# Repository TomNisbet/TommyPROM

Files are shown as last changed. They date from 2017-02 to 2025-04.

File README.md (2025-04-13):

# TommyPROM - An Arduino-based EEPROM programmer

This is a simple EEPROM programmer and reader that can be assembled using an Arduino and a
few additional parts.  The original code was specific to the 28C256 32Kx8 EEPROM, but it
has been extended to also support SST39SF040 Flash, many other EEPROMs and flash, and even
Intel 8755A EPROMS.

See the [documentation pages](https://tomnisbet.github.io/TommyPROM/) for the full
documentation with software, schematics, and troubleshooting tips.

Features include:
* Simple hardware design that can be assembled on a breadboard.
* ROM images transfers using XMODEM - no special host client needed.
* Support for fast block EEPROM writes - a 32K EEPROM will program in just a few seconds.
* Optimized code that supports the timing requirements needed to unlock the 28C series
[Software Protection Algorithm](https://tomnisbet.github.io/TommyPROM/docs/28C256-notes).
* Modular software design to easily support other EEPROM and EPROM families.

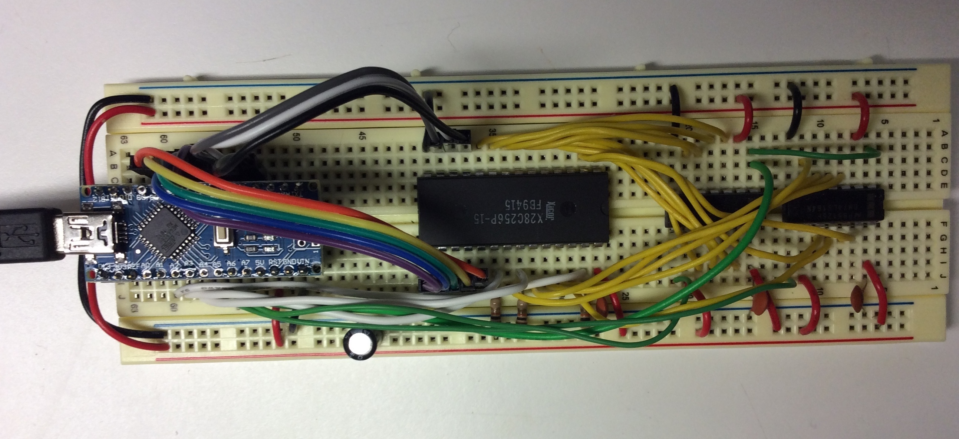
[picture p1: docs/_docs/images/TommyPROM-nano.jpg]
TommyPROM Nano Hardware


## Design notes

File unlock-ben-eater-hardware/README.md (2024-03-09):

# Unlock Ben Eater Hardware

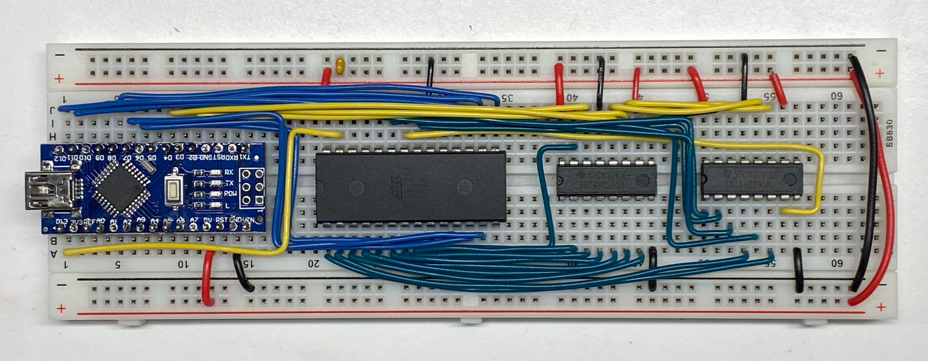
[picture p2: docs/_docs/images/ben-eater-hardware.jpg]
Ben Eater EEPROM Programmer


Utility to unlock 28C256 Software Data Protection (SDP) for the
[Ben Eater EEPROM](https://github.com/beneater/eeprom-programmer)
programmer design.  This hardware is similar to the TommyPROM hardware, but it uses
different shift register chips and different pin assignments.

To meet the 
[timing requirements of the SDP unlock](https://tomnisbet.github.io/TommyPROM/docs/28C256-notes), 
this code uses direct port writes
to set and read values on the data bus.  It will work with Arduino Uno and Nano hardware,
but would require changes for other platforms.

**NOTE** that this sketch **will not** work on TommyPROM hardware.  It is included here
to help people with locked chips who are using the Ben Eater design.

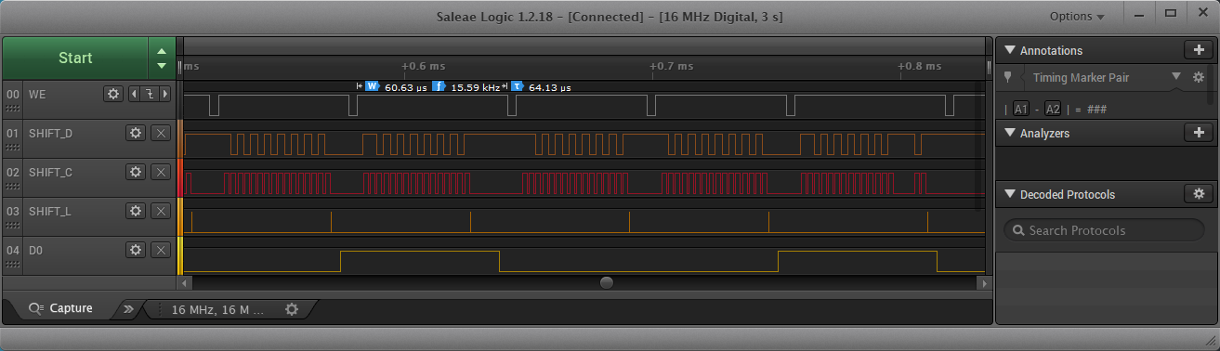
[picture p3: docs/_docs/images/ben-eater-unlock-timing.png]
Unlock timing with Ben Eater Hardware


The timing trace shows the tBLC for the bytes of the unlock sequence within 65us, well
within the required 150us in the datasheet.

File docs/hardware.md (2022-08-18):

---
title: Hardware Design
description: "TommyPROM Arduino 28C256 programmer hardware design"
has_children: false
nav_order: 20
---

# Hardware Design

## Basic Hardware Version

The hardware uses an Arduino to write data and to toggle control lines with the
appropriate timing to access the PROM.  A pair of 74LS164 serial to parallel shift
registers latch the address lines.  Use of the shift registers allows the Arduino to
control up to 16 address lines using only 3 output ports. This design will read and
program the 28C series chips and can read most other parallel ROM chip families.

The basic circuit is as follows:
* Pins D2..D9 are wired to the data lines on the target PROM.
* Pins A0..A2 are wired to the WE, CE, and OE control lines on the target PROM.
* Pins A3..A5 control shift registers to produce the address lines.
* Pins D10..D12 control A<sub>16</sub>..A<sub>18</sub> for chips larger than 64K bytes.

Note that the existing design uses 74LS164 shift registers, but another 8-bit parallel out
shift register, like the 74LS595, can be used instead with some pin changes.  See the
[74LS595 Shift Registers](#74ls595-shift-registers) section below for details.

The two shift registers can produce a sixteen bit address, although the 28C256 only needs
15 addresses. Chips larger than 64K are supported by using the shift registers for
A<sub>0</sub>..A<sub>15</sub> and connecting Arduino pins D10..D12 to the chip's
A<sub>16</sub>..A<sub>18</sub>

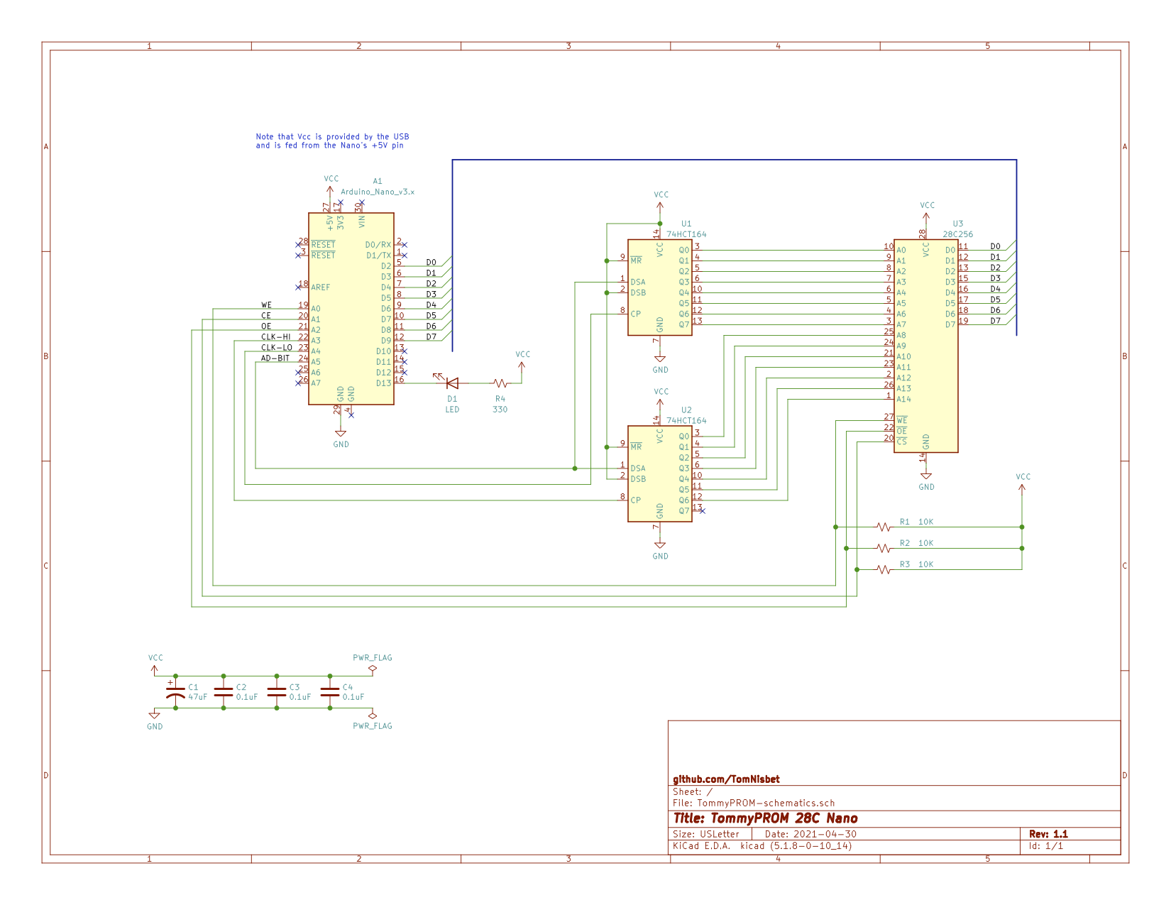
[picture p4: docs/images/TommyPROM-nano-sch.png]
TommyPROM Nano Schematic


## 74LS595 Shift Registers

When using the [74LS595](images/TommyPROM-595.jpg) instead of the 74LS164, there is
an additional output latch that is pulsed to put the contents of the shift register on the
output lines.  The code supports the 164s or the 595s by default.  No code changes are
needed to use either version of the shift register hardware.

The table below shows the connections when using either the 74LS164 or the 74LS595 for the
address shift registers.  USR refers to the Upper Shift Register
(A<sub>8</sub>..A<sub>15</sub>) and LSR refers to the Lower Shift Register
(A<sub>0</sub>..A<sub>7</sub>).

|Arduino |74LS164 |74LS595|
|:---: |:---: |:---: |
|A0 |ROM WE |ROM WE|
|A1 |ROM CE |ROM CE|
|A2 |ROM OE |ROM OE|
|A3 |USR CLK |USR SRCLK|
|A4 |LSR CLK |LSR SRCLK|
|A5<sup>1</sup> |LSR+USR A |LSR+USR SER|
|D2..D9 |ROM D<sub>0</sub>..D<sub>7</sub>  |ROM D<sub>0</sub>..D<sub>7</sub>  |
|D10..D12<sup>2</sup>|ROM A<sub>16</sub>..A<sub>18</sub>|ROM A<sub>16</sub>..A<sub>18</sub>|
|D13<sup>3</sup> |-- |LSR+USR RCLK|

Notes:
1. The data pin on A5 is connected to both the Upper Shift Register (USR) and the Lower
Shift Register (LSR).
2. The upper address lines are not needed for 28C64 and 28C256 chips, but are used for
larger chips like the 27C040.
3. The D13 pin controls the output register on the '595 shift registers.  This pin is not
connected when using the 74LS164.

Note that the 74LS595s have two additional pins that need to be connected.  
* An output enable pin, labeled as either G or OE in the datasheet,  must be tied LOW for
both chips or else they will not produce any signal on their output lines.
* A reset pin, labeled as RESET or SRCLR, must be tied HIGH for both chips or else the
shift registers will be held in a reset state.

## Ben Eater EEPROM Programmer

If you are here because you built the [Ben Eater EEPROM
Programmer](https://github.com/beneater/eeprom-programmer), note that the designs are
similar, but the TommyPROM code will not run on that hardware without some significant
changes.  If you just need to unlock the Software Data Protection (SDP) on a chip, then
see the
[unlock-ben-eater-hardware sketch](https://github.com/TomNisbet/TommyPROM/tree/master/unlock-ben-eater-hardware)
for a solution.  That sketch is purpose-built to run on the Ben Eater hardware directly
and it **will not work** with the TommyPROM hardware.

If you want the functionality of the TommyPROM software on the Ben Eater hardware, the
easiest path is probably to modify the hardware to match the TommyPROM software rather
than trying to change the pin assignments in software.  There are a few reasons for this:

* The Ben Eater hardware uses D13 to control the ROM's Write Enable pin and it ties the
Chip Enable pin to always be active.  The D13 pin is connected to the Arduino's built-in
LED, which blinks at boot.  This means that the chip is likely writing some random data at
boot time.  This isn't a problem for the Ben Eater sketches, because they always write
their own data to the chip anyway.  One use of TommyPROM is to just read data from a chip,
so a random write on boot would be bad.
* The OE pin is controlled by the Address shift registers.  This doesn't work well with
the modular architecture of TommyPROM and it definitely would not work with 74LS164s
because it would toggle the OE pin as new addresses are shifted in.
* The direct port write software is a bit complicated and is more difficult to modify than
just renaming a few pin #defines.  This was done for performance reasons, particularly
for the SDP timing, but it means that the code is not easy to change.

Changing the hardware is fairly straightforward.  The data lines move 3 pins from D5..D12
down to D2..D9.  Most of the ROM and shift register control lines move over to the A0..A5
pins.  The upper shift register is controlled directly from the Arduino instead of being
connected to the overflow of the lower shift register.  All of the connections are in the
chart in the section above.

## Intel 8755A Hardware Version

The Intel 8755A uses a multiplexed data and address bus, plus 3 additional address lines.
Most Arduino hardware has enough pins to support this directly, so no additional hardware
is needed for addressing. An Arduino pin is also used to drive the ALE latch pin.

The 8755A requires the Vdd pin to be be switched between 5V and 25V during the programming
of each byte. A simple transistor circuit is used for this. No voltage regulator circuit
is present here for the programming voltage. Because this is designed as a quickly
assembled hardware design, a triple output bench supply was used to provide the 25.5V,
5.5V and 5V outputs.

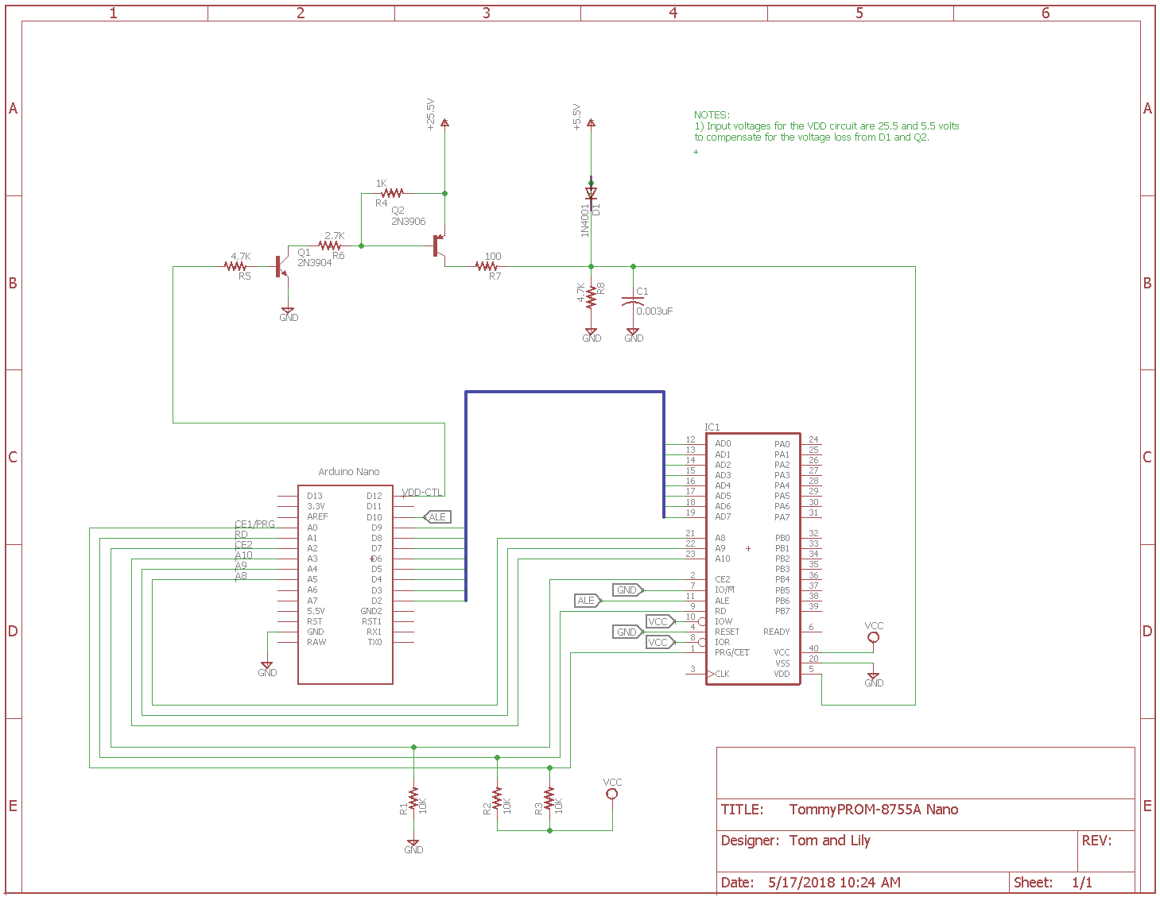
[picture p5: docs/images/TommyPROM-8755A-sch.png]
TommyPROM Nano Schematic


Eagle-format schematics can be downloaded from the
[hardware project page](https://github.com/TomNisbet/TommyPROM/tree/master/hardware).

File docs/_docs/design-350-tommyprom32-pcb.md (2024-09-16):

---
title: TommyPROM32 PCB
permalink: /docs/tommyprom32-pcb
exerpt: "TommyPROM32 Printed Circuit Board"
---

## TommyPROM32

The TommyPROM32 PCB supports 32-pin and smaller EEPROM and Flash chips. The board can be easily configured for many 32, 28, or 24 pin chips or used in its default setup for SST39SF devices.  The board has a set of headers that allow any of the signals to the target chip to be re-routed.

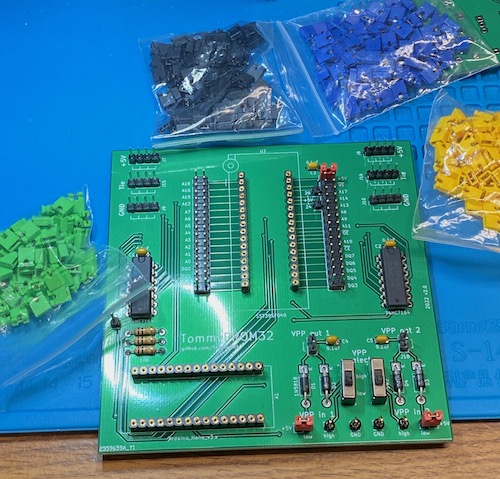
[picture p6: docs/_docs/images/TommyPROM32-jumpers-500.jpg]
TommyPROM32 PCB


The default configuration and labels, with just jumper shunts (jumper caps) installed, is wired for the SST39SF0x0 chips.

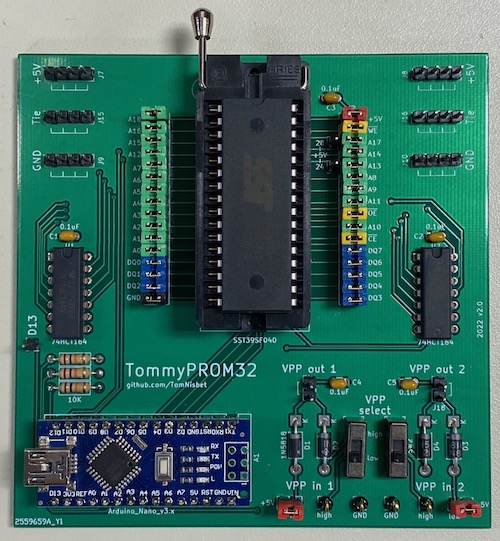
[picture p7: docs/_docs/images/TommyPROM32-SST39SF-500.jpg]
TommyPROM32 with SST39SF010


Many other chips, particularly if they follow JEDEC standards, can be supported by removing shunts and adding just a few jumper wires.

If the board is only being used with 5V chips or used to read (but not program) other chips, then the Vpp switches, diodes, and other components on the lower right side of the board do not need to be installed.

There are power pins in place to support 28-pin and 24-pin chips with a shunt to the correct _VCC_ pin.  The photo below shows the 28C256 with a power jumper on pin 28, the _WE_ signal moved down to pin 27, and the _A14_ signal moved from pin 27 to pin 1.

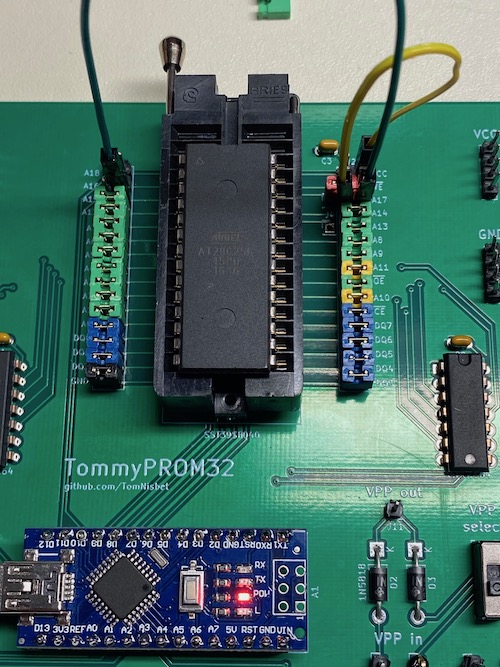
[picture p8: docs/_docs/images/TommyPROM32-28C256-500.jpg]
TommyPROM32 with 28-pin 28C256


## Vpp Power Selection Examples

Two power inputs and switches are provided to support older flash and EEPROM chips that need higher programming voltages.  Many of these chips just need a higher voltage, like 12V, applied to the VPP pin continuously during the programing and verification cycle.  In normal operation, the 5V _VCC_ signal is applied to the _VPP_ pin.  The board has VPP inputs for two voltages.  Applying 12V to _VPP In High_ and 5V to _VPP In Low_ lets the VPP output be switched between these two voltages using a manual slide switch for programming.

Note that some of the photos below show the initial version of the TommyPROM32 board that only contained a single switchable voltage.  The version 2.0 boards added a second switchable Vpp voltage section with multiple _VPP Output_ pins.  The _5V_ and _Vpp in low_ pins are now adjacent so that a wire is not needed for the common case where Vpp low is set to 5V.  There are also some general-purpose 5v, GND, and interconnect pins.

### W27C257 

The photo below shows the W27C257 set up for programming.  The _VPP in Low_ signal is connected to _VCC_ and the _VPP in High_ signal is using 12V from an external power supply. The _VPP Out_ signal is connected to the chip's VPP on pin 1.  The chip is in programming mode when the slide switch is set to the _High_ position and is in read mode when in the _Low_ position.

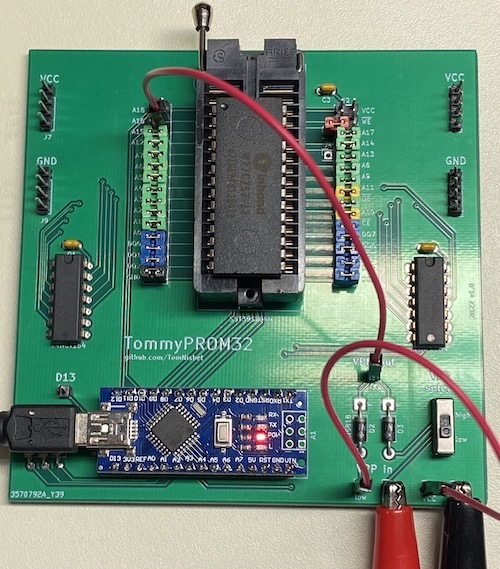
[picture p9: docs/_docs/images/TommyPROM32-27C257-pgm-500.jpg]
TommyPROM32 W27C257 programming


To erase the W27C257 chip, the external power supply is providing 14V and the _VPP Out_ is connected to the chip's _VPP_ and _A9_ pins.  

Note the the top picture showed the version 1.0 board and a jumper wire was needed to connect +5V to the _Vpp in low_ pin.  The newer board, shown below, has a jumper cap to make this connection, so no additional wire is needed.

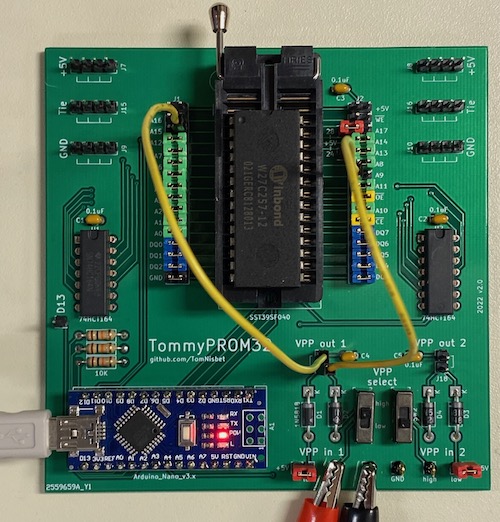
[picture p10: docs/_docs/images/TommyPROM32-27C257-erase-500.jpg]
TommyPROM32 W27C257 erase


### M27C256

The M27C256 chip needs two voltages for programming.  The external power supply is providing 12.75V to _VPP Out 1_ for the the chip's _Vpp_ pin.  The power supply is also providing 6.25V to _VPP Out 2_ for the chips _Vcc_ pin.  Note the the chip's _Vcc_ is no longer connected to the system +5V.  The two _VPP Select_ switches should be in the _low_ position for normal read operation and in the _high_ position for programming.

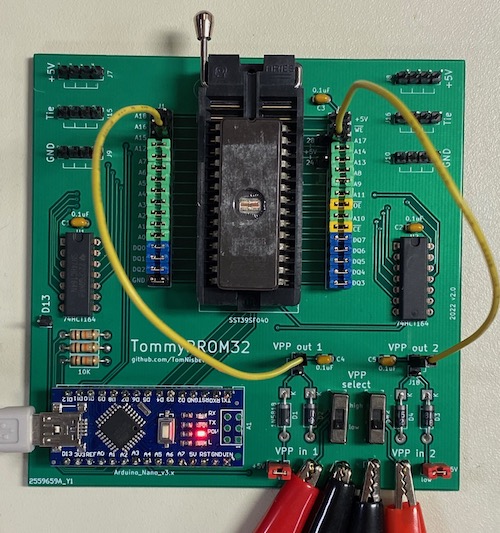
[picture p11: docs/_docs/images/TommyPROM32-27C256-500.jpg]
TommyPROM32 M27C256 programming


## High Voltage Pulses

For chips that require a high voltage _Vpp_ pulse during programming, some external switching circuitry will be needed to allow the Arduino to control the VPP voltage.  There is a header connected to the unused _D13_ pin that can support this.  See the [Intel 8755 version of the hardware](hardware/#intel-8755a-hardware-version) for an example of voltage switching by TommyPROM.

## Schematics and Gerbers

The [TomyPROM32 KiCad design files](https://github.com/TomNisbet/TommyPROM/tree/master/schematics)
are in the project repo.

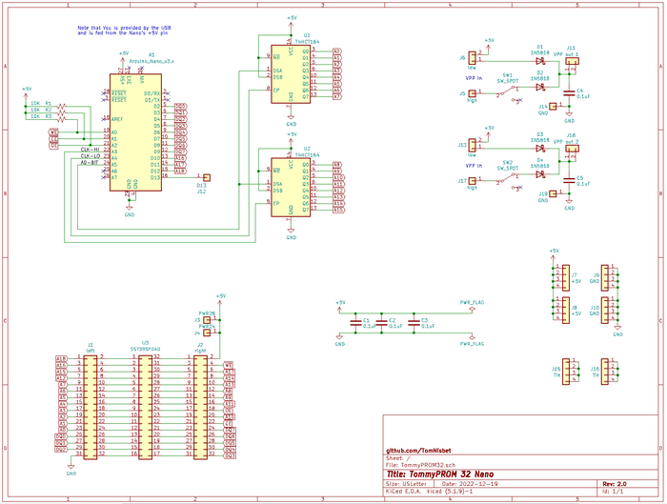
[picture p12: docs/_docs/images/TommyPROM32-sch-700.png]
TommyPROM32 schematic


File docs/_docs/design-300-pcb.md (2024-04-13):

---
title: Printed Circuit Boards
permalink: /docs/pcb
exerpt: "Printed Circuit Boards"
---

Although TommyPROM was originally designed as a one-off programmer to be used on a breadboard, there are now some PCB versions.  The original TommyPROM PCB for 28C256 chips is described here, and the [TommyPROM32 PCB](tommyprom32-pcb), for handling a variety of chips, has its own page.

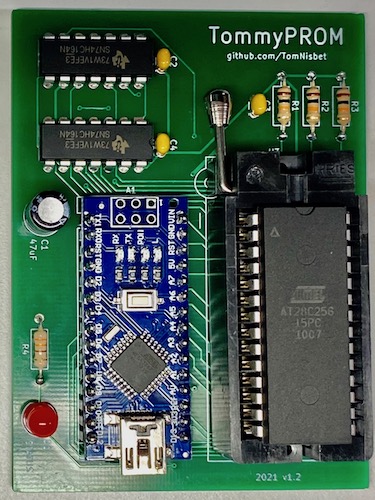
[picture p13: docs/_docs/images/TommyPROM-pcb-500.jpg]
TommyPROM PCB
TommyPROM PCB

## 28C256 PCB

A PCB version for the 28C256 and 28C64 chips was built to support a SAP-1 TTL breadboard
computer.  This project required a lot of burns for its  microcode and the PCB version
with the ZIF socket was much quicker than prying the chips out of a breadboard without
disturbing any of the wires.

The [KiCad design files](https://github.com/TomNisbet/TommyPROM/tree/master/schematics)
are in the project repo.

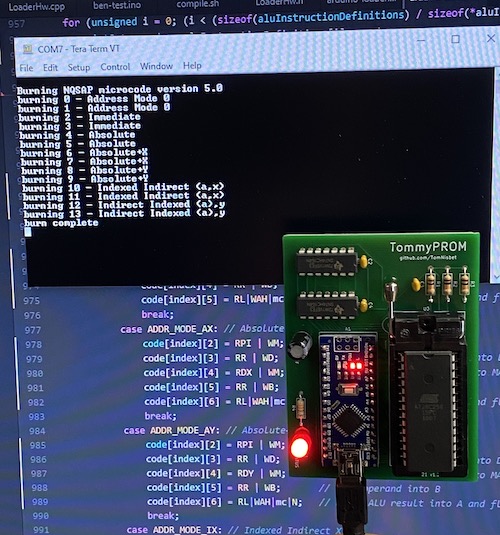
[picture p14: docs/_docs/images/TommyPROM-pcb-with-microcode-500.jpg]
TommyPROM PCB


TommyPROM schematic

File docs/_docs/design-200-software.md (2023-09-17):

---
title: "Software Design"
permalink: /docs/software
exerpt: "TommyPROM Arduino EEPROM programmer software design"
---

The software is designed around several major blocks and classes.  The code has been
broken out into individual files to make it easy to extend the hardware support to
additional EPROM and EEPROM families. See the
[Adding Chip Families](extending) page for details on suggested hardware and software
changes needed.

## CommandStatus class

The CommandStatus class stores the execution status of the previous command.  It allows
the status to be saved (and recalled using the / command) instead of just printing the
status at the completion of the command.  This was important for debugging XMODEM
problems, because the error messages would get eaten as part of the transfer.  The class
has utility beyond XMODEM because it includes formatting that relieves each command from
having to build parameterized error messages with multiple print calls.

## Xmodem class

The Xmodem class implements the communications protocols needed to do XMODEM or XMODEM-CRC
transmit and receive.  It calls directly into the PROM read and write code, so the
complete files are never stored during the transfer.

## CLI code and command implementation

This code parses input commands and parameters and executes the commands.

A compile-time switch in Configure.h enables additional debug commands that are not needed
in normal operation, but are very useful to verify proper operation of the hardware.

## PromDevice class

The PromDevice class and its subclasses encapsulate all of the communication between the
Arduino and the target PROM device.

To meet the timing requirements for block writes and 28C chip unlocking, the PromDevice
class accesses the shift registers and data bus using direct port writes instead of 8
individual pin accesses.  This greatly increases performance, but it makes the code
dependent on the particular flavor of Arduino being used.  The code supports the Uno,
Nano, and Boarduino versions of Arduino hardware or any other variant that uses that same
mapping of ATMega ports to I/O pins.  To support a different Arduino board, either change
the pins used to match the mapping in the software, or change the hardware-specific code
in PromDevice.cpp and PromAddressDriver.cpp.

The PromDevice class contains common code used by all devices, including the block write
code that will break a large write request into a set of properly-aligned smaller blocks
for devices that support block writing, or a sequence of individual byte writes for
devices that do not.

Subclasses of the PromDevice class provide the device-specific code. To accommodate the
limited memory footprint of the Arduino, only a single subclass will be compiled into the
final code. This is controlled via switches in the Configure.h file.

The device-specific subclasses are described below.  Each class provides pin definitions,
byte read, byte burn, and optional block burn code that is specific to the timing of the
chip. They also supply a SetAddress method that either calls the built-in code for the
shift register hardware or provides device-specific address code.

### PromDevice28C class

Although the existing code is specific to the 28C256, the constructor has parameters that
easily support other chips.  The current design has been used to read other chips,
including 2764 and 29c040 EPROMs.

The 28C code supports fast block writes, allowing a 32K byte chip to be programmed in just
a few seconds.

### PromDevice8755A class

The PromDevice8755A class provides the byte read and byte write code, as well as
SetAddress code that accommodates the ALE used on this chip.  The byte write code controls
the Vdd switching hardware that toggles the Vdd pin between the normal 5V value and the
25V programming pulse.

### PromAddressDriver class

Although not actually a subclass of PromDevice, this contains the code to drive the shift
registers that provide the address lines. If this hardware is used, the PromDeviceXX class
can call this code to implement the SetAddress methods.

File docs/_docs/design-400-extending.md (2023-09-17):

---
title: "Adding New Chip Families"
permalink: /docs/extending
exerpt: "Extending TommyPROM to support new EEPROM, EPROM, and Flash chip families"
---

## Hardware

There are currently two hardware flavors - one for 28C series EEPROMs and one specifically
for the Intel 8255A UV EPROM. There is also a work-in-progress version for 27C series
chips.

The 8755A chip uses a multiplexed set of address and data lines that are directly driven
by the Arduino. Most other chips will not use this addressing method. The 8755A design
also includes a circuit to switch the programming voltage under software control.  This
may be useful for other chips that use non-5V programming voltages, although many of these
chips, like the 27 series EPROMS, have a programming voltage that remains on for the
entire write and verify cycle. It may be easier to simply switch the programming voltage
manually for these chips.

The basic hardware design, used for the 28C EEPROMs, is much more adaptable to additional
chip families. This design uses two shift registers to create 16 dedicated address lines
from only 3 Arduino pins. This design, plus manual switching of the program voltage, would
be very adaptable to EPROMs like the 2716, 2764, 27040, and 272001. The hardware has
already been used with these chips for read-only operations.

The current design can directly address chips as large as 512K bytes, like the 29C040. Use
the shift registers for A<sub>0</sub>..A<sub>15</sub> and wire Arduino pins D10..D12 to
A<sub>16</sub>..A<sub>18</sub> on the target chip.

# Software

The software design is modular, allowing easy extension for chips with different
programming algorithms.  A new class can be added for each new chip family. This class
will include code for byte reads, byte writes, and optional block writes if the chip
supports it.  All of the chip-specific code will be in this single class.

The basic steps to support a new chip are as follows:
* Create or copy an existing PromDeviceXX class to create a new .cpp and .h file for the
chip-specific code.
* Define the pin assignments and implement the chip-specific setAddress, readByte, and
burnByte code in the new files. The setAddress code can call the PromAddressDriver code if
the shift register address hardware is used.
* If supported, also add chip-specific burnBlock code.
* Be sure that the new files have unique #if defined code that matches the class name.
* Edit Configure.h to add the conditional code includes the new PromDevice subclass.
* Edit TommyPROM.ino to add the conditional code that declares the new device.

Note that after files are added or renamed in the TommyPROM directory, the project needs
to be reopened in Arduino IDE to get the changes.

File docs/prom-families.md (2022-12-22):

---
title: PROM Types
description: "PROM types supported by TommyPROM - EPROM, EEPROM, Flash"
has_children: false
nav_order: 40
---

TommyPROM can be used to read and write several different types of PROM chips.  Due to
differences in the technologies of these chips, some features of TommyPROM may work
differently or may not be applicable at all.  The standard code can read most types of
PROM, even if there is no specific software support for them.

# PROM Types

## EPROM - Erasable Programmable Read-only Memory

EPROMs can be written once, but must then be erased by exposing them to UV light for
several minutes.  They are usually easily read by TommyPROM, but there is limited
support for programming.

## EEPROM - Electrically Erasable Programmable Read-only Memory

EEPROMs are the easiest PROMs to use.  Modern EEPROMs usually can be erased and reprogrammed
electrically at the individual byte level.  This makes them appear similar to a slower
static RAM.  All of the interactive features of TommyPROM work well with EEPROMs.  Due
to their complexity, EEPROMs typically come in smaller sizes than other technologies.
The largest EEPROM in the 28C family is 32K bytes.  Some older EEPROMs cannot be reprogrammed at the individual byte level and are instead bulk erased before a new write
operation.  Programming and erasing for these chips usually requires voltages higher than 5V.

## Flash ROM

Flash is similar to EEPROM, in that it can be electrically erased and reprogrammed. Unlike
EEPROMs, Flash cannot erase single bytes individually.  Instead, the chip is arranged into
memory blocks called sectors.  The programmer can erase individual sectors or, sometimes,
the entire chip.  Some chip families require an explicit erase command and others initiate
an erase at the start of a programming operation.

Most of the features of TommyPROM are supported for Flash, but some operations that would
do multiple writes to the same sector work differently.

## OTP ROM - One-time Programmable ROM

One-time Programmable (OTP) ROM is written once, either at the factory or in the field.
These chips cannot be erased and re-written, but they can be read by TommyPROM.  Interesting
trivia - some of the field-programmable OTPs are just EPROMs packaged without the erase
window.

# Supported Chip Families

## 28C EEPROM

The 28C series EEPROMs, specifically the 28C256, are the original chips that TommyPROM
supported.  As a result, these have the best support, with all of the interactive features
of the command line.  In addition the basic read and write operations, there are also
commands to enable and disable the [Software Data protection (SDP)](../28C256-notes)
features of 28C chips.  There is also support for the fast block write mode of these
chips, allowing a 32KB chip to be programmed in just a few seconds.

## 27C EPROM

The 27C EPROMs use a variety of programming algorithms.  Code exists for some of these,
but very few of the chips have been tested.

Most, if not all, 27C series chips are not 5V only and require a higher voltage to program
them.  Some need the voltage constantly applied while programming and others use high
voltage pulses for each byte.  For constant voltage chips, it is probably easiest to just
add an external power supply and manually assert the voltage before starting a write.  For
those with switched voltages, some elements of the 8755 hardware may be leveraged to build
a version of the programer that supports these chips.

## Atmel SST39FS Flash

TommyPROM has a driver for Atmel SST39FS NOR flash chips.  This driver replaces the 28C
driver at compile time.  See configure.h to enable a different driver.

The SST39FS chips use fixed 4KB sectors that must be manually erased before a new program
operation, but the code manages this transparently.  Whenever a write is started to a new
segment, the driver first initiates an erase of that sector. A second write to the same
sector will not cause an erase, so it is possible to write to a segment multiple times
with no additional steps as long as the writes are to different parts of the sector.  For
example, 256 bytes could be written to the start of a sector from one file and then 512
bytes could be written to the end of the sector from another file.

Writing data that spans multiple sectors also works with no additional steps.  When
a sector boundary is crossed, the new sector is erased and set as the current sector.

The SST39FS driver supports a manual erase from the command line using the E command.
This is only needed if data will be rewritten to the same location after a previous write
to that sector.

There is also a driver for the SST28SF0x0 SuperFlash chips.  These are an earlier version
of the 39SF chips, using 256-byte sectors.  The 28SF and 39SF chips are pin compatible,
but use different command sets for programming and erasing.  For read-only applications,
they should be identical, although the 28SF are slower.

All programming and erase operations for both the 39SF and 28SF chips require only a
single 5V power supply.

## Misc Flash

#### 29C Series

The 29C series flash chips are similar to the 28C EEPROMs, except they must erase an
entire sector before programming new data.  The start of a block write operation causes
the target sector to be erased before the block is written.  If the entire sector is not
written in one operation, there is no way to write additional data to the sector because
a new block write will erase the sector again.

The write algorithm for the 29C chips is similar to 28C, so it is possible to use that
code to write these chips as well with some restrictions.  All 29C010 and 29C020 chips
that have been encountered use a sector size of either 64 bytes or 128 bytes.  A single
XModem packet holds 128 bytes of data, so these chips will program without issue.

The 28C040 chips from some manufacturers use a 256 byte sector.  This will not currently
work with TommyPROM, because each of the 128 byte XModem packets received will do its own
block write.  The first write will erase 256 bytes and then write data into the first half
of the sector.  The second write will then erase the data just written and then write 128
bytes into the second half of the sector.  To fix this, the code would need to be modified
to keep 256 bytes of data from two packets before initiating a block write.

#### 28F Series

The 28F series flash do not have sectors. The entire chip must be erased before writing
new data.  Data is written a byte at a time using a command register to control the
programming.  **These chips require a 12V programming voltage that must be present during
the programming or erase operations**.  TommyPROM does not currently support 28F chips,
but it would not be difficult to write a driver.  The default 28C driver will read 28F
chips.

#### 29F Series

The 29F series flash have sectors that must be explicitly erased before writing new
data.  Data is written a byte at a time using a command register to control the
programming.  TommyPROM does not currently support 29F chips, but it would not be
difficult to write a driver.  The default 28C driver will read 29F chips.

## Intel 8755/8355 EPROM

TommyPROM has a driver for Intel 8755 EPROMs.  This driver replaces the 28C driver at
compile time.  See configure.h to enable a different driver.  This driver will also read
Intel 8355 OTP EPROMs.  Also note that the TommyPROM hardware for the 8755 is drastically
different from the other versions.

The Intel 8755 is a peripheral chip designed for 8085 systems.  It is a 40 pin device that
contains a 2KB EPROM plus two general-purpose I/O ports.  The 8355 is a one-time
programmable version of the 8755.  The 8755 requires a 25V programming pulse for each byte
to be written.  

A new hardware build was created to support the 8755 chips.  Because the 8755 has a multiplexed data and address bus, the usual shift registers are not used for addressing.
The chip only needs 8 connects that are shared for address and data, plus three dedicated
address lines.  The Arduino has enough pins to drive all of these directly, without the
need for shift registers to create address lines.

The 8755 build of TommyPROM also has a circuit to control the 25V programming pulses.

# Verified Chips

|Model |Manufacturer |Type |Module |Notes|
|:--- |:--- |:--- |:--- |:--- |
|AT28C256  |Atmel, others|EEPROM |28C |Fully supported|
|SST39SF040|Microchip |Flash  |SST39SF|All SST39SF0x0 supported|
|SST28SF040|SST |Flash  |SST39SF|All SST28SF0x0 supported|
|SST27SF020|SST |Flash  |27 |12V continuous for pgm/erase|
|W27C257 |Winbond |EEPROM |27 |Continual 12V or 14V for program/erase|
|AT29C010  |Atmel |Flash  |28C |Only with 128 byte or less sector size|
|8755A |Intel |EPROM  |8755A  |Requires 25V pulses to program|

#### 28C256

Tested with chips from several manufacturers including Atmel AT28C256, Xicor X28C256, and
CSI CAT28C256.  Also works with the smaller 28C64 and 28C16 chips, although some
parameters may need to be adjusted. Some smaller chips do not support SDP, so the _Lock_
and _Unlock_ commands have no effect. Check the datasheet to see if block writes are
supported.  Some 28C16s use a 16 byte block instead of the 64 bytes used on the 28C256.
It is always safe to just set the block size parameter to zero when declaring the chip to
disable block writes altogether.

The 28C chips do not need to be explicitly erased.  Each memory cell is automatically
erased during a write operation, so they are more similar to a slow RAM than to other
PROMs.

#### SST39SF040

The SST39SF driver supports all chips in this family, so the 040, 020, and 010 chips can
be all be used with no code change.  These chips use sectors that must be erased before
writing new data.  The code keeps track of the current sector and will automatically do
an erase operation whenever a write starts to a new sector.  The _Erase_ command is
supported, but is not needed unless overwriting new data to a single sector.

#### SST28SF040

This is an earlier version of the SST39SF series chips.  They are pin compatible with the
39SF series, but use a different command set for programming.  Unlike the 39SF, these
flash chips support software data protection.  The _Lock_ and _Unlock_ commands can be
used to enable and disable SDP from the command line.

#### SST27SF020

The Silicon Storage SST27SF0x0 are programmed similarly to the 27C257 in that a constant
voltage is applied for program and erase operations.  Unlike the 27C257, these have a
dedicated WE pin that controls programming and erasing.  Another difference is that they
do not have a verify operation to read back the programmed data.

These Flash chips have a _VPP_ pin that needs a constant 12V during programming. Unlike
the newer 28C EEPROMs, these chips do not automatically erase before writing to a
location. Instead, the entire chip is erased by applying 12V to _VPP_ and _A9_ and then
pulsing _WE_.

#### W27C257 and W27C512

The Winbond W27C257 and W27E257 appear to be identical 32Kx8 EEPROMs.  The 27C version
has been tested.  The Winbond W27C512 is a 64Kx8 EEPROM with no dedicated _VPP_ pin.

The 257 EEPROMs have a _VPP_ pin that needs a constant 12V during programming. Unlike the
newer 28C EEPROMs, these chips do not automatically erase before writing to a location.
Instead, the entire chip is erased by applying 14V to _VPP_ and _A9_ and then pulsing
_CE_.

Unlike the 257 chips, the W27C512 does not have a dedicated pin for the programming
voltage and instead uses the OE pin to place the chip in programming mode.  The verify
operation requires that the OE pin be switched to _LOW_ and there is no hardware support
for this, so the current code supports the 512 chip by doing a single write cycle with no
verify.

Because the chips use a constant high voltage for programming instead of a pulse, an
external power supply and two diodes can be used to supply either 5V or 12V to the
pins for programming and erasing.

Note that the W27x257 chip are almost a drop-in replacement for the 28C256.  The _WE_,
_VPP_, and _A14_ pins are the only differences.  For reading, the _VPP_ pin should be
connected to 5V.

#### 29C010

The 29C0x0 chips are 5V sectored flash chips.  They automatically erase a sector at the
start of a new write, so they can be used with the default 28C code.

Note that some versions of the 29C040 use a 256 byte sector size.  This will not work
with the TommyPROM code because the XModem transfer buffer is only 128 bytes.  Code
changes would be needed to buffer up two packets of data into a single write operation
for chips with the 256 byte buffer.

# Chips to be Tested

|Model |Manufacturer |Type |Module |Notes|
|:--- |:--- |:--- |:--- |:--- |
|M27C4001  |ST Micro |EEPROM | |VCC=6.5V, VPP=12.75V to pgm|
|W27C512 |Winbond |EEPROM |27 |Continual 12V or 14V for program/erase,VPP on OE|

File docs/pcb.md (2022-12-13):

---
title: Printed Circuit Board
description: "TommyPROM Arduino 28C256 programmer PCB"
has_children: false
nav_order: 35
---

# Printed Circuit Board

Although it was originally designed as a one-off programmer to be used on a breadboard,
there are now some PCB versions.

## 28C256 PCB

A PCB version for the 28C256 and 28C64 chips was built to support a SAP-1 TTL breadboard
computer.  This project required a lot of burns for its  microcode and the PCB version
with the ZIF socket was much quicker than prying the chips out of a breadboard without
disturbing any of the wires.

The [KiCad design files](https://github.com/TomNisbet/TommyPROM/tree/master/schematics)
are in the project repo.

TommyPROM PCB

## TommyPROM32

TommyPROM32 was built to support SST39SF0x0 and other 32-pin EEPROM and Flash chips. While
providing a stable platform for the SST39SF chips, the board can serve as a test bed for
other chips as well.  It uses a set of headers that allow any of the signals to the target
chip to be re-routed.  The default configuration, with just jumper shunts installed, is
wired for the SST39SF0x0 chips.

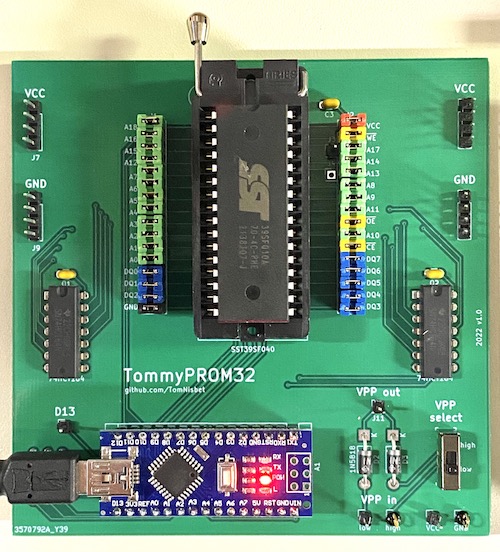
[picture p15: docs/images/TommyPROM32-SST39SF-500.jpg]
TommyPROM PCB


Many other chips, particularly if they follow JEDEC standards, can be supported by
removing shunts and adding just a few jumper wires.

Chips with fewer pins can also be supported.  There are power pins in place to support
28-pin and 24-pin chips with a shunt to the correct VCC pin.  The photo below shows the
28C256 with a power jumper on pin 28, the _WE_ signal moved down to pin 27, and the _A14_
signal moved from ping 27 to pin 1.

TommyPROM PCB

Power inputs and a switch are provided to support older flash and EEPROM chips that need
higher programming voltages.  Many of these chips just need a higher voltage, like 12V,
applied to the VPP pin continuously during the programing and verification cycle.  In
normal operation, the 5V VCC signal is applied to the VPP pin.  The board has VPP inputs
for two voltages.  Applying 12V to _VPP In High_ and 5V to _VPP In Low_ lets the VPP
output be switched between these two voltages using a manual slide switch for programming.

The photo below shows the WE27C257 set up for programming.  The _VPP in Low_ signal is
connected to _VCC_ and the _VPP in High_ signal is using 12V from an external power
supply. The _VPP Out_ signal is connected to the chip's VPP on pin 1.  The chip is in
programming mode when the slide switch is set to the _High_ position and is in read mode
when in the _Low_ position.

TommyPROM PCB

To erase the WE27C257 chip, the external power supply is providing 14V and the _VPP Out_
is connected to the chip's _VPP_ and _A9_ pins.  An external breadboard was needed to
allow the _VPP Out_ signal to be connected to multiple pins.  A new spin of the board is
planned with multiple _VPP Output_ pins and some general-purpose interconnect pins.

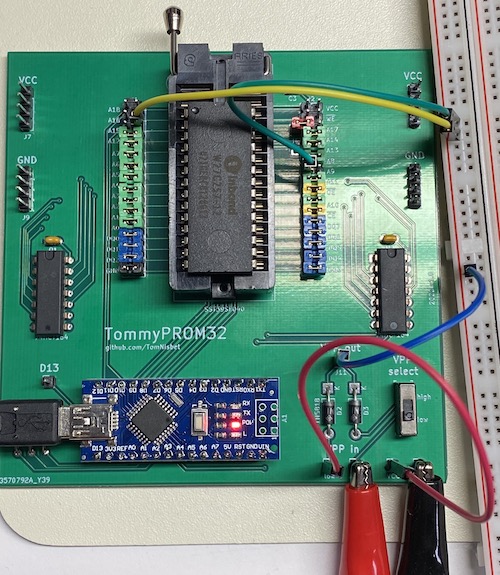
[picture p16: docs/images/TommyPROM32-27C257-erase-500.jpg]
TommyPROM PCB


For chips that require a high voltage VPP pulse during programming, some external
switching circuitry will be needed to allow the Arduino to control the VPP voltage.  There
is a header connected to the unused D13 pin that can support this.  See the
[Intel 8755 version of the hardware](../hardware/#intel-8755a-hardware-version) for an
example of voltage switching by TommyPROM.

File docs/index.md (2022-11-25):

---
title: Overview
description: "TommyPROM Arduino based programmer for 28C256 EEPROMs"
has_children: false
nav_order: 10
---

# TommyPROM - An Arduino-based EEPROM programmer

This is a simple EEPROM programmer and reader that can be assembled using an Arduino and a
few additional parts.  It has been successfully built using the Arduino UNO, Nano and
Boarduino models.

The original code was specific to the 28C256 32Kx8 EEPROM, but it has been extended to
also support SST39SF flash, 27C EPROMs, 29C flash and the Intel 8755A EPROMS.

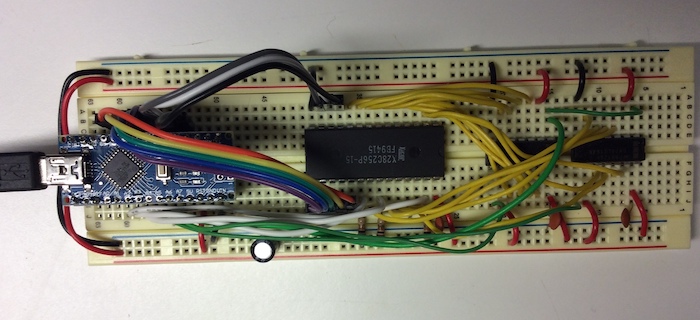
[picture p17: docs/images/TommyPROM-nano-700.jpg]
TommyPROM Nano Hardware


Features include:
* Simple hardware design that can be assembled on a breadboard.
* ROM images transfers using XMODEM - no special host client needed.
* Support for fast block EEPROM writes - a 32K EEPROM will program in just a few seconds.
* Optimized code that supports the timing requirements needed to unlock the 28C series [Software Data Protection](28C256-notes) Algorithm.
* Modular software design to easily support other EEPROM, flash, and EPROM families.
* Hardware support for 19 address lines, allowing the use of chips as large as 512KB, like the SST39SF040 and 29C040.

## Design

The 28C hardware and software design can be used with other 5V PROMS as well.  Many 5V
chips, including UV EPROMs such as the 2716, 2764, 27C2001 and 27C040, can be read, but
not written, with the basic hardware. Some pin changes may be needed to get the signals to
the correct pins on the device.  See the [Extending the design](extending) page for
details on suggested hardware and software changes needed to support new
[EPROM, flash,and EEPROM families](prom-families).

The PROM-specific code is modular and can be easily adapted to support additional devices.
There are currently drivers for 28C series EEPROMS, SST39SF flash, 27C EPROMs and the
Intel 8755A EPROM.

Some 29C series chips, like the 29C010 can be written with the 28C hardware and driver.
The 29C series only differs from the 28C in that the 29C chips erase and write an entire
sector at a time.  The 29C010 and some 29C020 chips use a 128 byte sector, which matches
the XModem buffer in the current code.  Other 29C020s and all 29C040s use a 256 byte
sector and cannot be written without code changes to buffer up an entire 256 byte block of
data before writing.

The [hardware](hardware) page has descriptions of the hardware designs and links to
schematics.  The [software](software) page has class definitions and more information on
the software design.

The project was inspired by the
[MEEPROMMER programmer](https://github.com/mkeller0815/MEEPROMMER).

## PCB Version

Although it was originally designed as a one-off programmer to be used on a breadboard,
there are now some PCB versions as well.  The [PCB](pcb) page has descriptions with links
to the KiCad schematics and Gerber files.

TommyPROM PCB

## Compiling

Open the TommyPROM.ino file in the Arduino IDE. It should automatically open the cpp and h
files as well. The default code programs 28C series chips using Arduino Nano hardware.  To
use this version, just compile and upload it to the Arduino.

**Note well** that this code has been optimized for the Aduino UNO and Nano hardware so
*that it can run quickly enough to meet 28C series chip timing requirements for SDP
*unlocking.  To use different Arduino hardware, like the Micro, the board-specific code in
*PromDevice.cpp and PromAddressDriver.cpp must be changed to match the port mappings
*between the ATmega chip and the Arduino I/O pins.

Because the Arduino has limited code and RAM space available, only one PROM driver is
compiled in at a time.  To change drivers, uncomment the desired PROM_IS_xx line in
Configure.h and  comment out the other choices.  The code to instantiate the driver is
near the top in TommyPROM.ino.  The change to Configure.h will automatically cause a
driver to be installed, but it may be necessary to modify the parameters for a specific
chip type.

## Operation

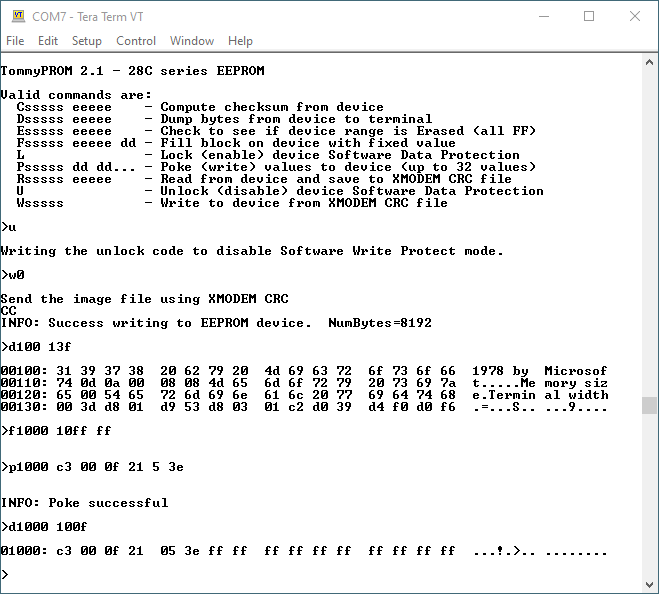
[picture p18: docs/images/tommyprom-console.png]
TommyPROM console screenshot


To use the programmer, connect the Arduino USB to the host computer and run a terminal
program, such as TeraTerm (Windows) or Minicom (Linux).  The Arduino development Serial
Monitor can also be used as a terminal initially, but it does not support XMODEM
transfers, so the READ and WRITE commands can't be used.

Disable both hardware and software flow control in the minicom settings for best results.

Set the terminal's serial parameters to 115200 baud, 8 bits, no parity, 1 stop bit to
match the Arduino.  Press the Enter key.  If the connection is successful, TommyPROM will
display a menu of options.

Most of the commands take a start address parameter, always entered as 1 to 5 hex
characters.  Leading zeros are not required. If needed, the end address parameter is also
in hex.  Parameters are separated by a space. For example, either of the commands:

    d0000 01ff
    d0 1ff

will dump memory from 0000H to 01ffH.  Note that commands and parameters can be entered in
uppercase or lowercase.

The R command is used to read from a PROM and save a binary image on the host.  The W
command receives a file from the host and writes (burns) it into the device.  The R
command needs a start and end address.  The W command determines the end address from the
received file size.

Once the READ or WRITE command is issued to the programmer, the transfer must
be started on the host program.

Note that previous versions of TommyPROM used the XMODEM-CRC protocol to complete the file
transfers for the READ and WRITE commands.  This did not work well with minicom and other
Linux programs that rely on the sz/rz commands.  Versions 2.5 and later of TommyPROM now
use basic XModem with the 8-bit checksum.  The XModem-CRC support is still available as a
compile-time option.  See [issue #19](https://github.com/TomNisbet/TommyPROM/issues/19)
for details.

The files used for READ and WRITE are simple binary images. This can be created directly
by [asm85](http://github.com/TomNisbet/asm85) or can be converted from S-record or Intel
HEX using an external utility.

## Troubleshooting

* Verify that the Arduino type you are using is a supported board or that its I/O port definitions match one of the supported boards.  Some other Arduino boards, like the
Duemilanove, appear to be compatible but have not been tested. Others, like the Micro,
have different port mappings and definitely will not work without software changes.
* If the code doesn't appear to be working, concentrate on the read operations first to
verify that the data and address paths are good.
* 28C series EEPROMS, like the X28C256, sometimes ship from the factory with Data
Protection enabled.  Use the UNLOCK command to disable this. See the
[28C256 Notes](28C256-notes) for more information.
* Re-check all hardware connections and verify the the control pins are going to the
Arduino pins that match the definitions in the code.
* This repo contains a standalone program called HardwareVerify that allows low-level
access to the address, data, and control lines through a menu-driven interface.  See the [troubleshooting](troubleshooting) section for more tips.

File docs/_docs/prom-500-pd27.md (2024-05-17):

---
title: PromDevice27
permalink: /docs/prom-device-27
exerpt: "TommyPROM support for 27 series EPROM - 2716, 2732, 2764, 27C128, etc"
---

The PromDevice27 driver supports Flash, EEPROM, and EPROM chips that use a variety of programming algorithms.  

Most, if not all, 27C series chips are not 5V-only and require a higher voltage to program or erase. This driver supports chips that need the voltage constantly applied while programming or erasing.  The programming voltages are provided by an external power supply and manually switched before starting a write or erase operation.  See the [TommyPROM32 hardware](tommyprom32-pcb) for a diode circuit that allows the programming voltage to be switched between Vcc and a higher voltage.  

Check the chip details below for the high voltage connections for a particular chip or consult your data sheet. Also note the warning in that section about issuing other commands while the programming voltage is asserted.

Chips that use high voltage pulses for each byte are not supported.  For those chips, some elements of the [8755A hardware](prom-device-8755) may be leveraged to build a version of the programmer that is able to provide high voltage pulses.

## Verified Chips

|Model |Manufacturer |Type |Module |Notes|
|:--- |:--- |:--- |:--- |:--- |
|[M27256](#m27256) |ST Micro |EPROM  |27 |VCC=6V, VPP=12.5V to pgm|
|[M27C256](#m27c256) |ST Micro |EPROM  |27 |VCC=6.5V, VPP=12.75V to pgm|
|[W27C257](#w27c257-w27e257-w27c512) |Winbond |EEPROM |27 |Continuous 12V or 14V for program/erase|
|[SST27SF020](#sst27sf020)|SST |Flash  |27 |12V continuous for pgm/erase|

## 27C and 27E Series EPROMs and Flash

*WARNING*: Some chips in this series use the _CE_ and _OE_ pins in non-standard ways when the high voltage is asserted on _VPP_.  Because the programming voltage is switched manually, care needs to be taken when using chips that pulse the _CE_ pin for programming. The programming code itself knows how to manage this, but other commands, like the DUMP command, will also toggle _CE_.  If the programming voltage is asserted, these other commands can inadvertently cause a write operation.  Be sure to assert the programming voltage, issue the needed write commands, and then remove the high voltage before issuing any additional commands that may corrupt the data.

### M27C256

The M27C256 is a 32Kx8 byte UV-erasable EPROM.  It needs two special voltages for programming.  _VPP_ must be raised to 12.75V and _VCC_ must be raised to 6.25V.  Be sure to isolate the chip's _VCC_ pin from other Vcc connections so that the 6.25V is not fedback into the  Adbuino or into the shift registers.

This chip does not have a dedicated _PGM_ or _WE_ pin, so programming and verify are controlled by the _E_ (Chip Enable) and _G_ (Output Enable) pins.  The _CE_ pin is pulsed to program bytes into a location.  To verify, the _OE_ pin is asserted, but the _CE_ pin is not.

Note the warning in the section above about data corruption from issuing other commands while the programming voltages are present.

This chip can only be erased with UV light, so the erase command is not supported.

### M27256

This is an older version of the M27C256.  Pin connections are the same, but for programming Vcc=6V and Vpp=12.5V.  The programming pulse width is 1ms instead of 100us, and the programming algorithm uses an overwrite pulse equal to 3ms * the number of program pulses written.

### W27C257, W27E257, W27C512

The Winbond W27C257 and W27E257 appear to be identical 32Kx8 EEPROMs.  The 27C version has been tested.  The Winbond W27C512 is a 64Kx8 EEPROM with no dedicated _VPP_ pin.

The 257 EEPROMs have a _VPP_ pin that needs a constant 12V during programming. Unlike the newer 28C EEPROMs, these chips do not automatically erase before writing to a location. Instead, the entire chip is erased by applying 14V to _VPP_ and _A9_ and then pulsing _CE_.  To erase the chip, assert the voltages on _VPP_ and _A9_ and then issue the _Erase_ command from the terminal.

Unlike the 257 chips, the W27C512 does not have a dedicated pin for the programming voltage and instead uses 12V on the _OE_ pin to place the chip in programming mode.  The verify operation requires that the _OE_ pin be switched to _LOW_ and there is no hardware support for this, so the current code supports the 512 chip by doing a single write cycle with no verify.

Because the chips use a constant high voltage for programming instead of a pulse, an external power supply and two diodes can be used to supply either 5V or 12V to the pins for programming and erasing.

Note that the W27x257 chip are almost a drop-in replacement for the 28C256.  The _WE_, _VPP_, and _A14_ pins are the only differences.  For reading, the _VPP_ pin should be connected to 5V.

## SST27SF020

The Silicon Storage SST27SF0x0 are programmed similarly to the 27C257 in that a constant voltage is applied for program and erase operations.  Unlike the 27C257, these have a dedicated WE pin that controls programming and erasing.  Another difference is that they do not have a verify operation to read back the programmed data.

These Flash chips have a _VPP_ pin that needs a constant 12V during programming. Unlike the newer 28C EEPROMs, these chips do not automatically erase before writing to a location. Instead, the entire chip is erased by applying 12V to _VPP_ and _A9_ and then pulsing _WE_.

## Chips to be Tested

|Model |Manufacturer |Type |Module |Notes|
|:--- |:--- |:--- |:--- |:--- |
|TMS2564 |TI |EPROM  | |VPP=25V, 50ms low pulse on PGM|
|AM2716 |AMD |EPROM  | ||
|B2732 |Intel |EPROM  | |VPP/OE=25V, 50ms low pulse CE|
|MBM2732A  |Fujitsu |EPROM  | ||
|2764 |SEEQ |EPROM  | |VPP/OE=21V, 50ms low pulse CE|
|AM2764-2  |AMD |EPROM  | |VPP=21V, 50ms low pulse PGM|
|M5L2764K  |Mitsubishi |EPROM  | |VCC=6V, VPP=21V, 1ms low pulse PGM 4x overwrite|
|D2764 |Intel |EPROM  | |VCC=6V, VPP=12.5V, 1ms low pulse PGM 3x overwrite|
|D27128 |Intel |EPROM  | |VCC=6V, VPP=12.5V, 1ms low pulse PGM 3x overwrite|
|W27C512 |Winbond |EEPROM |27 |Continual 12V or 14V for program/erase,VPP on OE|
|M27C2001  |ST Micro |EPROM  | |VCC=6.5V, VPP=12.75V to pgm|
|M27C4001  |ST Micro |EPROM  | |VCC=6.5V, VPP=12.75V to pgm|
|MCM68766  |Motorola |EPROM  | |PGM pulse is 25V|

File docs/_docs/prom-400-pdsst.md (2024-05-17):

---
title: PromDeviceSST
permalink: /docs/prom-device-sst
exerpt: "TommyPROM support for SST39SF010, SST39SF020, and SST39040 Flash"
---

## PromDeviceSST39SF

SST39SF0x0 NOR Flash chips are 5V-only chips that use a command register for program and erase operations.  They use fixed 4K-byte sectors that must be manually erased before a new program operation, but the code manages this transparently.  Whenever a write is started to a new segment, the driver first initiates an erase of that sector. A second write to the same sector will not cause an erase, so it is possible to write to a segment multiple times with no additional steps as long as the writes are to different parts of the sector.  For example, 256 bytes could be written to the start of a sector from one file and then 512 bytes could be written to the end of the sector from another file.

Writing data that spans multiple sectors also works with no additional steps.  When a sector boundary is crossed, the new sector is erased and set as the current sector.

The SST39SF driver supports a manual erase from the command line using the E command. This is only needed if data will be rewritten to the same location after a previous write to that sector.

All programming and erase operations for the 39SF chips require only a single 5V power supply.

## PromDeviceSST28SF

The SST28SF0x0 SuperFlash chips are an earlier version of the 39SF chips, using 256-byte sectors.  The 28SF and 39SF chips are pin compatible, but use different command sets for programming and erasing.  For read-only applications, they should be identical, although the 28SF are slower.

All programming and erase operations for the 28SF chips require only a single 5V power supply.

### SST39SF040

The SST39SF driver supports all chips in this family, so the 040, 020, and 010 chips can be all be used with no code change.  These chips use sectors that must be erased before writing new data.  The code keeps track of the current sector and will automatically do an erase operation whenever a write starts to a new sector.  The _Erase_ command is supported, but is not needed unless overwriting new data to a single sector.

### SST28SF040

This is an earlier version of the SST39SF series chips.  They are pin compatible with the 39SF series, but use a different command set for programming.  Unlike the 39SF, these flash chips support software data protection.  The _Lock_ and _Unlock_ commands can be used to enable and disable SDP from the command line.

## Verified Chips

|Model |Manufacturer |Type |Module |Notes|
|:--- |:--- |:--- |:--- |:--- |
|SST39SF040|Microchip |Flash  |SST39SF|All SST39SF0x0 supported|
|SST28SF040|SST |Flash  |SST28SF|All SST28SF0x0 supported|

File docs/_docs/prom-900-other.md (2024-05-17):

---
title: Other Device Types
permalink: /docs/other-devices
exerpt: "Other PROM device types"
---

Several other chip families have been identified and aquired, but are not yet supported.

## 28F Series

The 28F series flash do not have sectors. The entire chip must be erased before writing new data.  All location must be manually written to logic zero before the erase operation in initiated.  Data is written a byte at a time using a command register to control the programming.  **These chips require a 12V programming voltage that must be present during the programming or erase operations**.  

TommyPROM does not currently support 28F chips, but it would not be difficult to write a driver.  The default 28C driver will read 28F chips.

## 29F Series

The 29F series flash have sectors that must be explicitly erased before writing new data.  Data is written a byte at a time using a command register to control the programming.  

TommyPROM does not currently support 29F chips, but it would not be difficult to write a driver.  The default 28C driver will read 29F chips.

## Chips to be Tested

|Model |Manufacturer |Type |Module |Notes|
|:--- |:--- |:--- |:--- |:--- |
|AM28F512  |AMD |EEPROM | ||
|AM29F040  |AMD |EEPROM | ||
|M29F040 |ST Micro | | ||
|AMS29AF010|AMS | | ||

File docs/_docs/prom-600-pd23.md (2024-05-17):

---
title: 2316, 2332, and 2364 ROMs
permalink: /docs/prom-device-23
exerpt: "2316, 2332, and 2364 Read Only Memory"
---

## 2316, 2332, and 2364 Mask-Programmable Read-only Memory

The 2316 is a 2Kx8 mask-programmable ROM made by Commodore.  Intel made a version called the 2316E.  There were also 4K and 8K versions produced as the 2332 and 2364.  These chips were used by a wide variety of computers in the late 1970s and early 1980s, including products from Commodore, Atari, Ohio Scientific, Radio Shack, and others.

## Compatibility with UV EPROMs

The 2316, 2332 and 2364 ROMs are somewhat unique because they have Chip Select signals that are configured when the data is mask-programmed.  Manufacturers could order a 2316 configured with any of its three Chip Select signals as either active-high or active-low.

This causes a bit of confusion, because the datasheets state that the chips are compatible with standard EPROMs, but they should really state that the chips __can be__ compatible, depending on the configuration selected.  For example, a 2316 is only compatible with a 2716 EPROM if the 2316 was manufactured with *CS1* and *CS2* configured active-low and *CS3* configured active-high.  Otherwise, some signals will need to be inverted to swap out a 23 series chip with a more standard EPROM.

Some systems contain multiple 23xx chips with the Chip Selects configured the same and others will configure each chip differently.  For example, the OSI SuperBoard contains five 2316s and they are all configured with the CS1, CS2, and CS3 lines active-high.  On the other hand, some 8K Atari cartridges use two 2332 chips and will invert one of the Chip Selects so that either chip can be selected with a single address line to differentiate them.  If the chips are removed from the cartridge, they would need different Chip Select values to read their data.

## Reading 23xx chips with TommyPROM

A TommyPROM programmer can be built with an Arduino to read 2316 ROM chips.  This can be constructed on a breadboard for quick use. The [TommyPROM32 printed circuit board](tommyprom32-pcb) version can also be used for a more permanent solution.

The TommyPROM code will scan the ROM to determine the correct Chip Select settings, so no wiring changes or inverters are needed when switching chips of the same type.

To use TommyPROM with 2316 chips, perform the following steps:

* Connect the Arduino data bus lines (D2..D9) to the ROM data lines.
* Connect the shift register address lines to the ROM address lines.
* Connect Arduino A2 (WE) to the ROM's CS3 on pin 21.
* Connect Arduino A1 (CE) to the ROM's CS2 on pin 18.
* Connect Arduino A0 (OE) to the ROM's CS1 on pin 20.
* Compile the TommyPROM code with PROM_IS_23 enabled

When running the TommyPROM software, first use the Unlock command to scan the chip.  This should detect the correct configuration of the chip select lines.
After the scan us complete, the Dump or Read command can be used to read the data.

The 2332 only has two chip selects, so pin 21 should instead be connected to the shift registers A11 and the Arduino Pin A2 left unconncted.  For the 2364, pin 21 connects to A12 and pin 18 connects to A11.

## 23xx Chips and Configurations

|Model |Type |CS3  |CS2  |CS1  |Tested|Notes|
|:--- |:--- |:---:|:---:|:---:|:---:|:--- |
|**Ohio Scientific SuperBoard**|||
|Monitor |2316 | x | H | H | Y |
|BASIC1 |2316 | x | H | H | Y |
|BASIC2 |2316 | x | H | H | Y |
|BASIC3 |2316 | x | H | H | Y |
|BASIC4 |2316 | x | H | H | Y |
|**Compukit UK101**|||
|MONUK02 |2316 | x | H | H | Y |
|BASUK01 |2316 | x | H | H | Y |
|BASUK02 |2316 | x | H | H | Y |
|BASUK03 |2316 | x | H | H | Y |
|BASUK04 |2316 | x | H | H | Y |
|**Commodore 64**|||
|901225-01 |2332 | - | | | N | Character ROM
|901226-01 |2364 | - | - | | N | Basic
|901227-03 |2364 | - | - | | N | Kernal
|**Commodore VIC 20**|||
|901460-03 |2332 | - | L | L | N | Character ROM
|901486-01 |2364 | - | - | | N | Basic
|901486-06 |2364 | - | - | | N | Kernal
|**Commodore 1451**|||
|325302-01 |2364 | - | - | | N | DOS
|901229-05 |2364 | - | - | | N | Kernal
|**TRS-80 Model 1**|||
|ROM A |2364 | - | - | | N|
|ROM B |2332 | - | | | N|
|**Apple II**|||
|**Atari 400 and 800**|||
|**Atari 2600 Cartridge**|||
|ROM A |2332 | - | | | N|
|ROM B |2332 | - | | | N|

## References

[Commodore 64](https://ist.uwaterloo.ca/~schepers/roms.html)

[VIC 20 Character ROM](https://forum.vcfed.org/index.php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)

[2532 vs 2732](https://pinside.com/pinball/forum/topic/are-2532-and-2732-eproms-interchangeable)

[2332 vs 2532](https://wereallgeeks.wordpress.com/2023/04/18/2532_2732_progadapter/)

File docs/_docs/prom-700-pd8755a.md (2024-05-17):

---
title: "8755A Hardware Design"
permalink: /docs/prom-device-8755
exerpt: "TommyPROM Arduino programmer for the Intel 8755A"
---

A special version of the TommyPROM hardware was developed to support the Intel 8755A EPROM with IO chip.  This is a 2Kx8 UV EPROM with additional I/O ports.  

The Intel 8355 is a mask programmable version of the 8755A.  This design can be used to read the 8355.

The Intel 8755A uses a multiplexed data and address bus, plus 3 additional address lines. Most Arduino hardware has enough pins to support this directly, so no shift register hardware is needed for addressing. An Arduino pin is also used to drive the ALE latch pin.

The 8755A requires the Vdd pin to be be switched between 5V and 25V during the programming of each byte. A simple transistor circuit is used for this. No voltage regulator circuit is present here for the programming voltage. Because this is designed as a quickly assembled hardware design, a triple output bench supply was used to provide the 25.5V, 5.5V and 5V outputs.

TommyPROM Nano Schematic

Eagle-format schematics can be downloaded from the [hardware project page](https://github.com/TomNisbet/TommyPROM/tree/master/hardware).

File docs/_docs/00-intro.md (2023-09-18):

---
title: "TommyPROM - An Arduino-based EEPROM programmer"
permalink: /
excerpt: "TommyPROM Arduino based programmer for 28C256 EEPROMs"
---

TommyPROM is a simple EEPROM programmer and reader that can be assembled using an Arduino and a
few additional parts.  It has been successfully built using the Arduino UNO, Nano and
Boarduino models.

The original code was specific to the 28C256 32Kx8 EEPROM, but it has been extended to
also support SST39SF flash, 27C EPROMs, 29C flash and the Intel 8755A EPROMS.

TommyPROM Nano Hardware

Features include:
* Simple hardware design that can be assembled on a breadboard.
* ROM images transfers using XMODEM - no special host client needed.
* Support for fast block EEPROM writes - a 32K EEPROM will program in just a few seconds.
* Optimized code that supports the timing requirements needed to unlock the 28C series [Software Data Protection](docs/28C256-notes) Algorithm.
* Modular software design to easily support other EEPROM, flash, and EPROM families.
* Hardware support for 19 address lines, allowing the use of chips as large as 512KB, like the SST39SF040 and 29C040.

## Design

The 28C hardware and software design can be used with other 5V PROMS as well.  Many 5V
chips, including UV EPROMs such as the 2716, 2764, 27C2001 and 27C040, can be read, but
not written, with the basic hardware. Some pin changes may be needed to get the signals to
the correct pins on the device.  See the [Extending the design](docs/extending) page for
details on suggested hardware and software changes needed to support new
[EPROM, flash,and EEPROM families](docs/prom-families).

The PROM-specific code is modular and can be easily adapted to support additional devices.
There are currently drivers for 28C series EEPROMS, SST39SF flash, 27C EPROMs and the
Intel 8755A EPROM.

Some 29C series chips, like the 29C010 can be written with the 28C hardware and driver.
The 29C series only differs from the 28C in that the 29C chips erase and write an entire
sector at a time.  The 29C010 and some 29C020 chips use a 128 byte sector, which matches
the XModem buffer in the current code.  Other 29C020s and all 29C040s use a 256 byte
sector and cannot be written without code changes to buffer up an entire 256 byte block of
data before writing.

The [hardware](docs/hardware) page has descriptions of the hardware designs and links to
schematics.  The [software](docs/software) page has class definitions and more information on
the software design.

The project was inspired by the
[MEEPROMMER programmer](https://github.com/mkeller0815/MEEPROMMER).

## PCB Version

Although it was originally designed as a one-off programmer to be used on a breadboard,
there are now some PCB versions as well.  The [PCB](docs/pcb) page has descriptions with links
to the KiCad schematics and Gerber files.

TommyPROM PCB

## Compiling

Open the TommyPROM.ino file in the Arduino IDE. It should automatically open the cpp and h
files as well. The default code programs 28C series chips using Arduino Nano hardware.  To
use this version, just compile and upload it to the Arduino.

**Note well** that this code has been optimized for the Aduino UNO and Nano hardware so
that it can run quickly enough to meet 28C series chip timing requirements for SDP
unlocking.  To use different Arduino hardware, like the Micro, the board-specific code in
PromDevice.cpp and PromAddressDriver.cpp must be changed to match the port mappings
between the ATmega chip and the Arduino I/O pins.

Because the Arduino has limited code and RAM space available, only one PROM driver is
compiled in at a time.  To change drivers, uncomment the desired PROM_IS_xx line in
Configure.h and  comment out the other choices.  The code to instantiate the driver is
near the top in TommyPROM.ino.  The change to Configure.h will automatically cause a
driver to be installed, but it may be necessary to modify the parameters for a specific
chip type.

## Troubleshooting

* Verify that the Arduino type you are using is a supported board or that its I/O port definitions match one of the supported boards.  Some other Arduino boards, like the
Duemilanove, appear to be compatible but have not been tested. Others, like the Micro,
have different port mappings and definitely will not work without software changes.
* If the code doesn't appear to be working, concentrate on the read operations first to
verify that the data and address paths are good.
* 28C series EEPROMS, like the X28C256, sometimes ship from the factory with Data
Protection enabled.  Use the UNLOCK command to disable this. See the
[28C256 Notes](docs/28C256-notes) for more information.
* Re-check all hardware connections and verify the the control pins are going to the
Arduino pins that match the definitions in the code.
* This repo contains a standalone program called HardwareVerify that allows low-level
access to the address, data, and control lines through a menu-driven interface.  See the [troubleshooting](docs/troubleshooting) section for more tips.

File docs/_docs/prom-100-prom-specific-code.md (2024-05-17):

---
title: Chips Supported
permalink: /docs/prom-specific-code
exerpt: "PROM types supported by TommyPROM - EPROM, EEPROM, Flash"
---

TommyPROM can be used to read and write many different types of EEPROM, Flash, and EPROM
chips.  Due to differences in the technologies of these chips, some features of TommyPROM
may work differently or may not be applicable at all.  The standard code can read most
types of PROM, even if there is no specific software support for them.

Broadly speaking, there are two different ways to write to chips.  The first method is
similar to a static RAM - the WE signal is asserted and data is written to a location
using the data and address lines.  This is the case for the 28C64. Some of these chips,
like the 27C257, need a programming voltage to be present on the Vpp or PGM pin.  There
are usually timing requirements for the program pulse and there may be repeated write
cycles needed with a verification cycle to complete the write.

The second method is the use of a program command register.  Bytes are written to a single
location by sending a command string, which is a series of chip writes.  These chips
usually have additional commands to erase sectors or to lock and unlock the chip.  The
SST39SF010 is an example of a chip that uses a command register.  

Some chips use a combination of both methods.  The 28C256 uses a command register to
enable and disable Software Data Protection, but uses a direct write for programming.

TommyPROM has a variety of PromDevice Modules that can be compiled in to support these
different chip technologies.  Only one PromDevice module can be compiled into a build.

## Suported Chips

|Module  |Manufacturer |Type |Notes|
|:--- |:--- |:--- |:--- |
|28C |Atmel, others|EEPROM |28C256, 28C64, 28C16, 29C040 (Flash)|
|SST |Microchip |Flash  |SST39SF040 (all SST39SF0x0), SST28SF040|
|27 |many |EPROM  |variety of 27xx and 27Cxx EPROM, Flash, and EEPROMs|
|2316 |many |ROM |read-only 2316, 2332, 2364, 23128, 23256|
|8755A |Intel |EPROM  |8755A EPROM and read-only 8355|

## PromDevice Modules

This PromDevice28C module is enabled by default to program 28C256 EEPROMS. To use a
different module, make the following edits:

* In configure.h, comment out the #define PROM_IS_28C line
* Uncomment one of the other PROM_IS_ lines to compile a different module
* In TommyPROM.ino, uncomment or add a new PromDevice declaration for the specific chip

## Chip Manufacturers

|Name |Code |Notes|
|:--- |:---|:---|
|AMS - Advanced Memory Systems|AMS |Merged with Intersil|
|AMD - Advanced Micro Devices |AM  ||
|Atmel |AT  |Aquired by Microchip|
|CSI - Catalyst Semiconductor |CAT |Aquired by ON Semiconductor|
|Fujitsu |MBM ||
|Intel |i ||
|Mitsubishi |M5L ||
|Motorola |MCM ||
|Seeq Technology | |Aquired by LSI Logic|
|SST - Silicon Storage Tech |ST  |Aquired by Microchip|
|ST Microelectronics |M ||
|Texas Instruments |TMS ||
|Winbond |W ||
|Xicor |X ||

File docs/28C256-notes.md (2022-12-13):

---
title: 28C256 and SDP
description: "Troubleshooting and Programming 28C256 EEPROMs with Software Data Protection (SDP)"
has_children: false
nav_order: 60
---

# 28C EEPROMs and Software Data Protection (SDP)

The 28C series parallel EEPROMS, like the 28C256, support fast block writes and algorithms
to implement Software Data Protection (SDP).  The SDP feature seems to be a leading cause
of problems for people trying to program these chips with Arduino or other homebrew
hardware.  

The first problem many people encounter is that new chips are often locked, even though
the datasheet states that they should ship unlocked.  It isn't clear if the manufacturing
practices have changed or if this might be due to used or counterfeit chips.  In any case,
the chips may need to be unlocked before they can be programmed for the first time.

The unlock is accomplished by sending a sequence of bytes to specific addresses.  Many
people have reported problems with this step when using DIY programmers. Some programmers
may not be writing the SDP sequences quickly enough to successfully unlock the chips and
yet others will report that the same hardware works correctly.  This may be due to
variances in the behavior of chips from different manufacturers.

When writing SDP lock/unlock sequences, the datasheets note that the timing between bytes
must follow the same restrictions as page writes.  In particular, the bytes must be
written within the tBLC (Byte Load Cycle time).  On Atmel parts, this is specified as
150us max, so each write pulse must occur within 150us of the previous write.  The tBLC
value is even shorter on the Xicor and ON Semi datasheets, stating that the writes must
occur within 100us of each other.

In practice, the Xicor chips seem very forgiving of the timing, doing successful SDP and
page write operations even when the tBLC is close to 200us.  Atmel chips, on the other
hand, will refuse to unlock when the timing is outside the acceptable maximum.

# Solution

**Note:** if you are using the Ben Eater EEPROM programmer, see the [unlock-ben-eater-hardware sketch](https://github.com/TomNisbet/TommyPROM/tree/master/unlock-ben-eater-hardware)
for a solution to disable SDP on locked chips.

The TommyProm programmer uses direct port access on the Arduino to control the data bus
and addressing shift register.  This is much faster than doing individual DigitalWrite
calls and allows the unlock and page write code to run comfortably within the tBLC
constraints.  It has been successfully tested with the following 28C256 chips:

* Atmel AT28C256-15PU
* Catalyst/ON Semi CSI CAT28C256P-12
* Xicor X28C256P-15
* Xicor X28C256P-25

The Atmel chips tested included a batch from eBay that may not have been genuine, but they
were unlocked and burned successfully with the TommyProm code.

The capture below shows an unlock command sequence where the tBLC is within 80us for each
byte.

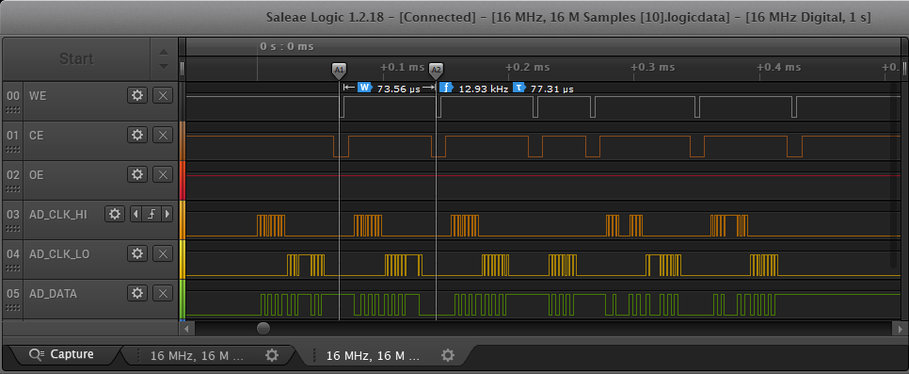
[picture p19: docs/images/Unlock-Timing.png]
Unlock Timing


# References

1. [Atmel AT28C256 Data Sheet, 0006M–PEEPR–12/09](http://ww1.microchip.com/downloads/en/DeviceDoc/doc0006.pdf)
1. [Xicor, Intersil, Renesas X28C256 Data Sheet, 3855-1.9 8/1/97 T1/C0/D8 EW](https://www.renesas.com/us/en/www/doc/datasheet/x28hc256.pdf)
1. [ON Semiconductor CAT28C256 Data Sheet, CAT28C256/D, December, 2009 − Rev. 6](https://www.onsemi.com/pub/Collateral/CAT28C256-D.PDF)
1. [Parallel EEPROM Data Protection Application Note, Atmel, Rev. 0543C–10/98](http://ww1.microchip.com/downloads/en/AppNotes/DOC0543.PDF)

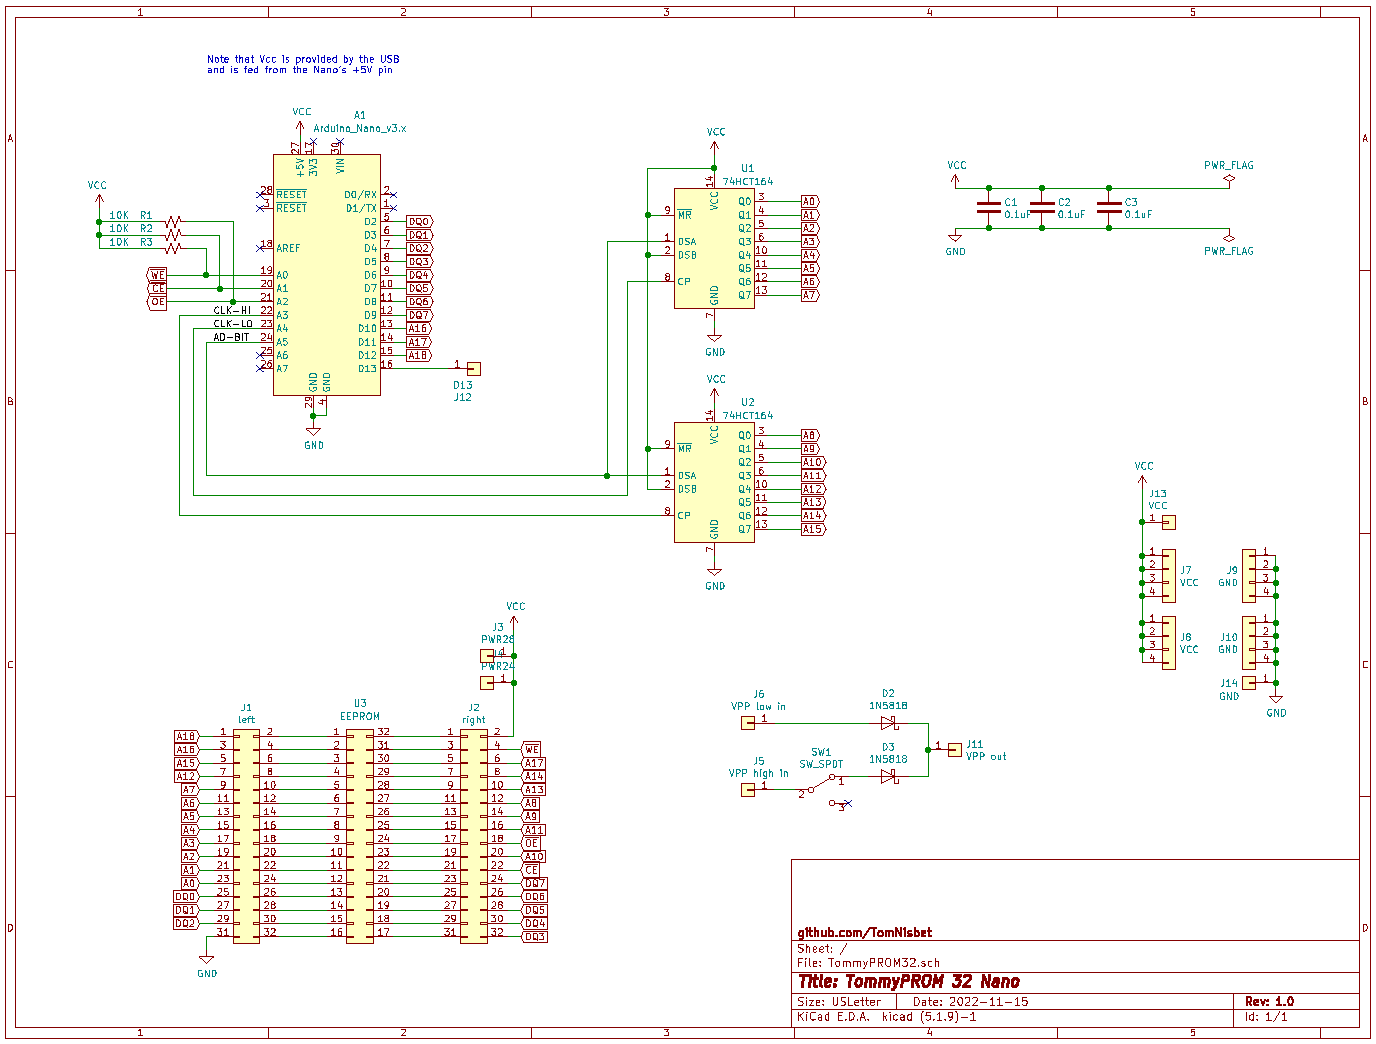
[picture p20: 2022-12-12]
docs/_docs/images/TommyPROM32-schematic.png

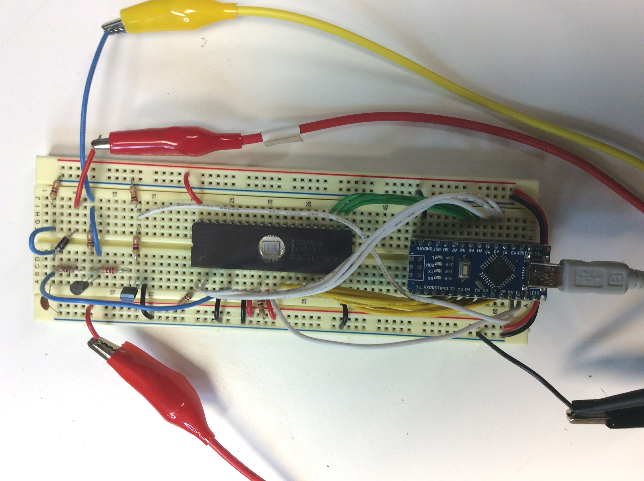
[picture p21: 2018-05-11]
docs/_docs/images/TommyPROM-8755A.jpg

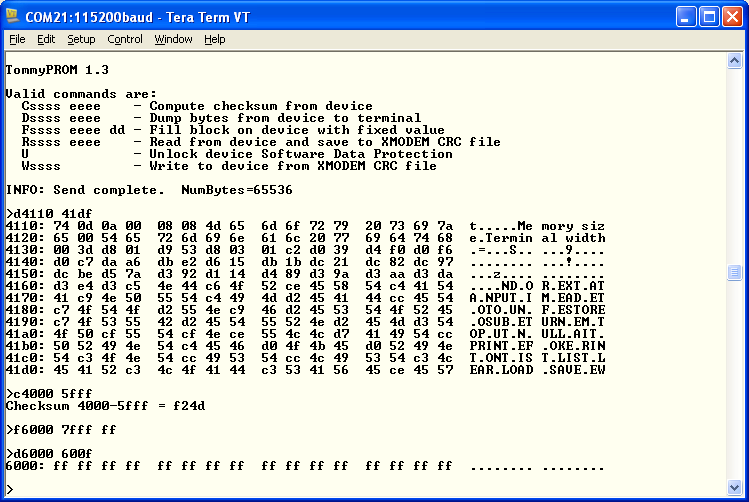
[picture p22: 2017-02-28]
docs/_docs/images/tp05.png

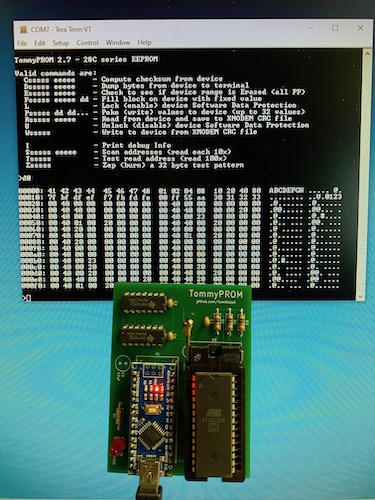
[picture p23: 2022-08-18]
docs/_docs/images/TommyPROM-pcb-with-ui-500.jpg

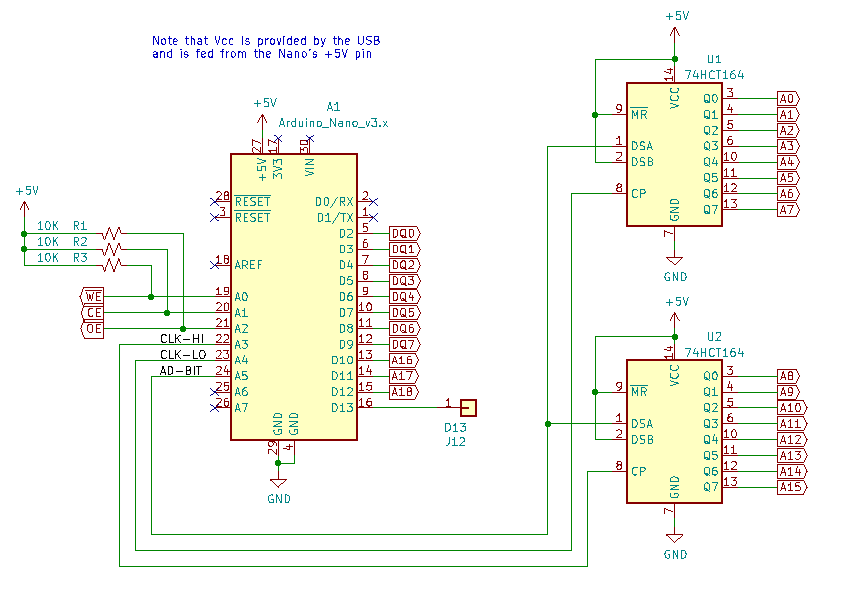
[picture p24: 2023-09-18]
docs/_docs/images/TommyPROM-connections-sch.png

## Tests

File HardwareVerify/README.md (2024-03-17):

# Hardware Verify Script

This is a sketch for low-level debugging of the TommyPROM hardware.  It allows the EEPROM data, address,
and control pins to be individually set so that they can be probed to catch wiring errors.  The usage is
described in the [Troubleshooting documentation page](https://tomnisbet.github.io/TommyPROM/docs/troubleshooting).

This sketch should only be used for debugging if the main TommyPROM sketch does not seem to be working.  To 
get started with a new TommyPROM build, load the TommyPROM sketch into the hardware and try the Unlock, 
Display and Zap commands to test reading and writing.  For example:

```
u
d0 ff
z0
d0 ff
```

The above commands will Unlock the Software Data Protection, Display the first 256 bytes, burn a
sequence of test data into the first 32 bytes, and then Display the first 256 bytes again.

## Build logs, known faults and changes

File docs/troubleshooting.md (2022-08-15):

---
title: Troubleshooting
description: "Troubleshooting TommyPROM hardware"
has_children: false
nav_order: 50
---

## Hardware Verifier Tool
A [Hardware verification Arduino sketch](https://github.com/TomNisbet/TommyPROM/tree/master/HardwareVerify)
is provided to assist with troubleshooting.  Loading this sketch onto the TommyPROM
hardware allows access to individual control lines from the Arduino to verify that the
hardware was assembled correctly.

The verifier sketch can be used without a chip installed to scope out address and data
lines.  It also offers low-level control when the chip is installed.  

THIS TOOL USES DIRECT PORT ACCESS ON THE ARDUINO.  CHECK TO MAKE SURE IT IS COMPATIBLE
WITH YOUR BOARD BEFORE USING.  It will work correctly on the Uno, Nano, and Boarduino.  It
WILL NOT WORK on the Micro.

Note that the commands write to the individual 28C control lines with some exceptions to
protect the chip and the host Arduino:

* When the O command is used to enable chip output, the Arduino data bus is set to INPUT
* When the D command is used to write data from the Arduino, the chip output is disabled
* The R command sets the output enable (OE) on the chip, but not the chip enable (CE)
* The L and U commands reset CE, OE, and WE back to disabled on completion and change the
data and address

The session below shows how a write fails to a locked chip and then succeeds once the chip
is unlocked.

```
Hardware Verifier - 28C series EEPROM

Valid commands are:
  Axxxx         - Set Address bus to xxxx
  Dxx           - Set Data bus to xx
  Cs            - Set Chip enable to state (e=enable, d=disable)
  Os            - Set Output enable to state (e=enable, d=disable)
  Ws            - Set Write enable to state (e=enable, d=disable)
  R             - Read and print the value on the data bus
  L             - Send Lock sequence to enable device Software Data Protection
  U             - Send Unlock sequence to disable device Software Data Protection

#l
Writing the lock code to enable Software Write Protect mode.

#a0000

#ce

#r
22

#d55

#we

#wd

#r
22

#u
Writing the unlock code to disable Software Write Protect mode.

#d33

#we

#wd

#r
33

#cd

```

## Troubleshooting

If the programmer seems to be working, but 28C256 EEPROMs cannot be written, the problem
may simply be a locked chip.  Some chips have been received with the Software Data
Protection (SDP) enabled, even though the data sheet states that it should be disabled
from the factory.  If the chip does not write (try the Zap command in the TommyPROM code),
then try an Unlock command and then retry the write.

If the programmer is not working, the most common problem is a simple wiring error.  The
hardware verify sketch can help to find missing or crossed connections.

The hardware has three sections: an 8-bit read-write data bus connected to the target
PROM's data line, a set of write-only address lines generated by shift registers and
connected to the target PROM's address lines, and a set of write-only control lines from
the Arduino that toggle the PROM's output enable and write lines.

The first step in general testing it to remove the target chip and then toggle single
lines from the Arduino.  The result should be measured at the target PROM footprint, not
at the Arduino.  To fully test, use a multimeter to verify that the lines that should be
active are active and that any other lines are not.

Note that the Dx and Ax commands can be a bit confusing.  The command _D5_ means "set the value 05 HEX on the eight data lines".  It does not specifically refer to the D<sub>5</sub> data pin on the ROM or the D5 pin on the Arduino.  In the example above, 05 HEX is the same as 00000101 BINARY.  This would set the ROM D<sub>0</sub> and D<sub>2</sub> pins HIGH and the other six pins would be LOW.

### Testing the data bus

Issue a set of Data commands from the Hardware Verify sketch and measure EACH data line at
the PROM footprint.  **If the expected result is "D<sub>0</sub> HIGH", verify not only
that D<sub>0</sub> reads HIGH, but that all of the other lines read LOW.**

Data test commands

|Command|Result|
|:--- |:---  |
|D0 |All data lines LOW|
|D1 |D<sub>0</sub> HIGH|
|D2 |D<sub>1</sub> HIGH|
|D4 |D<sub>2</sub> HIGH|
|D8 |D<sub>3</sub> HIGH|
|D10 |D<sub>4</sub> HIGH|
|D20 |D<sub>5</sub> HIGH|
|D40 |D<sub>6</sub> HIGH|
|D80 |D<sub>7</sub> HIGH|
|Dff |all data lines HIGH|

### Testing the address lines

As with the data tests above, verify not only the line with the expected result, but all
other address lines as well.

|Command|Result|
|:--- |:---  |
|A0 |All address lines LOW|
|A1 |A<sub>0</sub> HIGH|
|A2 |A<sub>1</sub> HIGH|
|A4 |A<sub>2</sub> HIGH|
|A8 |A<sub>3</sub> HIGH|
|A10 |A<sub>4</sub> HIGH|
|A20 |A<sub>5</sub> HIGH|
|A40 |A<sub>6</sub> HIGH|
|A80 |A<sub>7</sub> HIGH|
|A100 |A<sub>8</sub> HIGH|
|A200 |A<sub>9</sub> HIGH|
|A400 |A<sub>10</sub> HIGH|
|A800 |A<sub>11</sub> HIGH|
|A1000  |A<sub>12</sub> HIGH|
|A2000  |A<sub>13</sub> HIGH|
|A4000  |A<sub>14</sub> HIGH|
|A7fff  |all address lines HIGH|

### Testing the control lines

The PROM control lines are active LOW, so an enable command will set the corresponding
control line LOW and a disable will set it HIGH.  Try the commands in the following table.
Note that they should be done in the order listed, because a test command on one control
line will not change the state of any of the other lines.

To begin, issue the following commands: D0, A0, Cd, Od, Wd.  Note that the Od command is
the letter 'O', not the number zero.  All three control lines should read HIGH after these
commands are complete.

|Command|Result|
|:--- |:---  |
|Ce | Chip Enable (CE) LOW, others HIGH|
|Cd | CE, OE, WE all HIGH|
|Oe | Output Enable (OE) LOW, others HIGH|
|Od | CE, OE, WE all HIGH|
|We | Write Enable (WE) LOW, others HIGH|
|Wd | CE, OE, WE all HIGH|

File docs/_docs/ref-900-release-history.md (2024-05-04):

---
title: TommyPROM Release History
permalink: /docs/release-history
exerpt: "What's New in TommyPROM"
---

## TommyPROM Release History

|Revision |Date_added |Notes|
|:---: |:---: |:--- |
|1.0 |2017-02-27 |Initial version to support 28C256 EEPROMs|
|1.5 |2018-05-10 |Split into modular PromDevice drivers to support 8655A|
|1.6 |2018-12-22 |Early suport for 27C devices |
|1.7 |2019-06-08 |Add Lock command for 28C256 |
|1.8 |2019-06-09 |Optimize address register code to meet unlock timing requirements and create HardwareVerify sketch|
|2.0 |2019-07-19 |Extend addressing to 19 bits to read larger chips, like the 29C040|
| |2020-08-08 |Add dedicated sketch to unlock 28C256 chips using Ben Eater hardware design|
|2.1 |2020-08-15 |Add Poke command|
|2.2 |2020-08-24 |Add support for 74LS595 shift registers for addressing and fix XModem ACK issue|
|2.3 |2020-08-26 |Fix addressing bug|
|2.4 |2020-10-10 |Add XModem debugging information and fix #17 for AT28C256 write failures|
|2.5 |2020-10-14 |Change XModem default to 8-bit checksum instead of CRC16|
|2.6 |2020-11-11 |Change XModem default back to CRC16|
|2.7 |2020-11-14 |Additional XModem protocol error handling|
|3.0 |2021-08-12 |Support for SST39SF0x0 flash devices|
|3.1 |2022-12-10 |Support for 27C257/27E257 EEPROM|
|3.2 |2022-12-13 |Support for SST28SF flash|
|3.3 |2022-12-14 |Support 29C0x0 flash|
| |2022-12-23 |Documentation for TommyPROM32 PCB|
|3.4 |2024-04-09 |Support 2316,2332, and 2364 mask-programmed ROMs|
|3.5 |2024-04-12 |jcranes's updates to CLI for better parameter defaults and additional error checking|
|3.6 |2024-04-23 |Remove debug commands by default - can be enabled in Configure.h|
|3.7 |2024-05-03 |Change overwrite algorithm for 27 series to match SEEQ and M27256 datasheets|

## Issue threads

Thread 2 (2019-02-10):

Shift registers

coolname1, 2019-02-10:
Hi there,

Not an issue as such... Can this project use the 74HC595 shift registers as an alternative shift register? I have about 20 of those, but no 74LS164. Thanks :)

TomNisbet, 2019-05-16:
Sorry for the late reply.  Any serial-in parallel-out shift registers should work, although there would be a few pin changes.  For example, the 72HC595 has a OE that would just be tied to ground to have it always enabled.

OmaiGrundles, 2020-03-15:
I would like to mention that to get the 74HC595 to work, I had to add code to PromAddressDriver.cpp: defining an unused pin(10), and toggling it high then low at the end of PromAddressDriver::setAddress. Then attaching pin 10 from the arduino to the RCLK pin of each shift register.

I am a complete newbie when it comes to this kind of stuff so there probably is a better way though.

I would also like to thank @TomNisbet for doing all this. You saved the project I was working on, I had no other way of getting the darn write protection off of my AT28c256's! People like you are amazing! :)

TomNisbet, 2020-03-17:
I just looked at the data sheet and saw the two stage design for that chip.  Your addition to clock the data from the shift register to the storage register makes perfect sense.  Glad it is working for you.

ABelliqueux, 2024-05-29:
@OmaiGrundles : Could you share your modified code here ? I plan to use 74HC595s too...

ABelliqueux, 2024-05-29:
Oh I didn't realize these instructions applied to 74HC too. Thanks for the clarification !

ABelliqueux, 2024-05-31:
Last question : Is the TommyPROM32 PCB compatible with 74HC595 too ? I suspect it needs modification to connect the RCLK pins ?

ABelliqueux, 2024-06-01:
Just checked the PCB quickly and noticed the tommyprom32 is designed around two 74HCT164s that don't have pinouts similar to 74LS/74HC :
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
hence the notes [here](https://tomnisbet.github.io/TommyPROM/docs/hardware#74ls595-shift-registers) wont apply.

Would adapting the TommyProm32 PCB to 74HC/LS require a lot of modifications to the PCB ?

ABelliqueux, 2024-06-02:
Hi, I think I'll give it a try if it's not too difficult. I'll check the datasheets for these components and hopefully I'll be able to figure out how to alter the layout. I'll keep you updated here if you don't mind the thread hijacking too much :sweat_smile:

TomNisbet, 2024-06-02:
Looking at your schematic above, the good news is that the schematic symbol pins for the outputs of the 595 are in the same place as the 164.  You should be able to delete the control wires near the chip on the left side and then slide the 595 into place with QA connected to A0 and QH connected to A7.  Then you just need to connect the appropriate control signals on the left.

After you delete the 164s, number the two 595s as U1 and U2.  You will also need to assign the DIP-16 footprints to the 595s in the schematic editor.  You can then go the the PCB layout and use the Update From Schematic button to replace the 164s with the 595s.  I deleted the wire segments closest to the chip to have some space to work.  It looks like the layout may be easier if you rotate the chips so that pin 1 is at the bottom.

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

ABelliqueux, 2024-06-03:
Thanks for your pointers !
Here is what I've come up with so far :

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

according to :

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
55/44bfa90c-456e-4fe3-82db-d7296dde34c9)

I also removed J12 and connected D13 to LSR+USR RCLK directly as per [the doc](https://tomnisbet.github.io/TommyPROM/docs/hardware#74ls595-shift-registers).

I'm not sure about pins 10 and 13 as their name differ between the datasheet and kicad's libary ( MR/OE for the 164 vs SRCLR/OE for the 595 ).

TomNisbet, 2024-06-04:
Yes. SRCLR is high and OE is low.

ABelliqueux, 2024-06-05:
Here goes ... I hope I didn't make mistakes, the DRC tests pass fine but for one warning about the "+5V" marking overlapping something :

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

A vector version is available here for higher resolution :

[TommyPROM32-brd.pdf](https://github.com/user-attachments/files/15592335/TommyPROM32-brd.pdf)

And the pro file is here :

[TommyPROM32-2024-06-05_163940.zip](https://github.com/user-attachments/files/15592380/TommyPROM32-2024-06-05_163940.zip)

ABelliqueux, 2024-06-14:
Just a heads up to say that the breadboard version of the schematics for the TP32-595 version is working as intended. I think I'll order some pcbs soon and confirm all is well here.

ABelliqueux, 2024-07-29:
Well, here it is, working all right AFAICT (did several reads/dumps checking checksum), the 595 version :)

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

Closed 2019-05-16.

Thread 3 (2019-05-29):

Trying to get TommyPROM working?

JohnDavidGay, 2019-05-29:
I've breadboarded TommyPROM, but I am having issues getting it working and don't understand enough to find the fault myself.
I've downloaded the firmware to my Boarduino, and I can read the contents of EEPROM's but attempts to write fail.
Is there a way I can contact someone to help me?

Cheers,

     John Gay

TomNisbet, 2019-06-03:
I haven't built this with a boarduino, but it should work as long as you connect the same pins and get the right board defined in configure.h.  In that file, be sure to comment out all of the #define ARDUINO_IS_ lines so that the code uses the generic data bus code instead of the faster board-specific code.

Which chip are you trying to program?  The datasheet says that 28C256 chips are shipped with write protect disabled, but I got a batch of them that were write protected.  The Unlock command should fix this.

If you can explain the failure you are seeing I should be able to walk you through it.  Also, there is a define for ENABLE_DEBUG_COMMANDS in configure.h that can be used to add some additional command line tools that may help.  The ZAP command will program a small pattern into the chip and then read it back.  This is a nice way to verify write functionality without having to transfer files.

Tom

JohnDavidGay, 2019-06-03:
Thanks for the reply.
I don't remember what ARDUINO_IS_ line I left in the last time, but I did try each one because I wan't sure what the Boarduino should be.
I'll try commenting all all of them and see how that works.
I'll also enable the ENABLE_DEBUG_COMMANDS so I get more details.
I've got 28C256's and 28C64's I also have some UVEPROMs that I've been able to read data from, but since they are from a 68,000 board, the data is split between to two chips. I was just checking to be sure I could read actual data.
I've been trying to use the fill command to write the data and it just errors out.
The set-up is my home Laptop and I can try after work or during the weekend. I'll let you know what I get. Is there a more direct way to chat? I didn't want to open an issue on your Github.

Cheers,

     John Gay

TomNisbet, 2019-06-03:
John,

It sounds like you are on the right track. If you are reading known good data from a chip and not just random bytes, then you’ve already verified almost all of the hardware. This is exactly how I checked out the initial design with some old EPROMS.

Verify that the connection to the WR pin of the rom is going to the pin on the arduino that is defined in the software. Also verify the both the read and write pins are high when you aren’t doing any operation. If you have a logic analyzer or storage scope, you can also verify that the WR pin is pulsing low during a write operation.

Another check is to see if you are making any change to the chip at all when you try to write. In other words, try a fill command to write 00 or FF to the first byte if the rom and then do a read to see if it’s value changed at all.

I think the default code uses a block write algorithm and this can be changed to do a simpler write-then-read instead, but I don’t have the code in front of me now to look.

Finally, don’t forget the Unlock command. My first batch of 28c256s were write protected and I spent a long time debugging that.

Let me know how it goes. I’m sure we’ll be able to get you up and running.

Tom
Sent from my iPhone

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

JohnDavidGay, 2019-06-04:
I rushed home last night excited to try this out when I realised I had re-installed my Laptop recently and didn't have the Arduino IDE or your code on it. PLUS, I recently changed Internet providers and am currently un-connected at home until Friday.
So I've snuck my Laptop to work to "borrow" bandwidth to get the code and IDE over my lunch break.
What I don't have are any tools other than a multi-meter, so checking Voltage levels is possible, but not pulses.
I'm not certain the data from the UVEPROM is valid, but it doesn't seem completely random. What I have are two 8-bit EPROM's that were used as upper and lower bytes for a 16-bit board.
I've tried the UNLOCK command a few times and it completes without complaint.
I've tried using the fill command to write aa to the first 8 bytes, but the command errors out and when I dump the data it's still all ff's.
I am currently using cutecom on Linux to talk to the TommyPROM. I just lack the programming skills to try poking the EEPROM directly with the Arduino to see if I can at least change the memory.
Thanks for all your help. I've got a Z-80 Single board computer I'm looking to play with, as soon as I can get an EEPROM programmed. I also have a MC68000 I want to poke at as well. Just reliving the days when I wished I had the money to play with those processors the first time around.

Cheers,

     John Gay

JohnDavidGay, 2019-06-04:
I've commented out all 3 ARDUINO_IS lines and ENABLE_DEBUG_COMMANDS is not commented out.
f0000 000f aa gives:
ERROR: Write failed
And f0000 00ff shows all 16 bytes are ff.
I was able to install the arduino app and your code to my laptop. The next step is to carefully verify every wire is correct. Especially the write enable line.
Thanks again for all your help. I'm sure the problem is all my doing.

JohnDavidGay, 2019-06-08:
I've checked the wiring and everything looks good.
WE == A0 ==  Pin27
CE == A1 == Pin 20
OE == A2 == Pin 22
I've checked that all 3 are high and they are pulled up with resistors.
But I've only got a Fluke 77 Multimeter for checking.

When I run d0000 00ff Both CE and OE seem to drop their voltage momentarily.
But when I run f0000 000f aa WE does not seem to change. CE and OE both seem to drop, but WE stays a solid voltage.
I have checked at both the EEPROM pin and on A0 on my Boarduino.
Using Cutecom on my Linux Laptop, I have upped the Char Delay setting to 200ms to see if that makes a difference.
So I'm not sure, but it doesn't look like WE is being pulled down during the fill command?
Or maybe A0 isn't working on my Boarduino?

TomNisbet, 2019-06-08:
The WE line is going to pulse quickly, so you are unlikely to see any change on your meter. You could try moving it to a different pin to see if that has any effect.  Just change the definition in PromDevice28C.cpp to match the new pin.

I'm starting to suspect that the problem is still with device locking if you are not seeing any change to the chip after a write operation.  The Unlock command sends a sequence of bytes to the chip, so if there is a problem with the data or addressing then it won't successfully unlock.  Are you confident that the D command is reading accurate data when you test with other chips? My original build used long jumper wires for the data lines and may have had problems with crosstalk.

Also, I just looked at the schematic for a boarduino and it looks like D2..D9 are mapped to the same ports as the UNO, so you should be able to uncomment ARDUINO_IS_UNO in Configure.h.

TomNisbet, 2019-06-08:
Now that you have enabled DEBUG, try the Scan command to verify reading the chip.  It won't be interesting on an erased chip, but one of your other ROMs can give you more confidence that the reads are working.  Note that this will only verify read consistency.  It wouldn't verify that you has two data wire swapped and were reading the wrong value out every time.

JohnDavidGay, 2019-06-08:
I have no way of knowing what was on the PROMs I have. I just know that they were on a 68000 board and were set-up as odd and even bytes.
I checked the Boarduino schematics, and there are only A0-A5 available, and they are all used.
the Scan command passes with the UV EEPROM, but of course that doesn't prove the data or addresses are correct.
But even if I have the data or address lines swapped, I would expect that it should still write data. It would just put it in the wrong address or possibly shuffle the bits if the data lines are crossed.
Maybe if I had a simple sketch that only tried to write data I could troubleshoot my problem and then get back to loading TommyPROM later.
I'm really interested in spinning a TommyPROM board as a soldering exercise for my local makerspace.

TomNisbet, 2019-06-08:
Can you send me a message to tommyprom@mailinator.com so I can get your email address?  It might be easier to correspond directly so we can send attachments,

I think the problem is that the chip is write protected.  If the data and address lines have a problem then the unlock command isn't going to work.  That's why I'm interested in verifying the read commands.

If you want to force some lines to the chip, it might be easier to just modify this code than to build a new standalone module.  For example, you could add code to toggle the write and enable bits at the end of PromDevice28C::begin().  Or you could even wire up a 28C without the arduino.  Tie the address lines to Vcc or ground to get a pattern you like, tie OE high, CE low, and then pulse WE with a button or jumper.  The datasheet doesn't show a max pulse width for WE, so it shouldn't hurt anything.

As I said before though, I'm guessing the problem is the write protection, so the above tests aren't going to produce anything.

JohnDavidGay, 2019-06-09:
I've buzzed out all the lines again, making sure that I've got the right '164 connected to the right 8 bits of the address bus.
I changed the WE to LOW and that worked, so I know it's not that.
If the chip is write-locked, that can only be fixed programmatically which means getting this going.
The only point not entirely clear in your schematics that I had to guess is D2 goes to D0 on the chip and D9 goes to D7. The way you drew the bus is ambiguous.

TomNisbet, 2019-06-09:
John - Please send an email to tommyprom@nisbethome.com and we'll get this sorted out.  I did some tests yesterday and re-read the datasheets on the 28C.

JohnDavidGay, 2019-06-18:
After some direct contact and troubleshooting, Tom fixed this issue and updated this project.
Great support!

TomNisbet, 2019-06-24:
Issue was related to the timing of the Unlock command for the Software Data Protection(SDP). Xicor parts that I used were much more forgiving than the Atmel parts John used.  Optimized the code so that the Unlock and page writes are now well within the timing specifications on the datasheet.  Also added a 28C readme with more information.  Created a new, standalone hardware debug utility that should help with troubleshooting in the future.

JohnDavidGay, 2019-06-27:
Since I was scared of KiCAD, I've installed Fritzing instead. In the plus
side, it's designed for building Arduino shields.
So hopefully maybe I can get a TommyPROM shield going.

Cheers,

     John Gay

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

Closed 2019-06-18.

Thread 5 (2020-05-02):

TommyProm writing same data to all addresses on Zap test

8BitMark, 2020-05-02:
I've been using 74HC595s using wiring based on Ben Eater's EEPROM breadboard project and the fork of your project from leomil72.  When I run the Zap test I get the following error

ERROR: Verify failed  addr=0x0  read=0x33  expected=0x41

It looks like very address is getting set to 0x33 (the last value in the test data)

Any suggestions as to where to look to figure out what I've messed up?  Thanks

MarkC0x, 2020-05-16:
Hi @8BitMark Did you figure this out by any chance? I am also using two 74HC595’s

I think I am in the same situation as you.  In my case the Zap test fails to verify but if I repeatedly run D0000 to dump out the first 255 bytes it will eventually show the correct data. It’s very strange but I figure it must be something like a timing issue on the read side.  Does your data eventually read correct after retries?

8BitMark, 2020-05-16:
I added some delays to the write code and it's been working for me fine
since.  I also had some incorrect wiring so that plus the delays fixed it.
I'm not near my computer at the moment but will share details later.

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

TomNisbet, 2020-05-17:
I've never tried using 595's.  I had 74LS164s in my parts bin, so that's what's in the design.  A lot of people are using the 595 because of Ben Eater's design, so I'll pick up a few next time I order chips and will give them a shot.

With that said, there's no reason it shouldn't work with them, When you say that the D0000 command eventually works, what is the output on the runs where it doesn't work?

MarkC0x, 2020-05-18:
Hi @TomNisbet, thanks for the reply.  The data on the `D0000` command in the intermittent outputs (before the correct output) seems somewhat random to me, although a lot of` 0x1a` appear.  Here is a sample run output (with timestamps on the Arduino serial monitor):

```
19:21:33.978 -> >d0000 007f
19:21:35.191 -> 0000: ff ff ff ff  ff ff ff ff  ff ff ff ff  ff ff ff ff  ........ ........
19:21:35.191 -> 0010: ff ff ff ff  ff ff ff ff  ff ff ff ff  ff ff ff ff  ........ ........
19:21:35.224 -> 0020: ff ff ff ff  ff ff ff ff  ff ff ff ff  ff ff ff ff  ........ ........
19:21:35.224 -> 0030: ff ff ff ff  ff ff ff ff  ff ff ff ff  ff ff ff ff  ........ ........
19:21:35.224 -> 0040: ff ff ff ff  ff ff ff ff  ff ff ff ff  ff ff ff ff  ........ ........
19:21:35.224 -> 0050: ff ff ff ff  ff ff ff ff  ff ff ff ff  ff ff ff ff  ........ ........
19:21:35.224 -> 0060: ff ff ff ff  ff ff ff ff  ff ff ff ff  ff ff ff ff  ........ ........
19:21:35.258 -> 0070: ff ff ff ff  ff ff ff ff  ff ff ff ff  ff ff ff ff  ........ ........
19:21:35.258 ->
19:21:35.258 -> >z0000
19:21:39.927 ->
19:21:39.927 -> ERROR: Verify failed  addr=0x0  read=0x1A  expected=0x41
19:21:39.962 ->
19:21:39.962 -> >d0000 007f
19:21:43.668 -> 0000: 1a 1a 1a 1a  5a a2 1a 1a  1a 1a fb 5d  1a 1a 08 f0  ....Z... ...]....
19:21:43.668 -> 0010: 1a 1a 1a 1a  1a 1a 1a 1a  2f 1e c1 1e  1a 1a 1a 1a  ........ /.......
19:21:43.668 -> 0020: 1a 1a 1a 1a  1a 1a 1a 1a  1a 1a 1a 1a  1a 1a 1a 1a  ........ ........
19:21:43.668 -> 0030: dc 25 12 da  1a 1a 1a 1a  1a 1a 1a 1a  1a 1a 1a 1a  .%...... ........
19:21:43.705 -> 0040: 1a 1a 1a 1a  1a 1a 1a 1a  1a 1a 1a 1a  1a 1a 1a 1a  ........ ........
19:21:43.705 -> 0050: 1a 1a 1a 1a  1a 1a 1a 1a  1a 1a 1a 1a  1a 1a 1a 1a  ........ ........
19:21:43.705 -> 0060: 1a 1a 1a 1a  1a 1a 1a 1a  1a 1a 1a 1a  1a 1a 1a 1a  ........ ........
19:21:43.705 -> 0070: 1a 1a 1a 1a  1a 1a 1a 1a  1a 1a 1a 1a  1a 1a 1a 1a  ........ ........
19:21:43.741 ->
19:21:43.741 -> >d0000 007f
19:21:46.803 -> 0000: 1a 1a 1a 1a  5a a2 1a 1a  1a 1a fb 5d  1a 1a 08 f0  ....Z... ...]....
19:21:46.803 -> 0010: 1a 1a 1a 1a  1a 1a 1a 1a  2f 1e c1 1e  1a 1a 1a 1a  ........ /.......
19:21:46.836 -> 0020: 1a 1a 1a 1a  1a 1a 1a 1a  1a 1a 1a 1a  1a 1a 1a 1a  ........ ........
19:21:46.836 -> 0030: dc 25 12 da  1a 1a 1a 1a  1a 1a 1a 1a  1a 1a 1a 1a  .%...... ........
19:21:46.836 -> 0040: 1a 1a 1a 1a  1a 1a 1a 1a  1a 1a 1a 1a  1a 1a 1a 1a  ........ ........
19:21:46.836 -> 0050: 1a 1a 1a 1a  1a 1a 1a 1a  1a 1a 1a 1a  1a 1a 1a 1a  ........ ........
19:21:46.836 -> 0060: 1a 1a 1a 1a  1a 1a 1a 1a  1a 1a 1a 1a  1a 1a 1a 1a  ........ ........
19:21:46.871 -> 0070: 1a 1a 1a 1a  1a 1a 1a 1a  1a 1a 1a 1a  1a 1a 1a 1a  ........ ........
19:21:46.871 ->
19:21:46.871 -> >d0000 007f
19:21:53.355 -> 0000: 12 0a 0a 0a  5a a2 1a 1a  1a 1a 3b 5d  1a 1a 08 f0  ....Z... ..;]....
19:21:53.393 -> 0010: 1a 1a 1a 1a  1a 1a 1a 1a  2f 1e c1 1e  1a 1a 1a 1a  ........ /.......
19:21:53.393 -> 0020: 1a 1a 1a 1a  1a 1a ff ff  1f ff ff ff  ff fa ff ff  ........ ........
19:21:53.393 -> 0030: dc 2f 12 da  1a ff 1f ff  1a ff 1a ff  1a ff ff ff  ./...... ........
19:21:53.393 -> 0040: 9a da da ff  ff ff ff ff  ff ff ff ff  ff ff ff ff  ........ ........
19:21:53.393 -> 0050: ff ff ff ff  ff ff ff ff  ff ff ff ff  ff ff ff ff  ........ ........
19:21:53.393 -> 0060: ff ff ff bf  ff ff ff fa  fa ff ff ff  ff ff ff ff  ........ ........
19:21:53.424 -> 0070: ff ff ff ff  ff ff ff ff  ff ff ff ff  ff ff ff ff  ........ ........
19:21:53.458 ->
19:21:53.458 -> >d0000 007f
19:22:02.620 -> 0000: 41 42 43 44  45 46 47 48  01 02 04 08  10 20 40 80  ABCDEFGH ..... @.
19:22:02.620 -> 0010: 7f bf df ef  f7 fb fd fe  00 ff 55 aa  30 31 32 33  ........ ..U.0123
19:22:02.620 -> 0020: ff ff ff ff  ff ff ff ff  ff ff ff ff  ff ff ff ff  ........ ........
19:22:02.620 -> 0030: ff ff ff ff  ff ff ff ff  ff ff ff ff  ff ff ff ff  ........ ........
19:22:02.658 -> 0040: ff ff ff ff  ff ff ff ff  ff ff ff ff  ff ff ff ff  ........ ........
19:22:02.658 -> 0050: ff ff ff ff  ff ff ff ff  ff ff ff ff  ff ff ff ff  ........ ........
19:22:02.658 -> 0060: ff ff ff ff  ff ff ff ff  ff ff ff ff  ff ff ff ff  ........ ........
19:22:02.658 -> 0070: ff ff ff ff  ff ff ff ff  ff ff ff ff  ff ff ff ff  ........ ........
19:22:02.692 ->
```

MarkC0x, 2020-05-19:
I just wanted to circle back on this, and let folks know that I solved my issue.

As it turns out - and probably unsurprisingly - it was human error on my part.  I am using the AT28C256 EEPROM, and I neglected to properly connect the additional (unused) address lines to ground (hence leaving them floating).  That explains the strange reads which would eventually become correct.

Feeling somewhat embarrassed, so I'll leave by the side entrance now :-)

TomNisbet, 2020-05-19:
I was just about to reply that the write was clearly working because it eventually returned the correct data on the read.  Would have suggested a short delay in PromDevice28C before the readData to let everything settle.  But your explanation makes a lot more sense!

Glad you got it working.  Why do you have unused address lines?  My design connects all 15 to the shift registers.  Are you just doing a single shift register to do 256 bytes of EEPROM space?

MarkC0x, 2020-05-20:
I wish I could say it were that simple, but I have two shift registers and it was just laziness on my part.  I was in a mental rush to show something working, so didn't connect all the EEPROM pins yet.  Then when things weren't working I went straight to code (and timing) debugging. TIL

TomNisbet, 2020-05-22:
@MarkC0x - Is everything working now?  I'll close the issue if so.
The mailman just brought me some 595s, so I'll build a version with those so I can debug everyone using the Ben Eater design,

Speaking of which, I'm building a breadboard computer right now and am dusting off this EEPROM project to do the microcode.  Expect to see a new project soon for that.

MarkC0x, 2020-05-22:
Hey @TomNisbet, yeah all is good now, so this issue can be closed (and apologies for hijacking the original issue from @8BitMark).  The 74HC595s work great as an alternative shift register.

Totally looking forward to your new computer project --that's next on my to-do list, so it would be awesome to follow along with your progress!

Closed 2020-05-26.

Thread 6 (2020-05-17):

Can't unlock AT28C256

Lx32, 2020-05-17:
I can't unlock my AT28C256 with TommyPROM. I'm using two arduino one, one for the real code and one emulating the two shift register, but thare aren't any problem in reading the eeprom. If I use the unlock command and after the zap command it prompt me a writing error.

TomNisbet, 2020-05-17:
I've never tried anything like that.  The unlock code can be very picky about the timing and some manufacturers chips are more sensitive to this than others.  Make sure that your two arduino solution is still writing the bytes within the specified time windows.  Th README-28C file has more details.

Also, be sure to double check your bus wiring to make sure you don't have any pins swapped or shorted so that you are certain that the correct unlock sequence is being written.  Maybe verify this be removing the 28c256 and adding delays to observe the write sequence with LEDs.  Or, if you have any existing ROM chips laying around, you can read them to see if the data looks reasonable.

Lx32, 2020-05-17:
I tried using the hardware HardwareVerify and there is something odd in addressing (the second arduino), so I think that will be better if I wait the shift register. Thanks so much for the help.

Lx32, 2020-05-26:
Today are arrived the shift register, but I've the same problem. I've already checked twice the connection and rodone the entire schema but the unlock dowsn't work

TomNisbet, 2020-05-26:
@Lx32  - If you send more information I may be able to help you track it down.

- Which shift register chips are you using?  My schematic uses 74LS164, but others have also successfully used 74LS595 with some modifications.

- Which EEPROM are you using - part number and manufacturer.

- What is the output of a "D0 F" command after a Zap command?
A copy of a session with the following commands would help:
D0 F
U
Z
D0 F

Also, make sure you have compiled the code for the correct chip family in configure.h.  It will print as part if the menu header, like "TommyPROM 2.0 - 28C series EEPROM".

You may also want to try the hardwareverify sketch without an EEPROM installed to check the data and address lines with a multimeter or scope or even an LED or two.  Make sure that the address and data lines are in the correct order and that there aren't any shorted together.  If there is a problem with the address or data then the unlock sequence won't be correct.

Also, watch your wiring lengths.  My first build used a ribbon cable for the data bus and it was very flakey.  I changed it to use the shorter wiring in the photos and it worked better.  This was still during development, so it may be unrelated, but better safe than sorry.

A few people have been using this design and we've always managed to get it working.  I'm sure we'll figure yours out too.

Tom

Lx32, 2020-05-27:
- The shift register are SN74LS764N

- The EEPROM is a Atmel AT28C256-15PI, but i bought from a chinese store on Ebay so I don't know if is genuine

- D0 f -> ff ff ff ff  ff ff ff ff  ff ff ff ff  ff ff ff ff
  U -> Writing the unlock code to disable Software Write Protect mode
  Z ->ERROR: Write failed
  D0 f -> ff ff ff ff  ff ff ff ff  ff ff ff ff  ff ff ff ff

The header is RommyPROM 2.0 - 28C series EEPROM so it's the right version I think

Thank you for the support
-Luca

TomNisbet, 2020-05-31:
@Lx32  - Atmel chips should definitely work, I use those all the time with no problems.  I suspect that your chip is locked and that the unlock code isn't getting through correctly.  Otherwise I'd expect to see that the zap command would change something, even if there were some address or data lines switched around.

This makes me suspect either a wiring or timing error.  If you have added any additional delays that are not in my code then take them back out.  The unlock command can be very sensitive to timing.

If you are running the stock code, then the timing shouldn't be an issue.

Use the Hardware Verify sketch to scope out the connections.  Without the chip installed, use the A command with a meter, scope, or even some LEDs to verify that each bit in the address can be set and that no other bits are set at the same time.
 Measure at the EEPROM location, not at the arduino.

So do:
A0 - [no bits set]
A1 - [A0 bit set, no others set]
A2 - [A1 bit set, no others]
A4 - [A2 bit set, not others]
A8 - [A3 bit set, no others]
A10 - [A4 only]
A20 - [A5 only]
A40 - [A6 only]
A80 - [A7 only]
A100 - [A8 only]
and so on up to A4000 to verify the A15 bit.

Then do the same with the D0,D1,..D80 commands to verify the D0 to D7 pins at the EEPROM.

Finally, use the W, O, and C commands to verify the Write, Output, and Chip enable signals.

Put some 0.1 or 0.01uF caps on the power rail near the chips.  I didn't draw it in the schematic, but you can see them in the picture.

If the individual connections are good, the sketch has been tested by many people, so it should be able to work.  Bad wiring or a cheap breadboard with flakey connections may be a culprit, but that's not something I can debug from here.

I'm assuming that you are running the same 74LS164 that I am using, not a 74LS764,

If you post pictures of your build somewhere and post the link here, I'm happy to take a look to see if anything looks odd.

Good luck!
Tom

Lx32, 2020-06-02:
I don't know why but if I use an A command, like A0, it will pul up all the A line. Same with D

Lx32, 2020-06-13:
I've just redone the test, putting any A command will pull up all the address line

TomNisbet, 2020-06-14:
First off, someone just pointed out to me the schematic on github doesn't show the power and ground connections on the shift registers.  Have you got +5 connected to pin 14 and GND to 7?  That would definitely cause problems if it were missing.

Otherwise:
The A command is clocking bits into the shift register from the arduino.  If you see nothing but HIGH on all of the shift register outputs then that suggests that either the clock or the data pins aren't connected correctly.  Check that pin 1 of both shift registers is connected to A5 on the arduino and that pin 8 of one shift register is connected to A3 and pin 8 of the other to A4.  For your debugging, concentrate on the chip that is connected to A4 because it is the lower bits of the address and those will change with every A command.

You could add an LEDs and resistors to the A4 and A5 lines to see the pulses if you slow down the clocking to the shift registers.  Change the code at the bottom of PromAddressDriver.cpp from this:
```
        // Toggle the clock high then low
        PORTC |= mask;
        delayMicroseconds(3);
        PORTC &= ~mask;
        addr <<= 1;
````
to something with a longer delay, like this:
```
        // Toggle the clock high then low
        PORTC |= mask;
        delay(100);
        PORTC &= ~mask;
        delay(100);
        addr <<= 1;
````
Other than that, the offer still stands to look at your wiring.  Post a few pictures somewhere and put the link here so I can see them.

Good luck!

Lx32, 2020-06-16:
Here are the photo of my wiring
https://ibb.co/SXZkNW2
https://ibb.co/KNFJLPM
https://ibb.co/kQ9659Y
https://ibb.co/FDpTj5H
https://ibb.co/nD0fhnk

I've rechecked all the wiring but i didn't see any changes.
Thanks for your time.

Lx32, 2020-07-01:
Any news?

aemiller51, 2020-07-16:
Hi Lx32
I can see that you are using the following colour coding
Yellow - chip control (A2,A3, a4)
green/brown - address lines
blue/purple  - data lines
red  - +5v
black - Gnd

it's pretty hard to check things out as they are covering the breadboard.  Any chance you can tidy them up a bit and post another pic?

TomNisbet, 2020-07-17:
I added a new section to the troubleshooting document that gives a detailed list of commands and expected results.  This will help if you have a missing or crossed line or two lines shorted together.  Try the steps here and see if you get the expected results:
https://tomnisbet.github.io/TommyPROM/troubleshooting/

The steps are broken into sections: data, address, and control, so that should help isolate the problem.

I looked at your wiring to check some basics, like power and ground connections to the shift registers.  Beyond that, it is difficult to trace and specific connections.

If the troubleshooting steps above all check out, then there may be a noise problem that would only be fixed by cleaning up the wiring.  Run all of the troubleshooting steps and we'll go from there.

@aemiller51 - thanks for your help!

Lx32, 2020-07-17:
I tried the command, also connecting some led directly to the arduino. But if I une D0 the data led went all up. I don't know why... If can help I use a Genuino Uno, the european version of the split.

@aemiller51 yes, the color code is right, unfortunately this is the only bb that I have

TomNisbet, 2020-08-24:
@Lx32 - I just checked in a fix for some command parsing problems in the HardwareVerify tool that may have been causing problems for your debugging.  It's never good when the debug tools have bugs!  The problem and solution are described in Issue #13.

Closed 2020-09-27.

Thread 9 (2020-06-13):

Schematic error

squelch41, 2020-06-13:
Thank you so much for designing this and putting it on GitHub - just built one to program a 28C512 to update a 486 motherboard bios.

There is a minor error in the schematic diagrams - the logic shifters dont have their ground and vccs connected - for me at least, not connecting these resulted in no read/writes.

Thanks again!

TomNisbet, 2020-06-13:
Hmmm, the templates I used for the shift registers don't even show the power connections.  I think that's pretty common for simple chips like NAND gates and the like.  They are probably automatically connected if the schematic is used to produce a board layout.

I'll take a look to see if that can be added to the schematic, or at least will add a note to the text about it.

Can you tell me which manufacturer name is on your chip?  There is some variation in the 28C chips by different manufacturers and it is good to know if someone has had success with a chip I haven't tried.

Glad it worked for you!

squelch41, 2020-06-14:
It was a X28C512D-15 made by XICOR
32pin DIP package

Was also able to read an old, presumably 27C512 amibios 1994 EPROM in a 28pin package (no markings on the chip itself - maybe under the label but dont want to remove)

Wired up pin 13 of the second shift register to the A15 pin

Then depending on which chip I was using, moved the VCC and connected the WE pin for the 28C chip (didnt bother for the 27C for obvious reasons!)

Closed 2020-06-25.

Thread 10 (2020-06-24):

Errors with AT28C256

squelch41, 2020-06-24:
Hi,
I'm having problems with reliability writing to an atmel AT28C256 eeprom

About 5% of the time I can write, 95% of the time, it will fail at various points, usually below 50% but not at a consistent packet number.

Reading is fine and writing to the a xicom 28c512 is fine (i've moved the address lines to the right point for the 256).

I notice in your pcitures of your board you have some capacitors - are these to improve reliability? If so, which pins are they on?

Thanks

TomNisbet, 2020-06-24:
My current board with an Arduino Nano has .1uF capacitors from the Vcc lines of each of the chips to ground for noise reduction.  There is also a 47uF capacitor across the power and ground bus near the 5V line from the Arduino. Keep the leads as short as possible for all of the capacitors.  I'm more of a software guy than hardware, so these were just stolen from other designs rather than carefully calculated values.

I'm using my board with Atmel 28C256 eeproms right now for a Ben Eater breadboard computer and it has been very reliable.  Try to keep the wires short - my original build used pre-made jumpers and was not very reliable.

You can also try writing in byte mode instead of block mode.  It will be a lot slower, but might give different results you are just trying to get a chip burned to get on with your project.  Change the line near the top of TommyProm.ino from

```PromDevice28C  prom(32 * 1024L, 64, 10, true);```

to

```PromDevice28C  prom(32 * 1024L, 0, 10, true);```

I'll get the capacitors added to the schematic the next time I'm in there.

I hope this helps!

Tom

squelch41, 2020-06-24:
Thanks - think my problem is probably long wires and the xicom chip was just a bit more forgiving!

squelch41, 2020-07-28:
Just got a xicor X28C256P-25 - writing seems to be much more reliable that the AT28C256 - guess the xicor chips are more forgiving.

Just thought I'd post in case future people have problems!

Closed 2020-08-19.

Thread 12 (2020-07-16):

Suggested enhancement

aemiller51, 2020-07-16:
Thanks for the EEPROM programmer design and code Tom. After a couple of hours debugging my vero board implementation it seems to be working quite nicely.

Sometimes I only need to write a few bytes to an EEPROM, usually to fix a bug in a subroutine, so I wrote a new command POKE, PSSSS BB BB BB.. up to BLOCK_SIZE bytes.  I mostly copied  existing code from the fillBlock Command but I am struggling with how to test for the end of the command line.  Using  **_while ((*byteString != 0) && (byteCtr < 32))_** cuts off the last argument.

I increased the size of the CLI command line buffer to accomodate this (132 characters) and added a switch to the CLI processing routine.

void pokeBytes(char *& byteString)
{
 uint32_t val;
 uint32_t start;
 int byteCtr;

 enum { BLOCK_SIZE = 32 };
 byte data[BLOCK_SIZE];

 //first value returned is the starting address
 start =  getHex32(byteString, 0);

 val = getHex32(byteString, 0);
 byteCtr = 0;

 while ((*byteString != 0) && (byteCtr < BLOCK_SIZE))
 {
  data[byteCtr++] = val;
  val =  getHex32(byteString, 0);
 }

 if (!prom.writeData(data, byteCtr, start))
 {
  cmdStatus.error("Write failed");
  return;
 }

 delay(100);
 for (int ix = 0; ix < byteCtr ; ix++)
 {
  byte val = prom.readData(start + ix);
  if (val != data[ix])
  {
   cmdStatus.error("Verify failed");
   cmdStatus.setValueHex(0, "addr", start + ix);
   cmdStatus.setValueHex(1, "read", val);
   cmdStatus.setValueHex(2, "expected", data[ix]);
   return;
  }
 }
 cmdStatus.info("Poke successful");
}

F 000 050 FF

>D 00 050

00000: ff ff ff ff  ff ff ff ff  ff ff ff ff  ff ff ff ff  ........ ........
00010: ff ff ff ff  ff ff ff ff  ff ff ff ff  ff ff ff ff  ........ ........
00020: ff ff ff ff  ff ff ff ff  ff ff ff ff  ff ff ff ff  ........ ........
00030: ff ff ff ff  ff ff ff ff  ff ff ff ff  ff ff ff ff  ........ ........
00040: ff ff ff ff  ff ff ff ff  ff ff ff ff  ff ff ff ff  ........ ........
00050: ff                                                  .

>P0000 01 4f 12 06 4c 24 20 0f 00 0c 08 60 72 42 30 38

POKEing bytes into memory

INFO: Poke successful

>D 000 050

00000: 01 4f 12 06  4c 24 20 0f  00 0c 08 60  72 42 30 ff  .O..L$ . ...`rB0.
00010: ff ff ff ff  ff ff ff ff  ff ff ff ff  ff ff ff ff  ........ ........
00020: ff ff ff ff  ff ff ff ff  ff ff ff ff  ff ff ff ff  ........ ........
00030: ff ff ff ff  ff ff ff ff  ff ff ff ff  ff ff ff ff  ........ ........
00040: ff ff ff ff  ff ff ff ff  ff ff ff ff  ff ff ff ff  ........ ........
00050: ff

TomNisbet, 2020-07-17:
@aemiller51 - very good!  I'm trying to get another project (breadboard computer) posted right now, but I'll revisit this when that is wrapped up - probably next week.

For that project, I developed an eXamine command that allowed interactive listing and modification of single addresses.  The interface is like the old 8-bit ROM monitors.  You enter an address and are prompted with the current value at the address.  If you type 2 hex characters, they are stored and it moves to the next address.  A return just skips to the next address, and any other character ends the command.  It looks like this:

**X0000**
0000 FF: **01**
0001 FF: **4f**
0002 FF: **<CR>**
0003 FF: **06**
0004 FF: **.**

The result would be that the bytes at 0000, 0001, and 0003 are modified.

The downside to this is that it doesn't work well with the Arduino Serial Monitor window because that requires a <CR> before any characters are sent to the target.  On the other hand, it is really convenient when used with a real terminal.  I like your command because it can be used in any terminal environment.

Maybe I'll port them both in and we can take a look.

Thanks for the addition.

TomNisbet, 2020-08-15:
I put this on the back-burner and forgot all about it.  Checking in a change today that implements the Poke command.  Utilized the default value option of getHex32 to fix the problem of the last argument being dropped.  Thanks to @aemiller51 for a very useful enhancement to the code!

Closed 2020-08-15.

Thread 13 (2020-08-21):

HardwareVerify - Minor documentation changes required to clarify use

NigelTwo, 2020-08-21:
The background to this is that I have built the TommyPROM hardware using 74HC595 shift registers. So with both hardware and software changes a bit of testing is needed! As a result I have discovered that the Troubleshooting documentation is misleading:
1. Testing the address lines - the table shows the commands A0, A1 etc to setup the address latches. But the correct commands are A000, A0001 etc. So all four hex digits are required as the program menu shows. See below for some examples of this.
2. Data test commands - look like they have the same problem. Always use 2 hex digits.
3. Testing the control lines - the 4th line in the table has a typo?  "Cd" should read "Od".

To illustrate the address line testing commands I added a print statement to the 'a' command processing code viz
`case 'a':

        if (hexDigit(line[1]) <= 15)
        {
            w = hexWord(line + 1);
            printWord( w );
            Serial.println();
            Serial.println( w, BIN );
            prom.setAddress(w);
        }
        else
            cmdError = true;
        break;`
Now the difference between A0 and A000, and A400 and A0400 can be seen.
`#a0
ffff
1111111111111111

#a0000
0000
0

#a400
40ff
100000011111111

#a0400
0400
10000000000

#`

IMHO the software bug (buffer over-read) doesn't need to be fixed. It is hardware testing code after all. Just adjust the documentation. It will have the side effect of reducing the confusion between A0 the command and A0 the 0th address line, and D0 the command and D0 the 0th data line.

Thanks for taking the time to design and document this project. It's encouraging to see proof that it will work in the end ;-)

NigelTwo, 2020-08-24:
@TomNisbet - I'll leave you to choose whether to port the changes into the Hardware Tool UI. The A0/D0 confusion is actually a triple context problem that does take a while to get one's head around:
1. the UI commands;
2. the (E)EPROM address lines;
3. the Arduino IDE pin defines (bless them, they meant well).

I am thinking that a new issue might be best for a discussion around the alternative shift register circuits.

Thanks for your offer of help, but I am pretty certain my variant of the circuit is working now. It is slower, and you have stressed the importance of speed wrt the EEPROM unlocking operations. What a surprise to find timestamps already in the code just about where I was to add them!

TomNisbet, 2020-08-24:
I checked in a fix so that the CLI parser matches what I thought it was already doing.  The documentation has been updated to clarify the distinction between the D5 command, the D5 data pin on the ROM, and the D5 output on the Arduino.

@NigelTwo - I also added code and documentation to support a 74LS595 variant of the hardware.  The RCLK pins on the shift registers are controlled by the D13 output on the Arduino.  The support needs to be enabled with an edit to the Configure.h file.  Details are in the Hardware page of the documentation.

NigelTwo, 2020-08-28:
@TomNisbet - I have run up the latest version of HardwareVerify. The A and D commands work correctly. Good.

Also, I see the documentation has been updated. The sub-scripting helps clarify the meanings. Another "tick" from me.

Closed 2020-08-28.

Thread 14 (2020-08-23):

Read and Xmodem-CRC save command failing with minicom (and suggested fix)

NigelTwo, 2020-08-23:
I built the TommyPROM project with the intention of archiving a pile of ~35+ year old EPROMs. I assumed that the Xmodem transfer works with some terminal program, probably on a Windows or Mac Operating System. But the transfer always failed on Ubuntu Linux using minicom (which invokes a unix program named rx to receive the file). Here is an explanation of the fault and a simple fix.

An Xmodem protocol explanation can be found by searching for e.g. "MIT XModem protocol with CRC". It is a character based protocol easily as old as my EPROMs!

The TommyPROM Xmodem.cpp source file has a function called SendFile() that controls the transfer. After the last packet is sent, it sends an EOT character and terminates with success, not waiting for the final ACK from the receiver. Two things now happen:
1. Control returns to the main loop() which finds there is a command status message to send. It immediately sends it (INFO: blah) to the Xmodem receiver, which looks like further packet characters to "rx". "rx" then chokes and starts to NAK and CANcel. Bad.
2. The positive ACK character is received by the main command loop and this causes the next user command in TommyPROM to fail (because the ACK character is in the command buffer) Worse, the ACK it has been echoed back to the Xmodem receiver. Phew!

A suggested fix is simple. Consume and process the character returned from the EOT packet in the SendFile() function before returning viz
`
    Serial.write(XMDM_EOT);

//  Consume the expected ACK response
    rxChar = GetChar(5000);
    if (rxChar != XMDM_ACK)
    {
        cmdStatus.error("Expected XModem ACK to EOT, but received:");
        cmdStatus.setValueDec(0, "char", rxChar);
        return false;
    }
    return true;
}
`
The command status message (INFO: blah) is still lost unless the terminal program is very quick to revert. But it is displayed on the next menu refresh.

Thanks again Tom for putting this all together. I sense success is close for me.

NigelTwo, 2020-08-24:
@TomNisbet - Just as well to verify the operation on TeraTerm (Windows only I see).

ATMega328 might only be a microcontroller, but it is astonishingly fast at producing serial data. By the time those "post EOT" characters have been buffered by the serial-to-USB chip, then the OS hardware driver, and finally delivered into the OS it will look like a data packet headed with EOT. Xmodem was originally a half-duplex protocol, so there must have been an inter-packet silence that we now have to reproduce. I am guessing that a "false EOT detector" is triggered in this situation.

FWIW I have found that minicom has to be configured with no hardware and software flow control. Also the Xmodem helper program, "rx", is not part of minicom (it is part of the lrzsz package) and needs the -c option (configured in minicom) in order to receive CRC16.

Yes, I have 2716 EPROMs queued up to be read. They will need Vcc wired to pin26/A13 for a starter. I intend reporting back about this later.

NigelTwo, 2020-08-26:
I verified the Xmodem transfer now works with minicom on TommyPROM V2.2 and v2.3.
I programmed a 32KB image to an AT28C256 with a modified version of TommyPROM V2.0. The modifications were to support '595 shift registers. I read this EEPROM back (>R0 7FFF) to my host system using the later versions of TommyPROM with the new support for the '595 shift registers. The binary file compares exactly with the original image file.
N.B. The support for the '595 shift registers is still being "ironed out", see #15. So some minor changes were required to the code. But these don't interact with the Xmodem save functionality.

Closed 2020-08-26.

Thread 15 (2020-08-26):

TommyPROM v2.2 '595 Shift Register code has introduced a bug

NigelTwo, 2020-08-26:
I downloaded the V2.2 code to verify the Xmodem fix.
Some new code has been added to support '595 shift registers. I enabled the define, and verified that my hardware was setup as per the revised documentation. Yes I had used D13 as the RCLK pin too. So no wiring changes were needed.
Eeek, it didn't work.

I think the problem is this define in PromAddressDriver.cpp that is used in setAddressRegister():
`// Define masks for the address clk and data lines on PC3..PC5 for direct port control.

#define ADDR_CLK_HI_MASK    0x80`

This was 0x08 in V2.0 of the code, where no define was used. Or am I going mad?

TomNisbet, 2020-08-26:
Good catch.  Of course my quick test worked because I just zapped a pattern in that didn't cross a 256 byte boundary!

NigelTwo, 2020-08-26:
@TomNisbet This is a good enhancement, so I am pleased to have helped.

NigelTwo, 2020-08-26:
@TomNisbet - The conditional code for the '595 shift registers is not being included in PromAddressDriver.cpp in my environment. Have to include the Configure.h???

Closed 2020-08-26.

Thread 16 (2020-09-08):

(Minor) - Confirmation that device successfully passed the multi-pass check.

NonDualChris, 2020-09-08:
It would be nice to have an on-screen confirmation to say that is has run a successful multi-pass check and that it is OK.
(Currently, it just drops the cursor on to a new line).

Thank you so much for the project - I've successfully built the device and it works . . . ish.
Stuggling to read 27128 chips . . . bizarre problem for another time . . .

NigelTwo, 2020-09-16:
@NonDualChris, This is in response to your "Struggling to read 27128 chips" comment.
Can you describe what you have built, and what you have tried that is successful. I have built this circuit (wire-wrapped) with the intention of archiving some 2716/32/64 EPROMs. I am waiting on a "softly softly, go gently" ZIF socket as my EPROMs are physically delicate. In the meantime I think I have programmed an AT28C256 EEPROM and read it back correctly.

The TommyPROM schematic shows the 28 pin programming socket wired for a 28C256 device. But there are some pinout conflicts when 27xx(x) devices are used. To be fair, Tom has warned that the 27' device support is "Rev 0".

For the 27128 device, it looks like there might be a problem with pin1 viz.
```
     27128 28C256               28C256 27128
pin1=Vpp   A14            pin28=Vcc    Vcc
pin2=A12   A12            pin27=/WE    /P
...                       ...
```
So maybe the 27128 device will only produce data when pin1 is high. The datasheets indicate that current is drawn from this pin during a read operation.

You could experiment by either:
1. hard wiring pin1 to Vcc (easily done if you breadboarded the circuit), or
2. reading an address range that has A14 high. So instead of reading 16KB as 0000-3FFF, read 4000-7FFF. I cannot see any restrictions in the code that prevent this alternate address range.

TomNisbet, 2020-09-19:
I'm not sure what the original issue is here.  Are you referring the the Test command?

As far as 27xx devices go, you should be able to read them just fine.  The "Rev 0" support refers to some limited success I've had with writing them.

Yes, you definitely need to check the data sheets to swap around a few pins, usually the high order addresses.  The code will support address lines A0..A15 using the shift registers, plus A16..A18 wired directly to Arduino pins.  This lets you read chips as large as 512K bytes in a single operation.

You'll need to connect your Vpp pins to something.  If I remember correctly, most chips want it at Vcc in read mode, but check the data sheets.  I've used this to dump a bunch of old chips I had, including 27C040, 29C010, 29C040, 27C001, and 2764.

Closed 2020-11-27.

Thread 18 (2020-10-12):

74LS595 variant not working

TomNisbet, 2020-10-12:
The address shift registers are not working when using 74LS595 hardware.  See this thread: https://www.reddit.com/r/beneater/comments/j83zu1/using_tommyprom_28c256/

TomNisbet, 2020-10-12:
The PromAddressDriver file was not including configure.h, so it never saw the conditional include for IS_595.  Removed the conditional code so that the default build works for either 164 or 595 hardware.  This pin that is used by the 595's isn't connected to anything on the 164 hardware and the additional software only adds milliseconds to a 32K burn, so there is no point in not just including the code by default.

Closed 2020-10-12.

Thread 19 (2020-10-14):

Change XModem to use checksum instead of CRC16

TomNisbet, 2020-10-14:
The original TommyPROM code used the XModem-CRC variant of the protocol that calculates a 16-bit CRC instead of the default 8-bit checksum.  While this does perform a more thorough error-check, it is not really necessary when doing communication over a 3-foot USB cable.  While the CRC version of XModem is well-supported in TeraTerm for PCs, it is problematic with minicom and other Linux software that relies on the sz/rz package.

The default code will now use basic XModem instead of XModem-CRC for file transfers.  For compatibility, the XModem-CRC code is still available as a compile-time option.

See this thread for the journey: https://www.reddit.com/r/beneater/comments/j83zu1/using_tommyprom_28c256/

Closed 2020-10-14.

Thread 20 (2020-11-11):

XModem checksum failing with TeraTerm

TomNisbet, 2020-11-11:
The fix for #19 has broken TeraTerm support.  It seems that TeraTerm does not like to send files when TommyPROM asks for checksum mode instead of CRC mode.  The TeraTerm dialog shows that it is using checksum mode, but the checksum calculation on TommyPROM fails.  Will need more investigation to determine the failure point.

In the meantime, the default file transfer prototol is now back to XModem-CRC for TeraTerm compatibility.  Linux users will need to comment out the CRC #define at the top of XModem.cpp to use checksum mode instead.

Discussion here:
https://www.reddit.com/r/beneater/comments/jsf1hk/tommyprom_xmodem_sendwrite_problem/

NigelTwo, 2020-11-14:
@TomNisbet. Is it possible that the reason XMODEM/CRC is supported in TeraTerm, is that it was used by Cisco routers as the "bare metal" recovery method. I personally have never encountered the protocol anywhere else since the dawn of the 21st century.
I was reading through "XMODEM/YMODEM PROTOCOL REFERENCE, A compendium of documents describing the                           XMODEM and YMODEM File Transfer Protocols. Chuck Forsberg 10/14/88"  (that's 1988). It seems that the XMODEM protocol quickly became fractured as everyone tried to fix the problems in the original. I think Chuck wanted to move onto a newer protocol quickly. So XMODEM/CRC was probably as "good as it got" for a half duplex data transfer protocol that worked over acoustically coupled 300bps modems.

TomNisbet, 2020-11-14:
After building some homemade serial monitors with an Arduino Mega I think I've finally gotten to the bottom of this.  In checksum mode, TommyPROM sends one or more NAK characters to start the transfer. TeraTerm seems to buffer one of these NAK characters and use it as an indication that the first packet should be sent again.  This resend happens while TommyPROM is busy writing to the EEPROM and that causes the Arduino's 64 byte buffer to overflow and gets the transfer out of sync.  It isn't a problem in XModem-CRC because the start character is not the same as the NAK character.

The problem was fixed by looking for additional characters in the serial receive buffer after a full packet has been received. Normally the buffer should be empty because the sender is waiting for a response before continuing with another packet.  If TommyPROM detects characters in the buffer after the first packet, it flushes the buffer to get back into sync and sends a NAK to tell the sender to continue with the transfer,

This has all been tested in both the default checksum mode and in CRC mode with both TeraTerm and minicom.  Both are able to send and receive files with no errors.

@NigelTwo - I'm putting the default back to checksum mode because that works with minicom without changing the transfer parameters and also means that you don't need to remember to check the CRC option in the TeraTerm transfer dialog box.  It's fortunate that I randomly chose CRC mode when writing the original code because I would have never tracked this problem down and probably would have given up on the whole thing.

As an aside, I spent many years working on a CSU/DSU product that connected to Cisco routers.  Every time I went to configure one of those things in the lab, the one hour project always turned into a one day project because the router wouldn't have the right software version for the feature I needed and then wouldn't have enough RAM or ROM for the new software release.  It was always an adventure.  Also, our product had a similar bare-metal recovery mode, but if I think it used ZModem if IIRC.

NigelTwo, 2020-11-15:
@TomNisbet. You wrote: "TommyPROM sends one or more NAK characters to start the transfer" as the root cause of this issue.

In previous versions the Xmodem::StartReceive() method emitted a "start" character every 1second. I notice this has been extended to 3s in the current checked in  code. Even this might be too aggressive. The reason is because we (the users) all initiate the receive function on the TommyPROM Arduino, then switch to our TeraTerm/minicom and begin fumbling around in menus and selecting files etc. Many seconds pass... and the start characters accumulate.

A quote from the document I was reading yesterday might be a hint:
"7.3.2  Receive_Program_Considerations
The receiver has a 10-second timeout.  It sends a NAK every time it times out.  The receiver's first timeout, which sends a NAK, signals the transmitter to start.  Optionally, the receiver could send a NAK immediately, in case the sender was ready.  This would save the initial 10 second timeout.  However, the receiver MUST continue to timeout every 10 seconds in case the sender wasn't ready.
 Once into a receiving a block, the receiver goes into a one-second timeout for each character and the checksum.  If the receiver wishes to NAK a block for any reason (invalid header, timeout receiving data), it must wait for the line to clear.  See "programming tips" for ideas.

I am not sure that I can get my terminal program into sending mode even in 10seconds!

Regarding the recovery (buffer flushing) and getting back into sync, better check what packet number TeraTerm resends - 01 or 02? Or am I being too paranoid here? sorry but I haven't looked into that part of the TommyPROM Xmodem code. Hopefully TommyPROM doesn't process the received packet if it finds more incoming data pending. I think you said that in your last comment.

TomNisbet, 2020-11-16:
I did originally set the receive start timeout to be longer but then there could be as much as a 10 second delay before the transfer started.  If I connect two computers directly that are running TeraTerm and minicom they start the transfers very quickly, so I don't think there is any harm in the current code.  I probably could get rid of the initial NAK because, as you point out, no one is going to be able to start their transfer immediately.  At this point I've tested it pretty extensively and don't want to go poking around again unless someone is reporting a problem.  I'd be just as likely to muck something up. Besides, I really want to get back to my 8-bit build.

Regarding the processing, it is checking and discarding extra characters after receiving the first packet.  The first packet itself is fine, the sequence numbers and checksum are all valid.  The problem is that while the code is busy writing that packet to the EEPROM, the sender is pushing another packet down the line because it thinks it has a NAK.  This overflows the Arduino buffer and everything is out of sync after that.

To detect this condition, the TommyPROM code now pauses after a packet is received to see if any more characters are coming in.  This should never happen because the sender should always be waiting for a NAK or ACK after sending a packet.  If there is extra data after the first packet, the code just eats it and NAKs to get back into sync and then everything continues normally.  If extra data is received beyond that, then the transfer just fails because something else is clearly wrong.

This was an interesting problem to debug.  It definitely took me back to technology I haven't worked on in many years.  I wish I had one of those old serial communication analyzers to capture and display everything.  That would have been a lot easier than my hacked together Arduino Mega capture setup.  Of course, those old analyzers probably wouldn't have had a setting for 115200!

Thanks for looking into this.  Its nice to have another set of eyes on the problem.

Closed 2020-11-27.

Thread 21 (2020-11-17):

595 shift registers and code

halak77, 2020-11-17:
Instructions say to uncomment  #define SHIFT_REGISTER_IS_595 in Configure.h
I do not see this in Comfigure.h nor do I quite see how it requires this when I look at. The adrressing code ( it appears that the 595 rclock is toggled whenever an address has been shifted.  However my attempt of building programmer does not seem to be updating the address (writes and reads one value to entire room.
Thanks for any help.

TomNisbet, 2020-11-17:
I removed the conditional code as part of the fix for #18 but missed that comment that mentions it. I’ll update the code to remove comments a that reference it.

The code should work with either type of shift register without modification. If your addresses aren’t updating you can try the hardware verification sketch to help track it down. Also, be sure to ground the OE pin on the shift registers. On some datasheets this pin is marked as G instead of OE.

Are you sure you are writing the same value to the entire ROM? Or does it just look that way because the addresses don’t change?  What it the output if you do a Z0 command followed by D0?

halak77, 2020-11-17:
That is how the code appeared to me ( no conditional) I am starting to think my problems are the use of an old prototype board, that and my workbench is to cluttered to work there ( with o scope) I found that I had the rclk line connected to the srdata line. After I fixed that ( and checked my work once again, I still it writing same data everywhere. I am not at home, but I am guessing I missed the OE on the s/r—- doh! Thanks for help. I will let you know how it works out. Thanks also for your efforts.

Don Peddicord

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

halak77, 2020-11-27:
Tom,
Again thank you for shariig your code. I went to a soldered build on a proto board. Once I solved the bad solder joints, I still had trouble . It turned out that I needed pull ups on the shift register reset lines (I would have paid to read the data sheets, I thought these were same as to but I was wrong, unconnected inputs do not pull themselves up!
Again thanks for your code and your help.
Best regards,
Don Peddicord

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

TomNisbet, 2020-11-27:
Don,
I'm glad its working and that you have found this project helpful.  I've been helped by countless projects that other have put up and it's nice to know I've managed to give one back.

I updated the documentation to mention the RESET pin on the shift registers.  If the update still isn't clear or you see anything else that might save time or frustration for the next person, please let me know.
Tom

Closed 2020-12-21.

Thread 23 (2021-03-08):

can it run in arduino mega? because mega has alot of gpio, no need other ic.

youxiaojie, 2021-03-08:
can it run in arduino mega? because mega has alot of gpio, no need other ic.

TomNisbet, 2021-03-08:
There is no current version for the mega, but the code is very modular and it wouldn't be too difficult to make a mega version.

There is some low-level code written specifically for the Uno/Nano to meet the timing requirements for the EEPROM chips.  To run on a mega, you'd need to modify the port-specific code in PromDevice.cpp to match the mega ports.  You would also need a new version of PromAddressDriver.cpp, which would be much simpler than the original one because it would just need to put the address out on some pins instead of driving the shift registers.

youxiaojie, 2021-03-08:
1 the specific code is mainly in adress driver? which needs time sequence?
2 is there difference between 27/28/29/39 series of eeprom/flash?

TomNisbet, 2021-03-09:
The address driver contains the code that sends the EEPROM address using the shift registers.  You could replace this with code that just writes the address directly to the appropriate pins on the Mega.

There shouldn't be any timing dependencies when reading or writing the chips if you are doing single byte writes.  The chip-dependent timings happen when you are using block write modes.  Specific timing is also needed when sending SPD unlock codes, like with the 28C families.  If you set the block size to zero when declaring the target chip, then block writes won't be used and there shouldn't be any timing-specific code.

With that said, you will probably need to make some adjustments to the code in PromDevice.cpp.  There are routines there, like readDataBus and writeDataBus, that use direct port access to PORTB and PORTD instead of using a set of the much slower digitalWrite calls.  Unless you can use the same ports on the Mega that were used on the Uno, those calls won't work without some modifications.

Good luck with your project.  I have a Mega here, but never tried to use it for TommyPROM.  There is no reason it wouldn't work, and the design would definitely be much simpler.

wpcarro, 2024-06-09:
@TomNisbet would you be open to a pull request if I give this a try?

TomNisbet, 2024-06-09:
It may be difficult to come up with a clean way to have both the mega and the nano/uno in the same code base. It feels like there would be a lot of #ifdefs, but maybe it will be cleaner than I’m imagining.

TomNisbet, 2024-06-09:
On second look, maybe not too bad. It looks like the direct hardware writes are just in the PromDevice base class and in the address driver. If you are able to keep the hardware using the same Arduino pin names for the control lines, i.e. WE, CE, and OE, then the changes might be fairly localized.

I don’t have access to the code for a few days, so I’m only able to peek at the repo on a tablet. I may be missing something.

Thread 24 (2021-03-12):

74HC595 Shift Registers always on

Tohaker, 2021-03-12:
Hi, I've built the programmer exactly as described, quadruple checked all the connection and loaded the latest version of the code onto my Arduino Nano ([this one to be specific](https://www.elegoo.com/products/elegoo-nano-v3-0)), but still the shift registers only output high values, regardless of what I enter into the HardwareVerify program.

OE pins are held low, and SRCLR pins are held high, all as described here and in data sheets - is this something you've seen before? I'm wracking my brain to think what it could be and all I can think is that something in the code is not working

Tohaker, 2021-03-12:
Never mind, a solder joint on the board was poor - A5 no less

Closed 2021-03-12.

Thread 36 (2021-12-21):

5.5 volts , USB volts , VCC volts

haroldmoore, 2021-12-21:
There is 5.5v marked on the Nano, what is VCC then? I'm thinking on getting two little charge pump boards for the 5.5 an 25.5 volts
no?

here is a video I made -----> https://youtu.be/NpmLo4B8duw

Thanks in advance!

TomNisbet, 2021-12-21:
Sorry for the confusion.  I'm not sure why the library labels that Arduino pin as 5.5V.  It is labelled as 5V on the silkscreen of my Unos and Nanos.  Vcc should be 5V and it should connect to both the Arduino's 5V pin and the 8755's Vcc.

The data sheet says that the 8755A wants Vcc between 4.75V and 5.25V.  The Vdd pin should be at 25V for programming and 5V (Vcc) for reading.  Because the circuit that switches the voltage on the Vdd pin will drop a fraction of a volt through the diode, I fed it 5.5V and 25.5V from a bench power supply.  I very rarely need to program an 8755, so this was convenient for occasional use.

You could *probably* get away with using the same 5V input as both the Vcc and the low voltage input to Vdd.  The voltage drop depends on the diode you use.

Similarly the programming voltage needs to be 25V +/- one volt, so if you have a convenient 25V source, then the switcher is going to drop it less than one volt and you'll still be in spec.  Because I had an adjustable supply, I just dialed in the two Vdd voltages until the switcher output gave me the ideal 5V and 25V.

Good luck with your project and feel free to reach out if you have any questions.  Are you building and 8085 system?  That was the brains of my first-ever computer.

-Tom

haroldmoore, 2021-12-22:
Tom,
          Thanks for clearing that up for me! I've ordered a couple of
adjustable charge pump modules to
           finish the project for my intel SDK-85 board, I'll have two
programmers, one for the second position
           8755A and the other for a large flash prom that uses the
extended memory drivers. The issue is getting
           programs into the system fast enough and still be able print out
on my 110 baud ASR33 teletype.
                     An educational system for the kids at school maybe,
because there are a LOT of  beginning curriculums
           on the 8085, say could you point me to where I could change the
memory printouts to be all upper-case in
           the code?

           Thanks in Advance!

           Harold

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

TomNisbet, 2021-12-22:
Do you want to uppercase the hex dump or something else?  If it is the hex dump, just change the hex[] array in TommyPROM.ino around line 72.

haroldmoore, 2021-12-22:
Tom,
           Ah great that fixed the hex dump! ok just waiting for the charge
pump modules to
           test the programming, I put an 8355 in and it read this ok as
well, don't have any to
           program since there OTP. ok I put a note at the top comment
section, here are some pictures:

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

Closed 2022-12-17.

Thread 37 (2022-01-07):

Programming a 27C040 - will this work

danriches, 2022-01-07:
Hi Tom,

I would like to program a couple of 27C040 EPROM's and would like to know if your programmer will work? I see in the code for the 27 series that there's a write function hence why I asked as it's not stated in the readme that it does yet.

Kind Regards, Dan

TomNisbet, 2022-01-20:
Dan,

The 27C write algorithm is fairly straightforward, but I don't remember if I've actually programmed any chips with it.  The bigger issue is that these chips require a 12.75V on Vpp, although it doesn't need to be switched on and off.  The Fairchild data sheet I have also mentions using a 6.5V for Vcc while programming.  I'm not sure how strict that is and if you could get away with using 5V.  I'll have to see if I can dig up a better datasheet for the chip, because the one I have has the Vpp and Vcc voltages swapped in some parts of the documentation, so I'm not completely confident it is correct.

With all of that said, I suspect that the code would work if you can wire up a power supply for the Vpp and are careful to apply the voltages to Vcc, Vpp, and PGM in the right order.

I have an NM27C040Q in the parts bin here, so I may wire it up and try it.

5arid, 2022-09-01:
to program 27C0xx EPROMs you can use this :
https://forums.nesdev.org/viewtopic.php?p=256197#p256197

wjhun, 2023-07-15:
Just a note that I managed to successfully write to an AM27C040 device using a TommyPROM, with only a slight change to the PromDevice27 line used for this device (see #57).

Thank you, @TomNisbet, for this fine project!

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

TomNisbet, 2023-07-21:
Glad it was helpful!  Thanks for the update.

Closed 2024-05-29.

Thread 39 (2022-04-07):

Using TommyPROM as basis for slightly odd flash rom board

AJRubenstein, 2022-04-07:
Hi Tommy,

I'm trying to build a reader/writer for a 128mbit ROM board that uses a 72 pin SIMM based pinout (essentially, it's two SOP44 64mbit NOR Flash chips in parallel, so it's got 32 data lines and 22 address lines). This is quite a bit bigger than an EEPROM! But I was hoping that since it's fairly simple in scope, that the TommyPROM concept would work with more shift registers.

What I wanted to know, as a fairly green electronics person to someone who is a little more experienced, am I barking up the wrong tree here, or do you think this is possible?

Thanks,
AJ.

Closed 2022-12-17.

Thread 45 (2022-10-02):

W27C512

Henkvd72, 2022-10-02:
Hellom love the project, i am builing one but a have a question,
can it programm the Winbond W27C512?

TomNisbet, 2022-10-02:
Good timing on your question.  I have not tried that chip, but I have some Winbond 27C257s on order which use the same algorithms.  These do need 14V to erase and 12V to program, but they don't require a a pulse at this voltage, so it should work to just apply the voltage manually as described in the [27C-EPROM](https://tomnisbet.github.io/TommyPROM/prom-families/#27c-eprom) section.  They chips should be in next week, so I'll post an update after I've had a chance to look at them.  The current 27C code does not implement the erase command, so that will need to be added.  There may also be some changes to the programming algorithm if it is significantly different from the EPROM versions.

TomNisbet, 2022-12-17:
The 27C257 code has been tested and checked in, so I suspect the W27C512s will now work with that.

Closed 2022-12-17.

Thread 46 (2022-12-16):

Problem transferring files from a Mac

srayner, 2022-12-16:
Hi Tom, I wonder if you can offer any advice on my issue.

I'm on a Mac. I have installed lrzsz using Brew. I then use the screen command to connect to the TommyPROM. Press w and enter, then press ctrl+A, then type
:exec !! lsx -b -X /path/to/my/file

It seems to start sending, fails on the first few bytes, then seems to successfully send until it reaches 65536.

What I think is happening is that the first few bytes are my small test program, and the remaining bytes are probably all zeros. I wonder if the checksum is failing for the bytes containing my program, but succeeding for all the zeros. Just a guess.

I get a success message at the end, but the result is a chip full of zeros.

I have tried with the XMODEM_CRC_PROTOCOL commented out/in and seem to get the same results.

Any advice is appreciated.

>w
Send the image file using XMODEM CRC
CCCCSending /Users/steve/Downloads/test.z80.bin, 512 blocks: Give your local XMODEM receive command now.                                                
Xmodem sectors/kbytes sent:   0/ 0kRetry 0: NAK on sector
Retry 0: NAK on sector
Retry 0: NAK on sector
Retry 0: NAK on sector
Retry 0: NAK on sector
Retry 0: NAK on sector
Retry 0: NAK on sector
Retry 0: NAK on sector
Retry 0: NAK on sector
Bytes Sent:  65536   BPS:2650                    

Transfer complete

TomNisbet, 2022-12-17:
If the checksum fails then the transfer will stop.  If all of the bytes were sent then the code was probably happy with the transfer.  Have you verified that your build can write to your chip?  Try the Zap command to make sure you can write to the chip.  Z 0 followed by D 0 should show a test pattern in the first 32 bytes.

There are some debug commands that may help if there is a problem with the XModem transfer.

- After the command finishes and you are back to a prompt, use the forward slash '/' key to reprint the last status message. Sometimes the output gets eaten by the XModem code, so this lets you display it again.
- There is an Info command 'I' that will print some debug information.
If you post the output of those two commands, I may be able to spot something.

srayner, 2022-12-20:
Hi Tom, thanks for your reply.

I can poke and zap fine. It's just file transfers that I'm having issues with. So I'm happy the hardware is working.

I have to be quite fast typing in the transfer command otherwise it times out. Here is a reasonably successful file transfer:

>w
Send the image file using XMODEM CRC
CSending /Users/steve/test.bin, 512 blocks: Give your local XMODEM receive command now.
Xmodem sectors/kbytes sent:   0/ 0kRetry 0: NAK on sector
Retry 0: NAK on sector
Retry 0: NAK on sector
Retry 0: NAK on sector
Retry 0: NAK on sector
Bytes Sent:  65536   BPS:2655

Transfer complete
/
Status of last command:

INFO: Success writing to EEPROM device.  NumBytes=65536

>I
debugBlockWrites:  1024
debugLastAddress:  0
debugLastExpected: 0
debugLastReadback: 0
debugRxDuplicates: 0
debugExtraChars:   98
debugRxStarts:     6
debugRxSyncErrors: 1

but it just seems to result in a chip full of zeros.

srayner, 2022-12-20:
I've now switched to minicom as you seem to refer to that in your documentation. I have commented out the XMODEM_CRC_PROTOCOL

I have turned off hardware flow control in minicom.

I can connect and issue commands to the TommyPROM ok.

If I press w and enter
then press Esc-Z, S (to send file), select xmodem and proess enter, space (to select file), then enter to send, I just get three beeps and nothing seems to happen.

Is there some configuration I need for minicom?

TomNisbet, 2022-12-21:
I don't think the problem has to do with the communication protocol.  The transfer would halt if the XModem transfer detected a problem or if the PromDevice28C::burnBlock code failed.  Your example above shows that that the transfer completed after sending 64K bytes.  The block size on the 28C256 chips is 64 bytes and the debugBlockWrites count is 1024, so that means that the code tried to write 64K to the chip and thinks it was successful.

I hate to ask this, but is it possible that your file is all zeroes?  Was the chip all FFs before the transfer?  It would be good to know if that data in the chip changed.

If your file is correct, then it feels like the burn code is failing quietly.  Maybe make use of one of the debug variables to verify your data.  For example, in burnBlock, add something like
`debugRxDuplicates = data[0];`
and send a file with less than 128 bytes.  The debug info would then show the first byte of your file.

If the file data is making it as far as burnBlock, then try a check at the bottom, like
`if (readByte(address) != data[0] return false;`
That will verify the first byte in the block after writing the entire block.

srayner, 2022-12-21:
Well this is a bit embarrassing. I think I've realised what the problem is. It seems I'm trying to write a 64K file to a 32K Eprom. I tried smaller files and they work fine. I guess the addresses are wrapping back around to the beginning again. The first 32K probably writes out fine, but then gets overwritten by the second 32K of data.

If it helps anyone else that might be using ASM80.com to generate bin files, specify:

   .binto 32768

at the top of the source code.

I have noticed another issue though. I can't use the dump (d) command on any addresses above 00FF. I've been using the EEPROM for a while and I've not noticed a problem, but I've only ever used a small program in the first few bytes. So I suppose I could yet still have a hardware issue.

TomNisbet, 2022-12-21:
64K - I probably should have noticed that!  In my defense, I'm working with SST39FGS040s right now, so that didn't seem so big.  You are correct that the EEPROM would write twice and end up with the last 32K of data.

What happens when you dump the higher addresses?  Are you just seeing the same 256 bytes of data everywhere? Maybe the higher shift register isn't connected correctly.  You can try the  verify sketch in the [Troubleshooting section](https://tomnisbet.github.io/TommyPROM/troubleshooting/) and use the A command to set different addresses and verify the output pins with a multimeter or an LED and resistor.

srayner, 2022-12-21:
The good news is it is correctly writing the full 32K of data, even though I can't see it with the dump command. I wrote a small Z80 program to display the contents of the memory and it all looks good.

When I try to dump using the d command with any address over FF I just get blanks back. It doesn't display the address or any numbers at all. I'm not near the programmer right now. I'll try to get a screenshot of the output tomorrow.

Closed 2024-05-29.

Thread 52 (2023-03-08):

please add support for AT29C020 device (Atmel TSOP32 Flash)

invictus737, 2023-03-08:
Kindly please extend the code to cover Atmel 29C020 devices

Thx!
Chris

invictus737, 2023-03-09:
Hi,

are you sure? as Atmel AT29C020 is a 256bytes/sector device.

Regards,
Chris

invictus737, 2023-03-09:
datasheet https://www.digchip.com/datasheets/download_datasheet.php?id=164019&part-number=AT29C020

TomNisbet, 2023-03-10:
You are correct. The Winbond 29C020 has a 128 byte sector but the Atmel is 256. I thought only the 040s used the larger sector size.

To support that, you will need to buffer up two packets of data to do a single write operation. You may need to strip some code out to free enough RAM.

prlaba, 2023-03-10:
Tom, does the Nano have enough room to support a 256-byte buffer?

Also why would you need two buffers?  Seems to me only one is needed.

To write a _full_ sector you would load the buffer with the 256 bytes to be written, then write them, one at a time, each write within 150 msecs of the previous, then wait while the chip writes out the sector.

To write a _partial_ sector, you would read all 256 bytes of the sector into the buffer, modify the bytes you want in the buffer (leaving the other bytes in the buffer unchanged), then write the individual bytes in buffer to the sector, per above.

TomNisbet, 2023-03-10:
The nano has 2K of RAM, but I don't remember how much is free in the current build of TommyPROM.  Unfortunately, I don't have access to any nanos at the moment, so I can't look at it.  I suspect you could strip out a few features if more space is needed for the larger buffer.

Adding support for the 256 buffer could be fairly simple, depending on how many edge cases you want to support.  The XModem protocol uses a fixed 128 byte buffer, so TommyPROM will receive the data for the EEPROM in 128 byte chunks.  If you just want to support burning a whole chip and assume that the received data will be on sector boundaries, then the code extension is fairly simple:
- Extend the XModem receive buffer to 256 bytes and keep track of whether the current packet is writing to the first or second part of the buffer
- When the second part of the buffer is written, burn the entire buffer to the chip
- When the file transfer is complete, check to see if there is a partial buffer that needs to be written

Things get a lot more complicated if you want to support arbitrary writes to the chip.  For example, if you try to write 1024 bytes starting at address 5 instead of at 0, then you need to read the existing data to a buffer and merge the newly received data with the existing chip contents for the first and last sectors.  That's probably an odd enough case that it isn't worth doing.  There's probably not enough RAM to support it either, because you would need 128 bytes for a receive buffer plus an additional 256 bytes for the read/write buffer.

prlaba, 2023-03-11:
Thanks Tom, that all makes sense.

I agree, for programming the chip it's reasonable to assume that the start address is on a sector boundary.  But if the size of the file being downloaded is not be a multiple of the sector size, the last sector to be written will be partial.

I don't know all the details of the XModem protocol.  Is the 128-byte size fixed?  Could you increase it to 256 bytes to match the flash's 256-byte sector size?  If not you'd need to toggle the 256-byte buffer's load address between 0x00 and 0x8F as you input each 128 bytes of XModem data.

I'm not sure what XModem does if it receives less than 128 bytes.  Zero the remaining bytes?  Either way, you could end up with a multiple of 256 bytes of XModem data (no partial last sector) or multiple of 128 bytes (partial last sector).  In the case of a partial last sector you could zero-fill the last 128 bytes of the sector.

But if you want other TommyPROM features, like Fill, to work correctly with flash, it would need to be able to write _any_ number of bytes (up to the sector size) to a sector, starting at _any_ offset within the sector.  To do that it would need to first read the sector into the 256-byte buffer, modify the bytes to be written, then write the buffer to the sector.

TomNisbet, 2023-03-15:
The 128 byte buffer size is fixed, so you would need to manage storing two packets worth of data into the write buffer and then burning it to the chip when the buffer fills.

I don't believe that XModem guarantees the contents of the buffer end if the data is not a multiple of 128 bytes.  This isn't usually a problem and you can always pad your file if it is.

Closed 2024-05-29.

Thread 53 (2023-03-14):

27C256

ElectroBoy404NotFound, 2023-03-14:
Hello,
How to use the code for 27C256?

TomNisbet, 2023-03-14:
The 27C256 chips vary a bit, depending on the manufacturer, but the existing code should work for you.  Make these two changes to the default software:

- In Configure.h, comment out the #define for PROM_IS_28C and uncomment PROM_IS_27
- Near the top of TommyPROM.ino, uncomment the PromDevice27 declaration for the 27C256 and make sure all of the other declarations in that section are commented out.

On the hardware side, you will need to apply a programming voltage from an external supply to Vpp to write the chip.  If you are just reading the chip, then you can tie Vpp to the +5V.  Check the data sheet for your chip to verify the programming voltage.  I have seen some that want 12.75V and others that want 13V.  The 12.75 chips are +/- .25 volts, so 13V is probably good in either case, but don't exceed that.

Please let me know the full number on your chip, i.e TMS27C256-15, so I can add it to the list of supported chips.

ElectroBoy404NotFound, 2023-03-30:
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

Hello,
My chip number is "M27C256B-12F15880X1140L"

TomNisbet, 2023-03-30:
Were you able to program it successfully?
Your chip is an ST Micro EPROM.  It needs 6.25 volts on Vcc and 12.75 volts on Vpp when programming.  See page 8 of the datasheet here: https://media.digikey.com/pdf/Data%20Sheets/ST%20Microelectronics%20PDFS/M27C256B.pdf

ElectroBoy404NotFound, 2023-03-31:
> Were you able to program it successfully? Your chip is an ST Micro EPROM. It needs 6.25 volts on Vcc and 12.75 volts on Vpp when programming. See page 8 of the datasheet here: https://media.digikey.com/pdf/Data%20Sheets/ST%20Microelectronics%20PDFS/M27C256B.pdf

I'm going to test it today.

ElectroBoy404NotFound, 2023-03-31:
@TomNisbet
**UPDATE:** I tried 2 EPROM models. I was able to prpgram the M27C256B-12F1**B880C** chip fine but not the M27C256B-12F1**5880X** chip. I think the problem is that my 12v adapter is actually giving around **11.5V** instead of **12.75V** needed for programming and my tab (Samsung A8 that I'm using to program it) is giving around **4.95V** instead of **6.25V** needed. Is there any way to solve these problems (without replacing the power supply)?

TomNisbet, 2023-04-01:
The minimum voltages for that part are 6V and 12.5V, so you might get lucky with some chips, but your results won't be reliable without a different power supply.  The good new is that you have verified that your programmer is otherwise working.

Also, it you get an external supply for the 6.25V to your EPROM's Vcc, make sure that it is not connected to the 5V from the Arduino or the 5V going to the shift registers.

ElectroBoy404NotFound, 2023-04-03:
> The minimum voltages for that part are 6V and 12.5V, so you might get lucky with some chips, but your results won't be reliable without a different power supply. The good new is that you have verified that your programmer is otherwise working.
>
> Also, it you get an external supply for the 6.25V to your EPROM's Vcc, make sure that it is not connected to the 5V from the Arduino or the 5V going to the shift registers.

I see. I will try using a boost converter module for 6.25V and see if it works. Also, sorry for the late reply, I was busy.

ElectroBoy404NotFound, 2023-05-07:
I tried it, it did;nt work

ElectroBoy404NotFound, 2023-05-07:
I tried 13v and 7v, but it just would'nt program.

jscrane, 2024-05-03:
I have a couple of similar chips which I can't program either. They are labelled ```M27256F1```.

I am using a TommyPROM32 board with Vpp at 12.5v and Vcc at 6.5v.

Referring to [this datasheet](https://www.silicon-ark.co.uk/datasheets/m27256-datasheet-st.pdf), shouldn't the ```pulseWidth``` constructor parameter be ```1000L``` maybe? (In any case, I tried both 100L and 1000L and neither worked.)

> The duration of the initial E pulse(s) is 1ms, which will then be followed by a longer overprogram pulse of length 3ms by n
> ...

Happy to help debugging this problem...

TomNisbet, 2024-05-04:
I have programmed a M27C256, but yours are the older M27256 with a different programming algorithm.  It looks like your data sheet wants 6V on Vcc  instead of 6.5.  Hopefully that didn't cause any issues.

The program pulse width should be 1000L and the overwrite value should be 3.  I checked in new code that added a definition for this chip in TommyPROM.ino.

The existing code was also incorrect.  The overwrite pulse should be programPulse * multiplier * numberOfWriteAttempts.  I was not including the multiplier for the number of attempts.  Also the code was not doing the overwrite pulse for chips that do not have a dedicated WE pin.

Please let me know if the new code works for you.  I'll add the M27256 to the list of verified chips if it works.

jscrane, 2024-05-04:
I can confirm that the latest code works with my M27256. Thanks a lot!

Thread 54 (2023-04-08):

Hardware Verify Not Working?

OrlandoBlyat, 2023-04-08:
Hi,
I've assembled the TommyPROM on a breadboard with the 74HCT595 registers. But writing/reading aren't functioning properly, my wiring probably is at fault. I uploaded the HardwareVerify sketch, but in my serial terminal (MobaXTerm) I don't have a CLI (I set the baud rate to 115200). I recieve two '#' and that is it. The standard TommyPROM sketch works as inteded. Screenshots present.
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
/Terminal with the Hardware Verify Sketch/

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
/Terminal with the TommyPROM sketch/

TomNisbet, 2023-04-10:
The verify sketch doesn't print any header to identify itself, just the # character for the prompt.  Did you try entering any commends?  It uses the same terminal ode as TommyPROM, so if you were able to use one, then the other should work as well.

What kind of chip are you programming?  Can you try the Z command in TommyPROM and post the results?  Do Z0 and then D0.

OrlandoBlyat, 2023-04-17:
Hello,
sorry for the late response, I guess GitHub didn't send me an email about the response.
As I said, the terminal is exhibiting kind of strange behavior:
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
----
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
----
I can input the command, pressing enter returns the cursor to line start. None of the commands return anything.
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
----
I've also tried using TeraTermYT but it doesn't change.

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

SvenPaterson, 2023-10-20:
I too seem to have had this exact same issue using teraterm. Worked just fine in the arduino native serial monitor once I finally tried using it!

Closed 2024-05-29.

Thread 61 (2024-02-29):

Cannot burn image

ian-rose, 2024-02-29:
I am trying to burn an image to a 28C256, but it is not working.

MacOS Sonoma 14.3
minicom version 2.9
TommyPROM 3.3 - 28C series EEPROM

The commands I am running:

1. `minicom`
2. `w` (I have also tried `w0`
3. `esc-z`
4. `s`
5. `down`, `down` (select xmodem)
6. `enter`
7. `left`, `left`, `left`, `left`, `left` (select `Goto`)
8. `enter`
9. (type in directory)
10. `enter`
11. `down`, `down`... (highlight file)
12. `space` (select file)
13. `enter`
14. wait (window shows, but no progress indicator. No success or error messages)
15. `d`
16. `enter`

The dumped data is not correct

Based on my ability to disable write protection I assume things are wired correctly. I can think of two possible issues:

1. My image is not correct
   - My image is a binary file with no header information. When viewed with `xxd` the contents are correctly displayed.
2. I am not executing the correct commands
   - I have yet to find any documentation as to how to actually burn an image using TommyPROM, so this is very likely.

TomNisbet, 2024-03-01:
There are a few things to try:

- Have you verified that the basic programming functionality works?  Use the Zap command, z0, to verify that a test pattern can be burned into the chip.  If that fails on the first byte, you may need to use the Unlock command as well.
- A binary image file is the correct format to use, so no problem there.
- Use the w0 command to specify that the image should start at the first byte of the chip.
- If the Modem transfer fails, the error message is sometimes hidden by the transfer.  After you get back to the command prompt, use the '/' command to show the last error message.  That may give you an indication about the failure.
- Also try the Info command, and post the results of that here.  It will show detailed information about the last transfer.

When you say that the dumped data is not correct, are you seeing that the data in the chip changed after the write but it isn't the data you expect, or that no new data was written at all?

ian-rose, 2024-03-11:
I was able to verify writing via successfully unlocking the chip. I did not try using zap.

I found a workaround to this issue by installing lrzsz and configuring minicom to run the following command when xmodem is selected: `lsx -b -X`. I'm assuming this is very kludge-y (xmodem should work without overwriting the command it executes), but it got the job done.

ABelliqueux, 2024-06-14:
To add to what @ian-rose said, I also had to install `lrzsz` on Manjaro Linux but I had to use `lrzsz-sx` instead of `lsx` in minicom.

Here are the steps to change the default xmodem command to `lrzsz-sx -b -X` :

In minicom:

1. Ctrl-A, Ctrl-Z
2. Hit O key
3. Enter "File Transfer protocols"
4. Edit line with "xmodem", making sure it's the send command ( should say "sx" and not "rx") or hit C key.
5. Hit Return once and edit the existing command (`lrzsz-sx -vv` in my case) to `lrzsz-sx -b -X`
6. Hit Escape a few times until you're back in the configuration menu.
7. Choose "Save setup as dfl"

Maybe this could be mentionned in the doc ? I can submit a PR if you want me to @TomNisbet.

Closed 2024-03-11.

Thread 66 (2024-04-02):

CSI CAT28C16AP working?

jscrane, 2024-04-02:
Hi,
Was wondering if anyone has tried this chip? I have added a line to `TommyPROM.ino`

```
PromDevice28C  prom(2 * 1024L, 0, 10, true);  // 28C16 with no page writes
```

However I'm not having any luck writing to it:

```
>u
Writing the unlock code to disable Software Write Protect mode: OK
>p 0 00
INFO: Poke successful
>d 0 0f
00000: 00 00 00 00  00 00 00 00  00 00 00 00  00 00 00 00  ........ ........
>p 0 ff
ERROR: Write failed
>d 0 0f
00000: 1c 1c 1c 1c  1c 1c 1c 1c  1c 1c 1c 1c  1c 1c 1c 1c  ........ ........
```

I'm talking to it using minicom on Linux.

(I have assembled TommyPROM on a PCB btw.)

Any help appreciated!
Steve

TomNisbet, 2024-04-02:
Hi Steve,

I have not used the CAT28C16, but have programmed the CAT28C256.  There is no reason the code shouldn't work with that chip.

The 28C16 does not support Software Data Protection, so the unlock command isn't doing anything.

It's odd that all of the bytes change between your two read commands when you only write one byte.  That makes me suspect that the addressing circuit may have a problem and is possibly just reading a single byte over and over.  It could also be that it isn't reading data back from the chip at all and those values are just random signals from the bus.

You could try the Hardware Verify Sketch described on the [Troubleshooting page](https://tomnisbet.github.io/TommyPROM/docs/troubleshooting) to see if the hardware is behaving as it should.

If you have a second chip, especially a different type, that would be helpful to test as well, to isolate if there is a hardware problem or if you just have a faulty chip.

Your setup for the chip looks good.  Byte at a time with no block writes is the way to go.

Did you design your own PCB or did you use one of the designs on my site?

jscrane, 2024-04-02:
Hi Tom,
I used your PCB designs. This one is the plain TommyPROM one, I haven't finished the TommyPROM32 yet.

This chip only has 24 pins --- does that board only handle 28 pin devices?

I have done a quick check of the address lines with the Hardware Verify sketch and a multimeter and they seem OK --- for a 28 pin device.

I guess I will have to wait for the rest of the parts to arrive and complete the TommyPROM32 board?

Thanks!
Steve

jscrane, 2024-04-02:
Looking at the pinouts for the 28C16 and the 28C256, I guess I could put the chip with its pin 1 in pin 3 of the ZIF, and connect:
- ZIF pin 28 to pin 26 (Vcc)
- ZIF pin 27 to pin 23 (/WE)

All of the other pins seem to be the same. I will try this tomorrow and report back here.

TomNisbet, 2024-04-02:
The problem you will have there is that you will be shorting the A13 pin from the shift register to Vcc and the A11 pin to WE.  If the A13 pin is low then you have a short circuit.  Similarly, the WE and A11 signals will conflict with each other.  If I ever make a new version of that board, I should add jumpers for those two pins to accommodate both the 24 and 28 pin chips.

The TommyPROM32 board would work very well.  There is already a jumper position to put Vcc on pin 24, so you'd just need to add a single jumper wire for WE and then just install all of the other jumpers in their default position to connect all pins straight across.

jscrane, 2024-04-02:
Yes you are right of course. I will wait for TommyPROM32!

Thanks for your help!

Closed 2024-04-02.

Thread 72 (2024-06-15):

TommyPROM32 : Ok to replace SW1 and SW2 with jumpers ?

ABelliqueux, 2024-06-15:
As switches with the correct size/footprint  are hard to source at a decent price where I am, and only one of the position is used, is it okay to replace them with a jumper like so ?

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

TomNisbet, 2024-06-19:
Yes, that should work just fine.

ABelliqueux, 2024-06-19:
Cool, thanks !

Closed 2024-06-19.

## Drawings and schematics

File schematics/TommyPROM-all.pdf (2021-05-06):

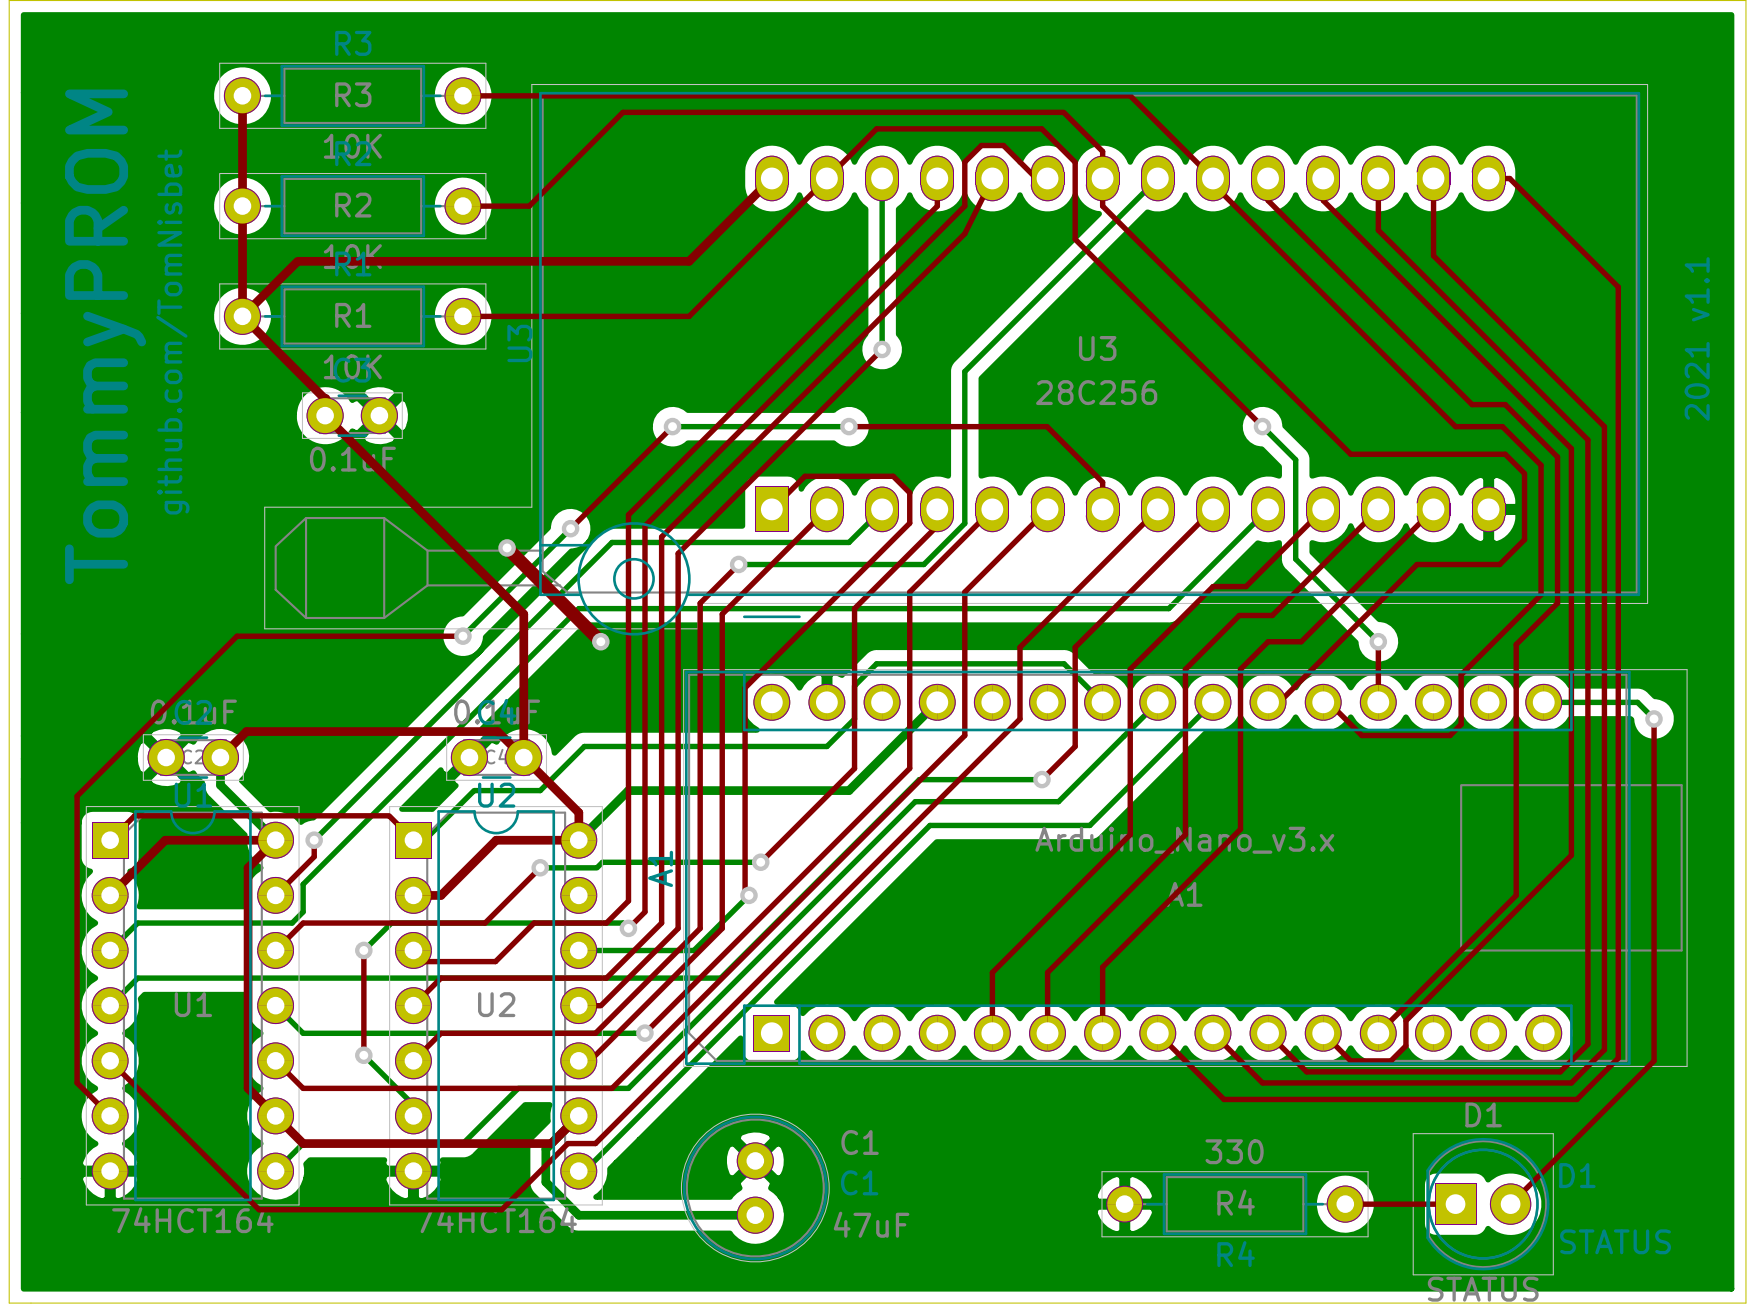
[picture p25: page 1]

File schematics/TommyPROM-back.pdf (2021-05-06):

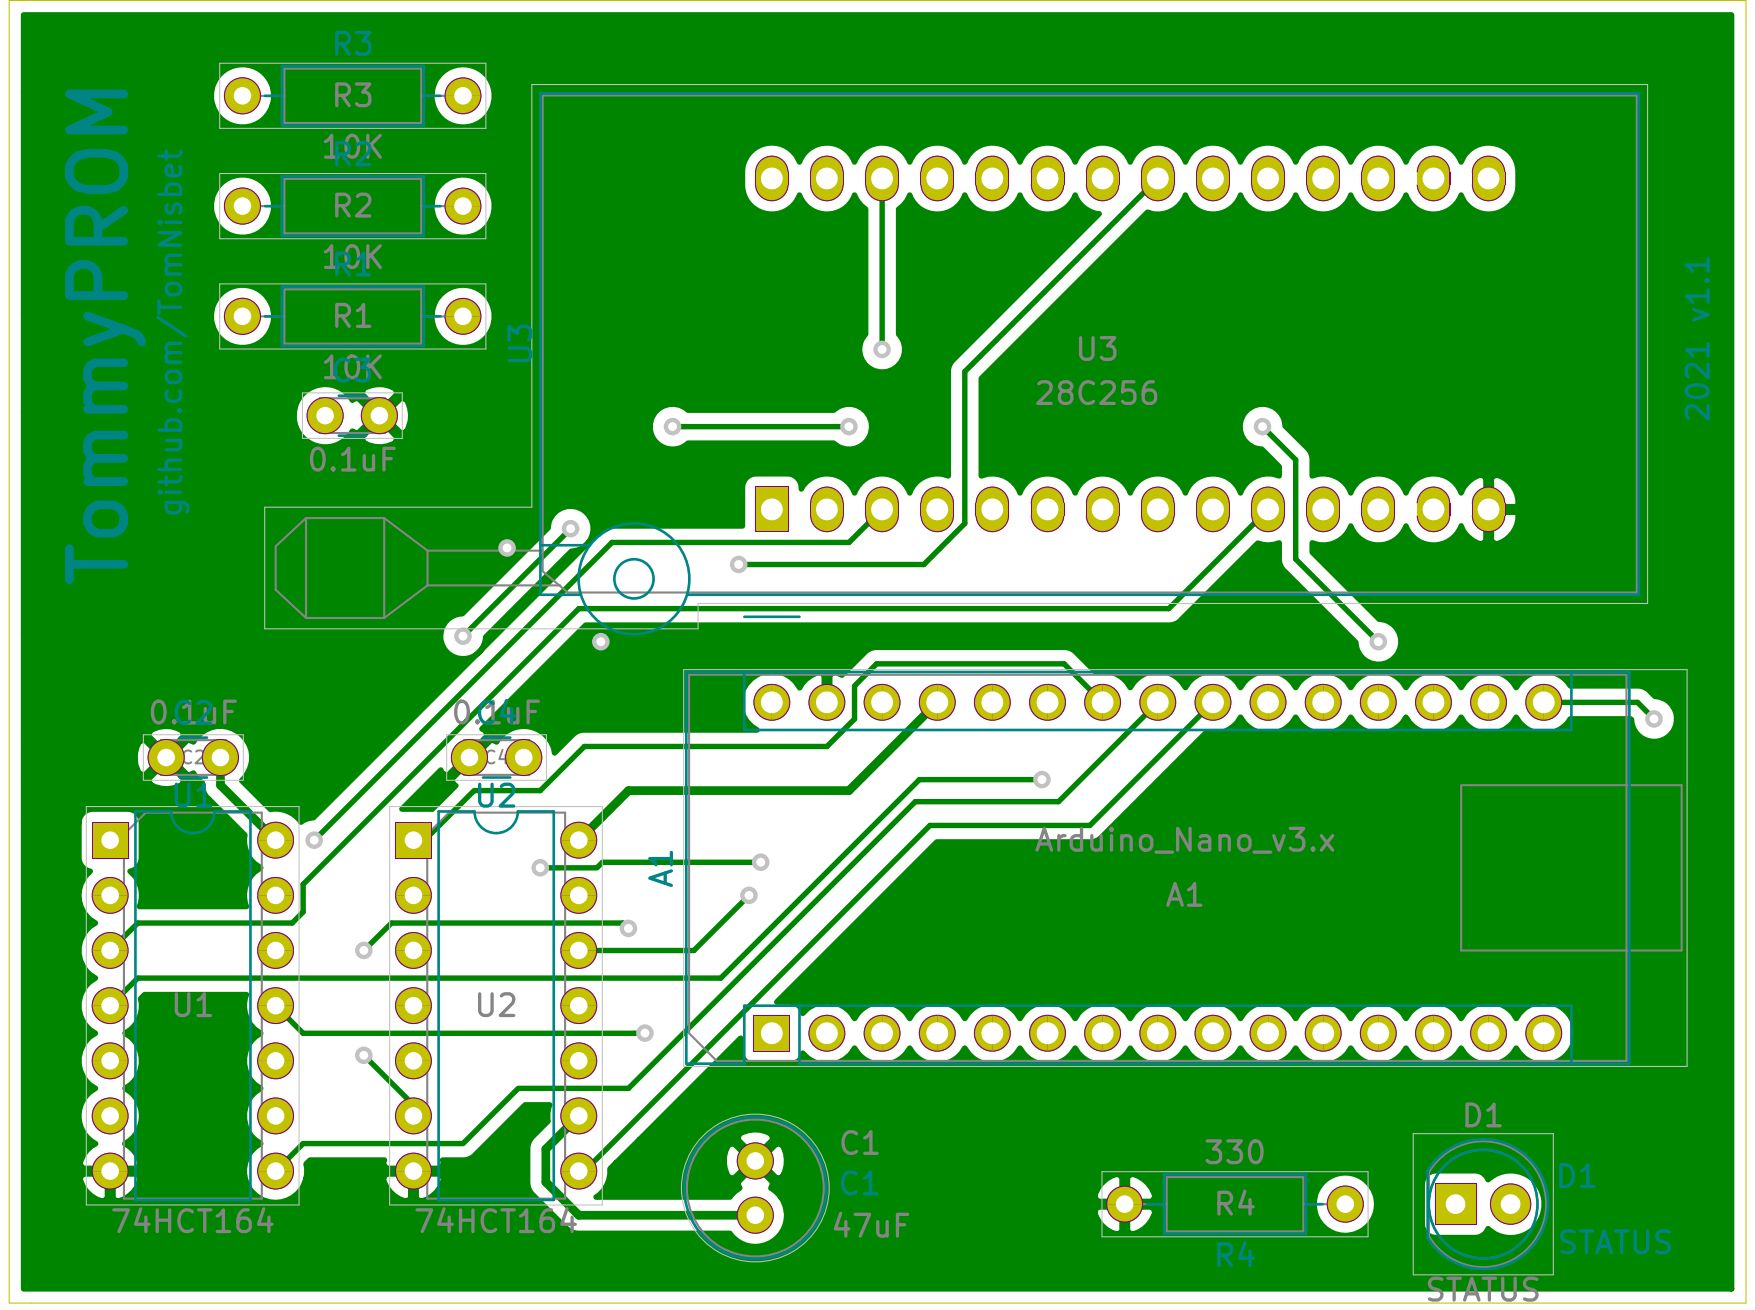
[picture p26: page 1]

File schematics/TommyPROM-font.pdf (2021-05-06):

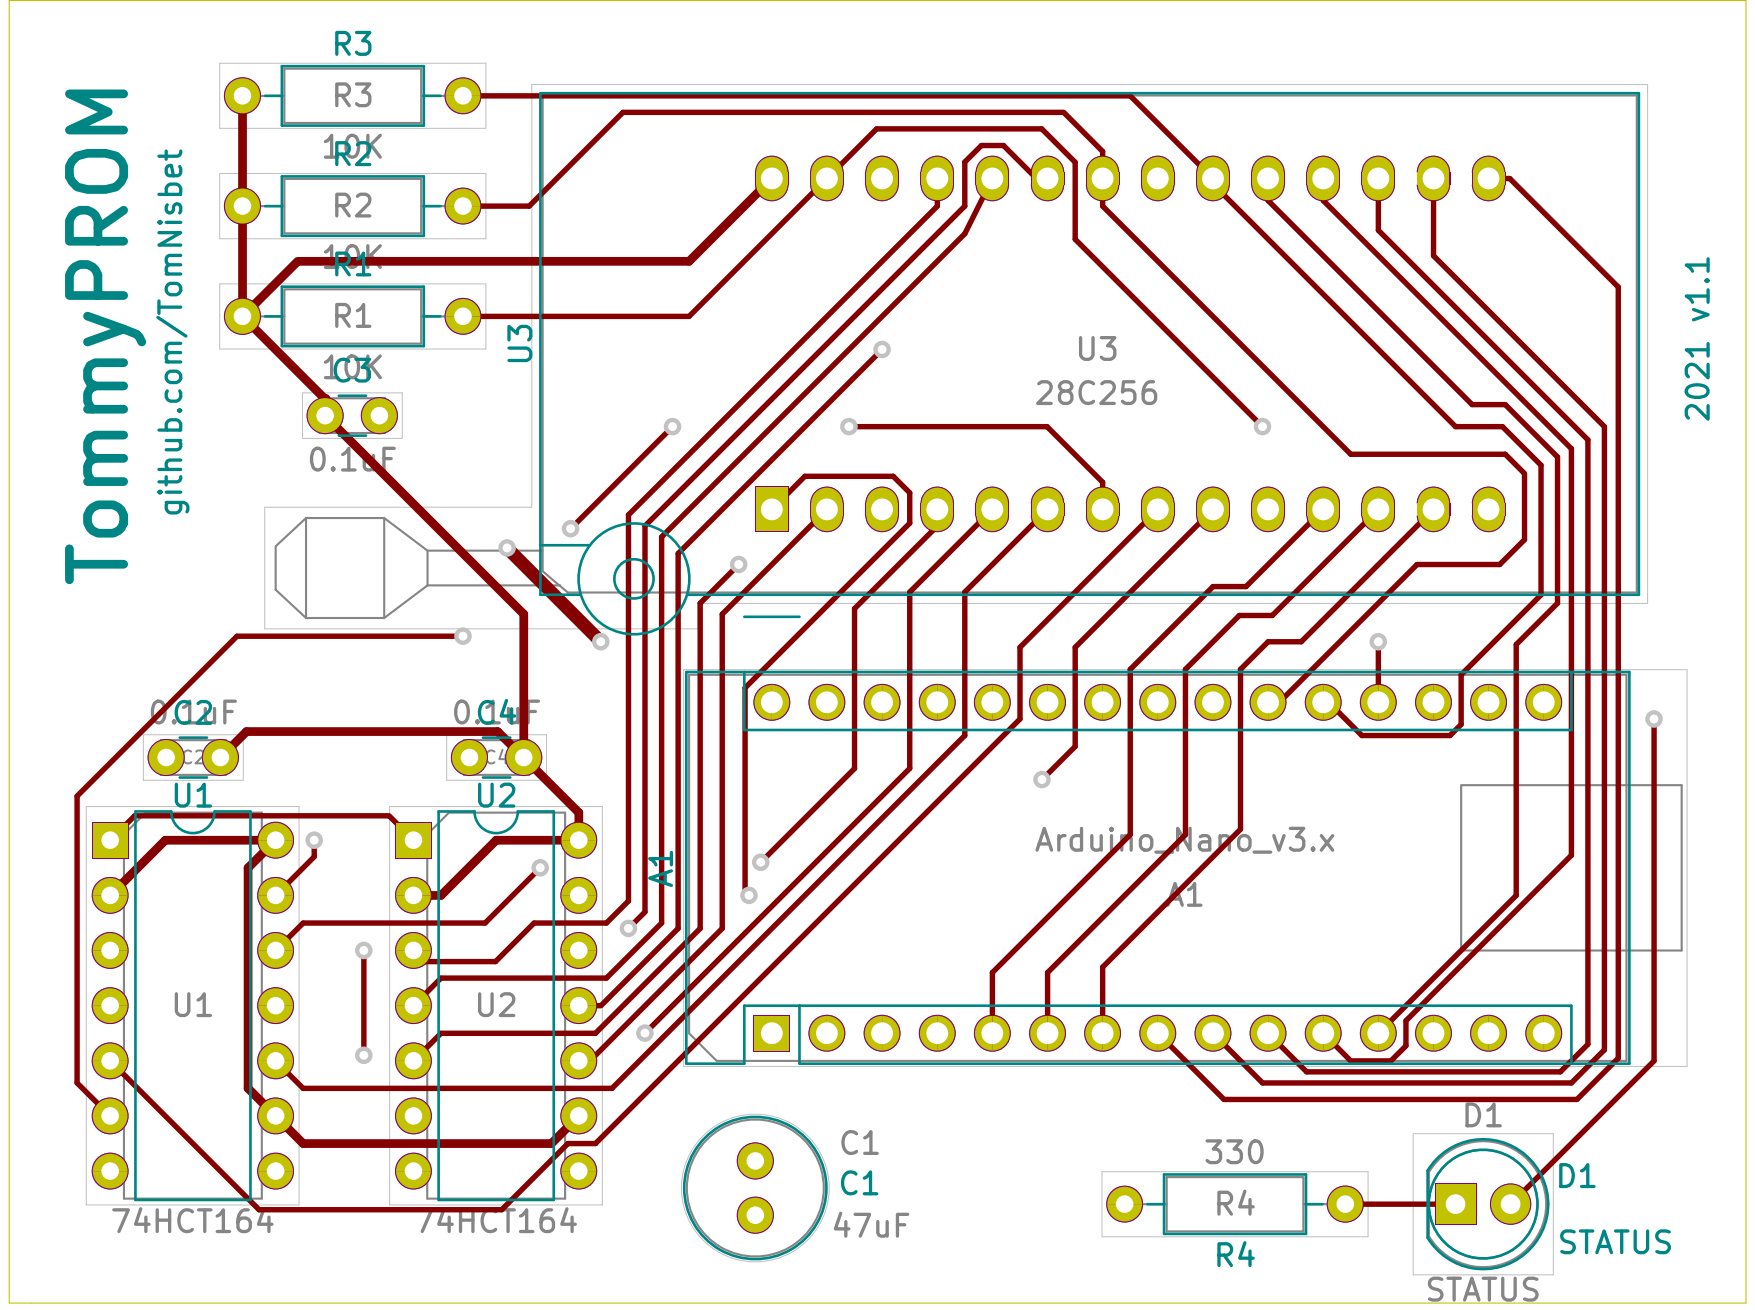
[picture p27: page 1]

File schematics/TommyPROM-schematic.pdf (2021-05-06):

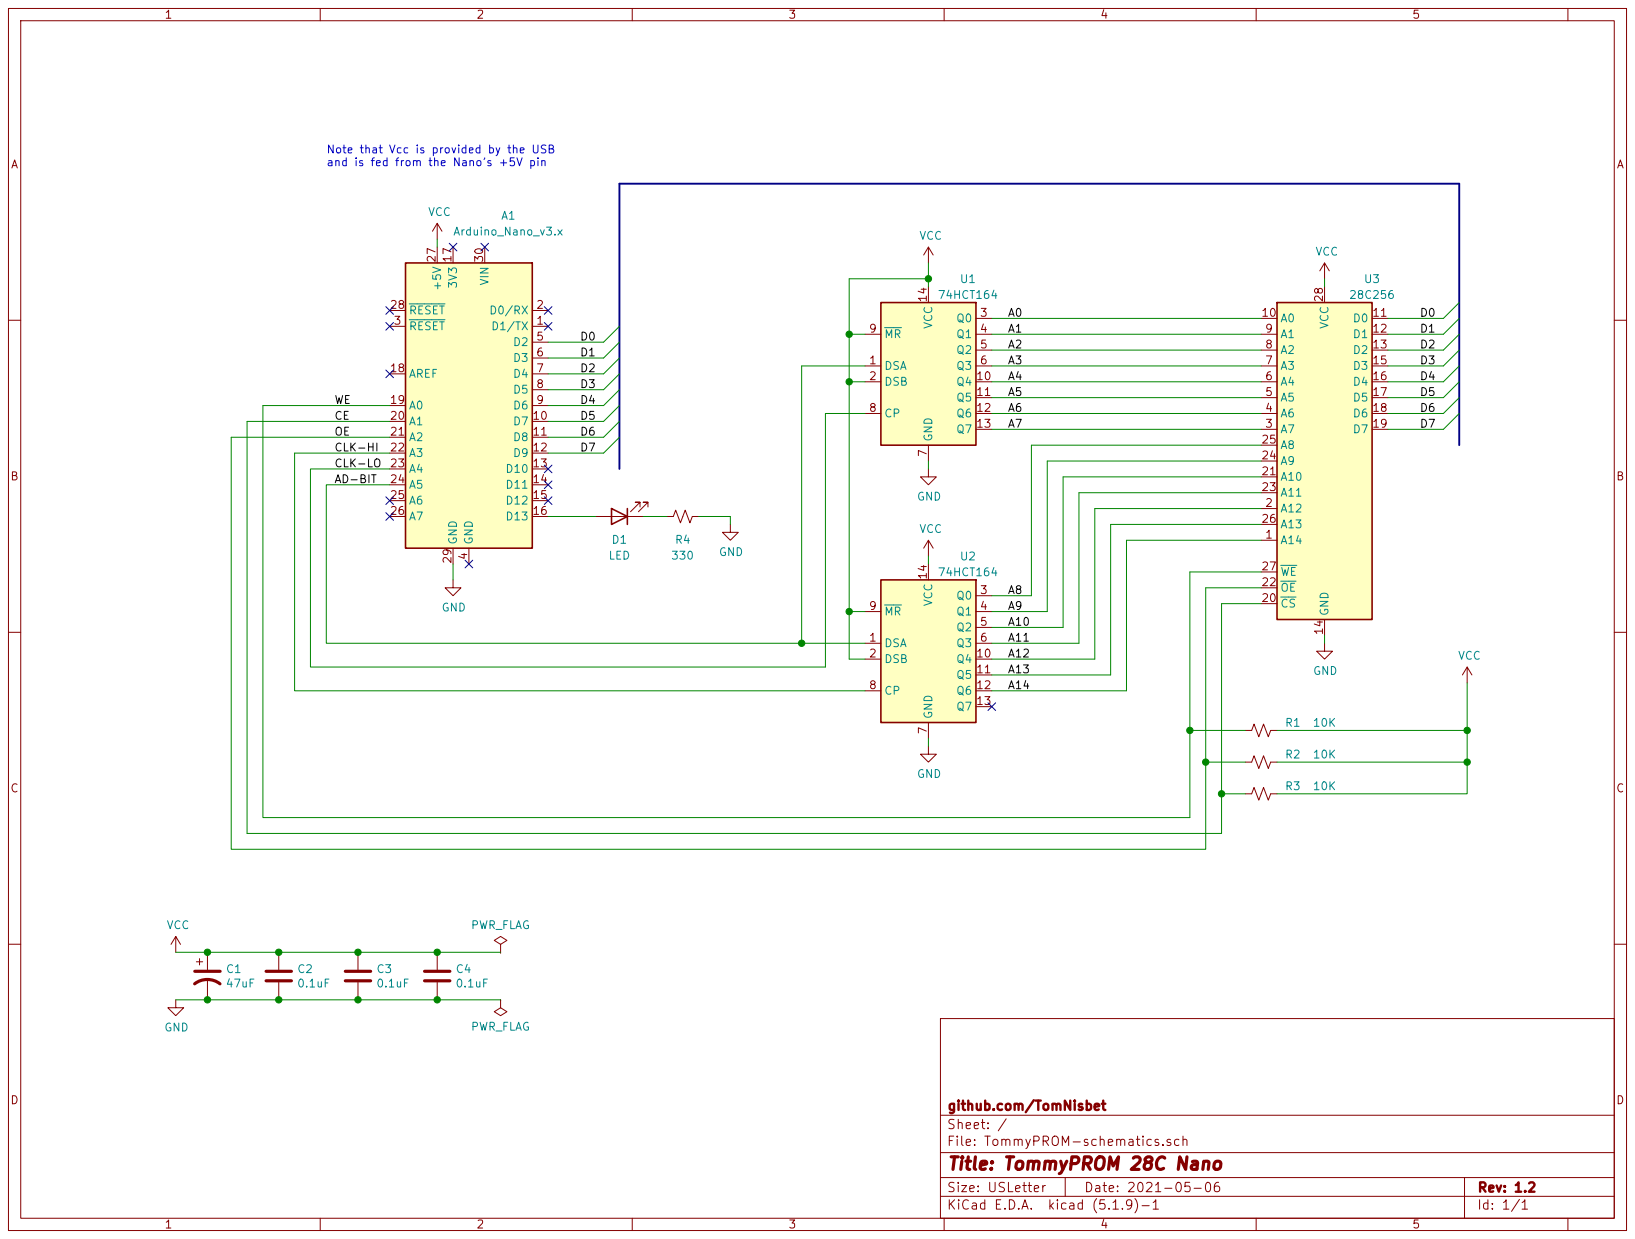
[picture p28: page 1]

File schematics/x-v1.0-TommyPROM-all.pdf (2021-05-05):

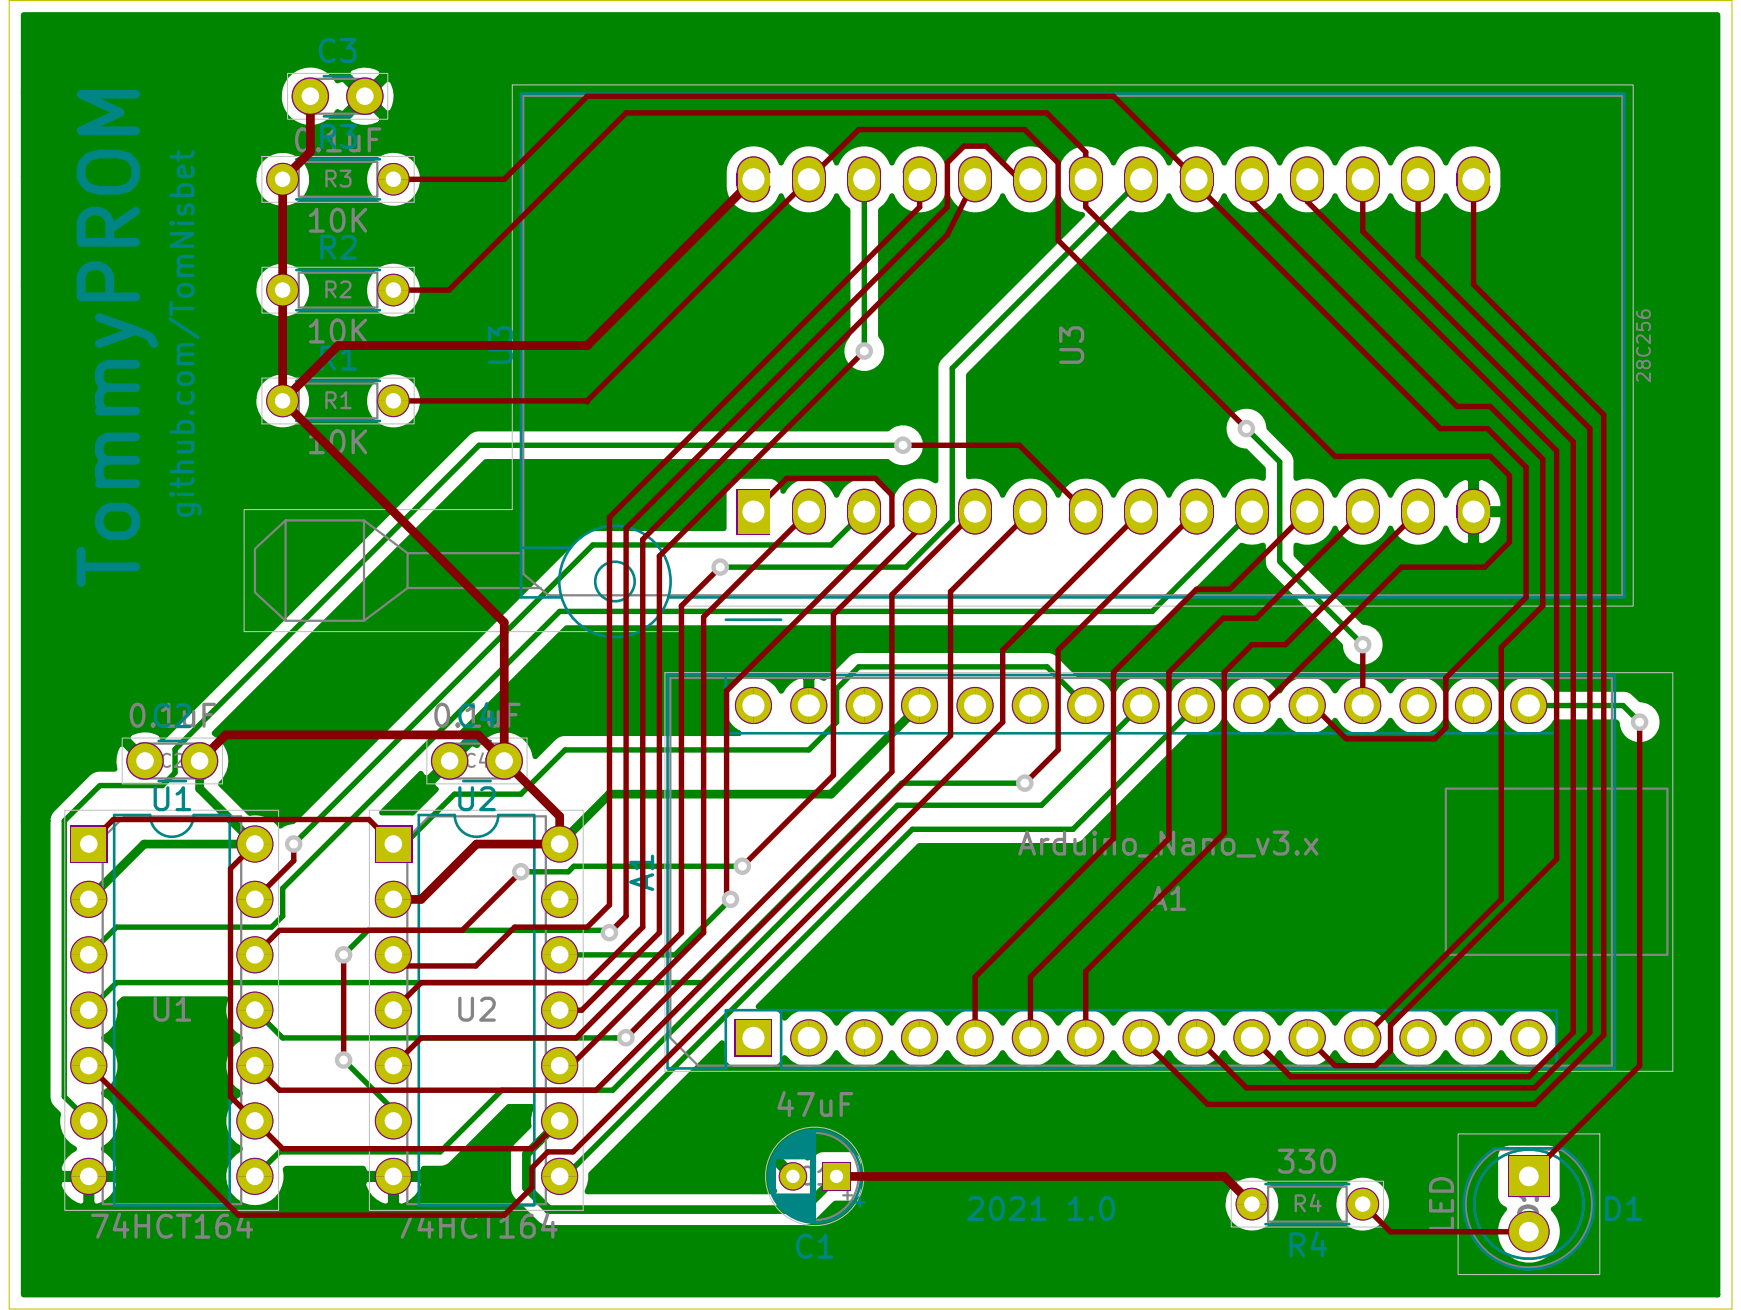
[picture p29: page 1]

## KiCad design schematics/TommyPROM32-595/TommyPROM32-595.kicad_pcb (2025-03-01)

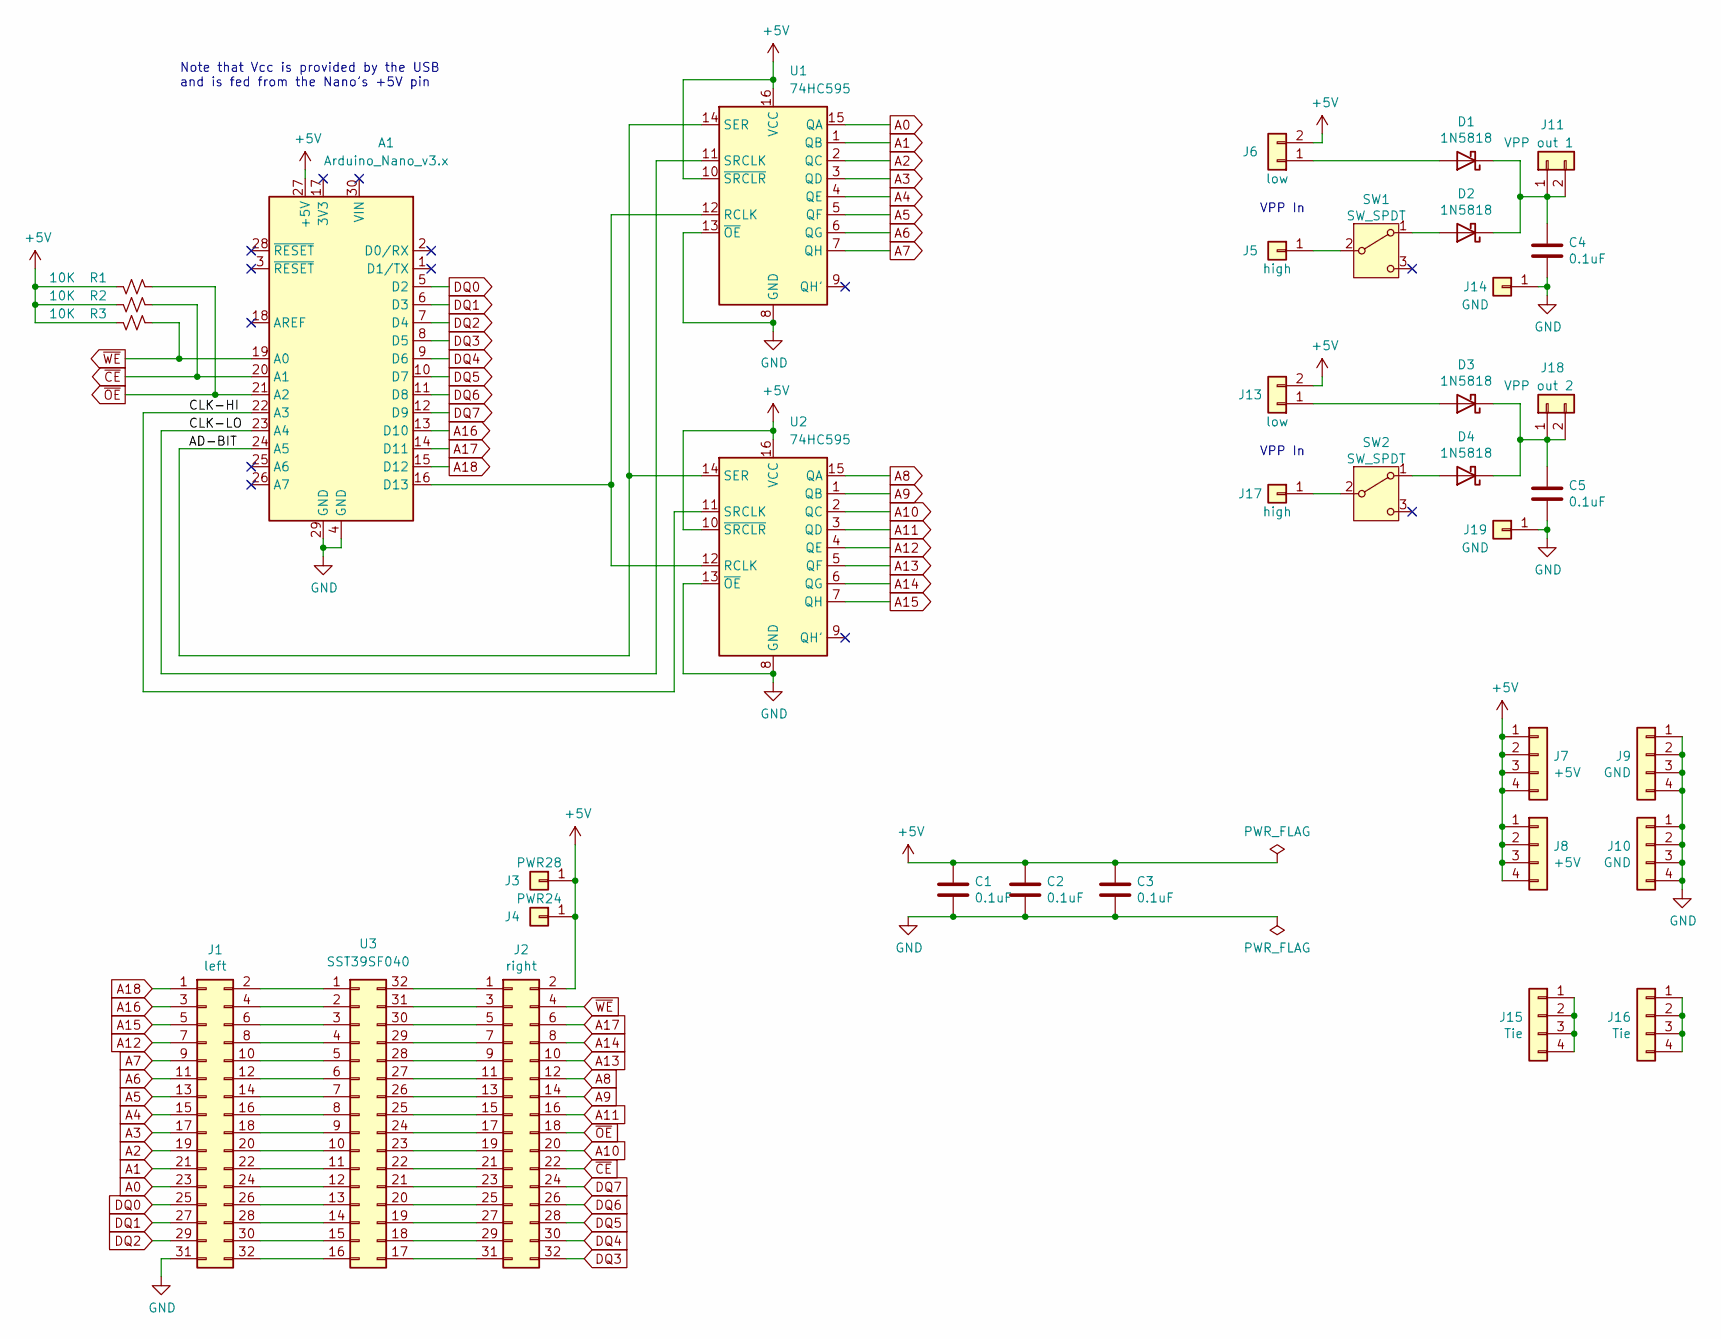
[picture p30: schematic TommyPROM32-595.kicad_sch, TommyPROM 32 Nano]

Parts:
A1: Arduino_Nano_v3.x; Arduino_Nano
C1, C2, C3, C4, C5: 0.1uF; C_Disc_D3.0mm_W1.6mm_P2.50mm
D1, D2, D3, D4: 1N5818; D_DO-41_SOD81_P10.16mm_Horizontal
J1: left; PinHeader_2x16_P2.54mm_Vertical
J2: right; PinHeader_2x16_P2.54mm_Vertical
J3: PWR28; PinHeader_1x01_P2.54mm_Vertical
J4: PWR24; PinHeader_1x01_P2.54mm_Vertical
J5, J17: high; PinHeader_1x01_P2.54mm_Vertical
J6, J13: low; PinHeader_1x02_P2.54mm_Vertical
J7, J8: +5V; PinHeader_1x04_P2.54mm_Vertical
J9, J10: GND; PinHeader_1x04_P2.54mm_Vertical
J11: VPP out 1; PinHeader_1x02_P2.54mm_Vertical
J14, J19: GND; PinHeader_1x01_P2.54mm_Vertical
J15, J16: Tie; PinHeader_1x04_P2.54mm_Vertical
J18: VPP out 2; PinHeader_1x02_P2.54mm_Vertical
R1, R2, R3: 10K; R_Axial_DIN0207_L6.3mm_D2.5mm_P10.16mm_Horizontal
SW1, SW2: SW_SPDT; Switch_Slide_11.6x4mm_EG1218
U1, U2: 74HC595; DIP-16_W7.62mm
U3: SST39SF040; DIP_Socket-32_W11.9_W12.7_W15.24_W17.78_W18.5_3M_232-1285-0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

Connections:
+5V: A1.27 (+5V), C1.1, C2.1, C3.1, J2.2, J3.1, J4.1, J6.2, J7.1, J7.2, J7.3, J7.4, J8.1, J8.2, J8.3, J8.4, J13.2, R1.1, R2.1, R3.1, U1.10 (~SRCLR), U1.16 (VCC), U2.10 (~SRCLR), U2.16 (VCC)
/AD-BIT: A1.24 (A5), U1.14 (SER), U2.14 (SER)
/CLK-HI: A1.22 (A3), U2.11 (SRCLK)
/CLK-LO: A1.23 (A4), U1.11 (SRCLK)
A0: J1.23, U1.15 (QA)
A1: J1.21, U1.1 (QB)
A2: J1.19, U1.2 (QC)
A3: J1.17, U1.3 (QD)
A4: J1.15, U1.4 (QE)
A5: J1.13, U1.5 (QF)
A6: J1.11, U1.6 (QG)
A7: J1.9, U1.7 (QH)
A8: J2.12, U2.15 (QA)
A9: J2.14, U2.1 (QB)
A10: J2.20, U2.2 (QC)
A11: J2.16, U2.3 (QD)
A12: J1.7, U2.4 (QE)
A13: J2.10, U2.5 (QF)
A14: J2.8, U2.6 (QG)
A15: J1.5, U2.7 (QH)
A16: A1.13 (D10), J1.3
A17: A1.14 (D11), J2.6
A18: A1.15 (D12), J1.1
DQ0: A1.5 (D2), J1.25
DQ1: A1.6 (D3), J1.27
DQ2: A1.7 (D4), J1.29
DQ3: A1.8 (D5), J2.32
DQ4: A1.9 (D6), J2.30
DQ5: A1.10 (D7), J2.28
DQ6: A1.11 (D8), J2.26
DQ7: A1.12 (D9), J2.24
GND: A1.4 (GND), A1.29 (GND), C1.2, C2.2, C3.2, C4.2, C5.2, J1.31, J9.1, J9.2, J9.3, J9.4, J10.1, J10.2, J10.3, J10.4, J14.1, J19.1, U1.8 (GND), U1.13 (~OE), U2.8 (GND), U2.13 (~OE)
unnamed: A1.16 (D13), U1.12 (RCLK), U2.12 (RCLK)
unnamed: D1.2 (A), J6.1
unnamed: C4.1, D1.1 (K), D2.1 (K), J11.1, J11.2
unnamed: D2.2 (A), SW1.1 (A)
unnamed: D3.2 (A), J13.1
unnamed: C5.1, D3.1 (K), D4.1 (K), J18.1, J18.2
unnamed: D4.2 (A), SW2.1 (A)
unnamed: J1.2, U3.1
unnamed: J1.4, U3.2
unnamed: J1.6, U3.3
unnamed: J1.8, U3.4
unnamed: J1.10, U3.5
unnamed: J1.12, U3.6
unnamed: J1.14, U3.7
unnamed: J1.16, U3.8
unnamed: J1.18, U3.9
unnamed: J1.20, U3.10
unnamed: J1.22, U3.11
unnamed: J1.24, U3.12
unnamed: J1.26, U3.13
unnamed: J1.28, U3.14
unnamed: J1.30, U3.15
unnamed: J1.32, U3.16
unnamed: J2.1, U3.32
unnamed: J2.3, U3.31
unnamed: J2.5, U3.30
unnamed: J2.7, U3.29
unnamed: J2.9, U3.28
unnamed: J2.11, U3.27
unnamed: J2.13, U3.26
unnamed: J2.15, U3.25
unnamed: J2.17, U3.24
unnamed: J2.19, U3.23
unnamed: J2.21, U3.22
unnamed: J2.23, U3.21
unnamed: J2.25, U3.20
unnamed: J2.27, U3.19
unnamed: J2.29, U3.18
unnamed: J2.31, U3.17
unnamed: J5.1, SW1.2 (B)
unnamed: J15.1, J15.2, J15.3, J15.4
unnamed: J16.1, J16.2, J16.3, J16.4
unnamed: J17.1, SW2.2 (B)
~CE: A1.20 (A1), J2.22, R2.2
~OE: A1.21 (A2), J2.18, R1.2
~WE: A1.19 (A0), J2.4, R3.2

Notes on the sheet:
Note that Vcc is provided by the USB and is fed from the Nano’s +5V pin
VPP In

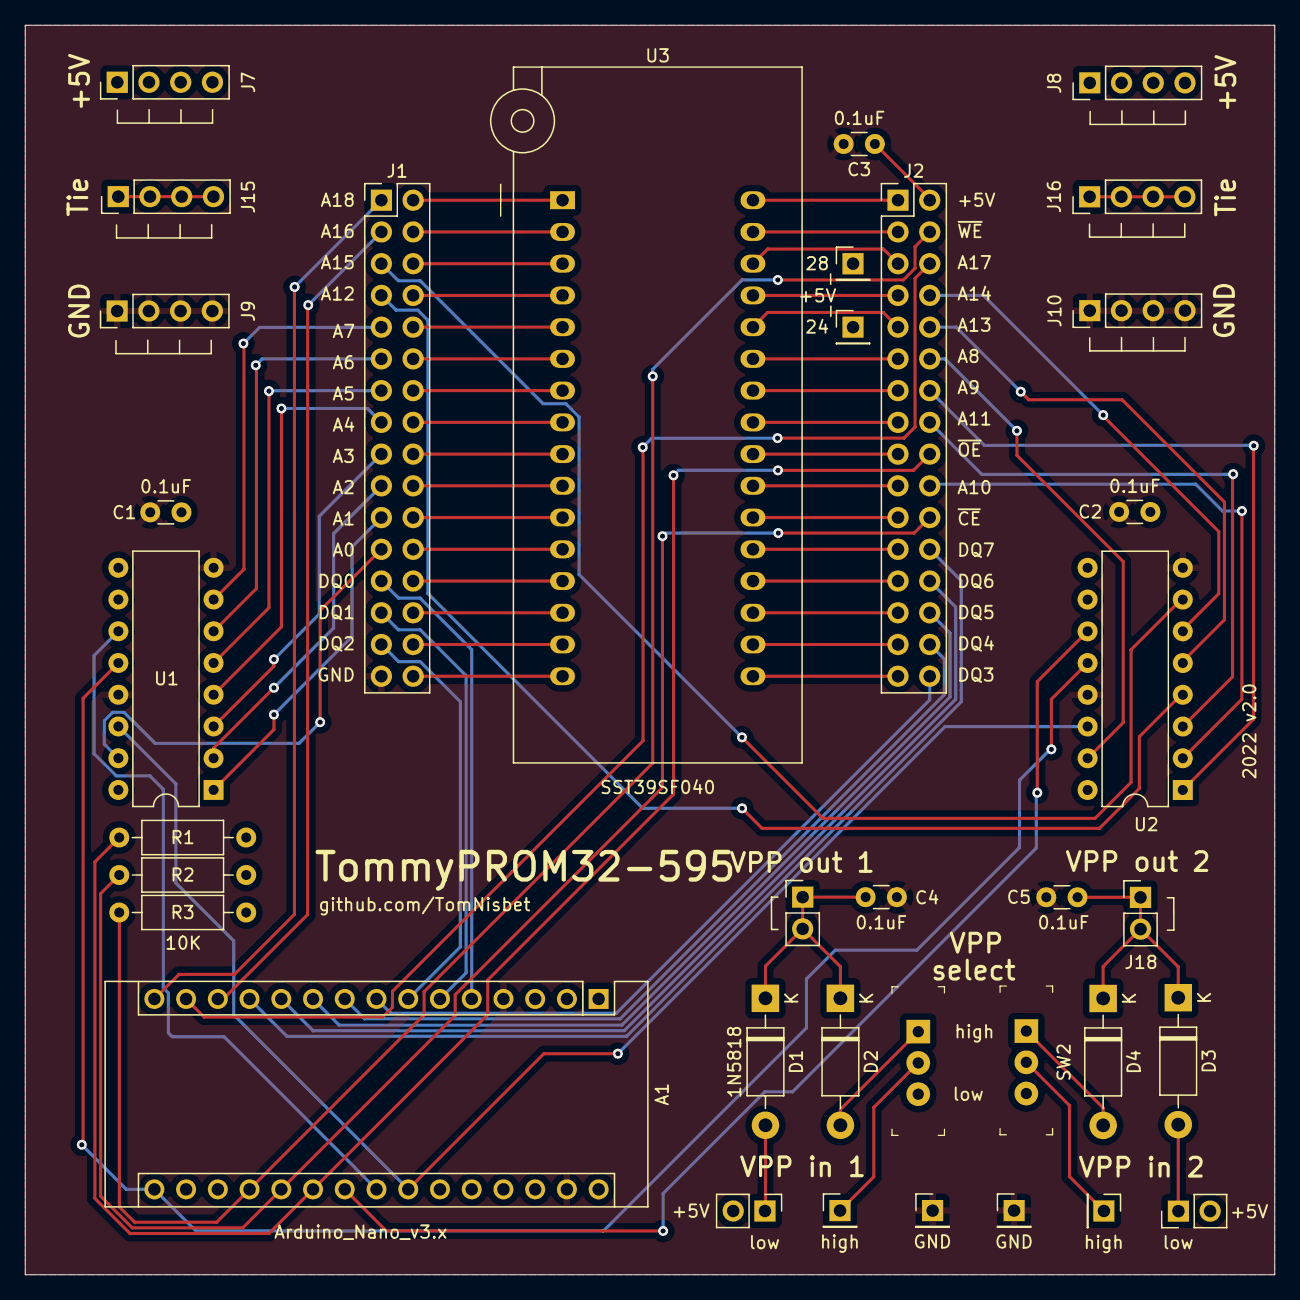
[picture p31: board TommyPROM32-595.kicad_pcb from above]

Board: 2 copper layers, 100.0 x 100.0 mm, 36 parts (0 on the bottom side), 78 nets.

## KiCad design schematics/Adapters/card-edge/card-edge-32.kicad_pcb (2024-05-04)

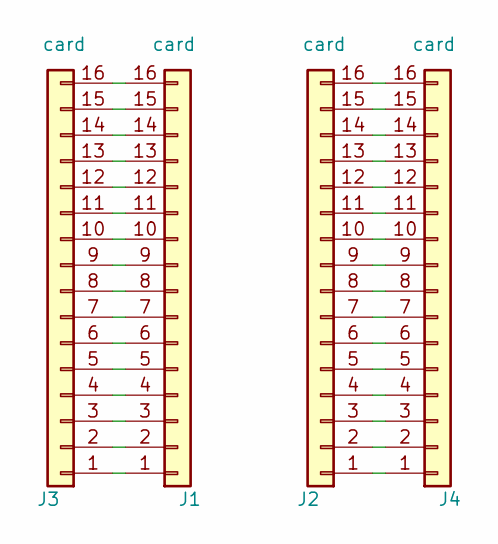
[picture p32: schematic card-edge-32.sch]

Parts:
J1, J2, J3, J4: card; PinHeader_1x16_P2.54mm_Vertical

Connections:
unnamed: J1.1, J3.1
unnamed: J1.2, J3.2
unnamed: J1.3, J3.3
unnamed: J1.4, J3.4
unnamed: J1.5, J3.5
unnamed: J1.6, J3.6
unnamed: J1.7, J3.7
unnamed: J1.8, J3.8
unnamed: J1.9, J3.9
unnamed: J1.10, J3.10
unnamed: J1.11, J3.11
unnamed: J1.12, J3.12
unnamed: J1.13, J3.13
unnamed: J1.14, J3.14
unnamed: J1.15, J3.15
unnamed: J1.16, J3.16
unnamed: J2.1, J4.1
unnamed: J2.2, J4.2
unnamed: J2.3, J4.3
unnamed: J2.4, J4.4
unnamed: J2.5, J4.5
unnamed: J2.6, J4.6
unnamed: J2.7, J4.7
unnamed: J2.8, J4.8
unnamed: J2.9, J4.9
unnamed: J2.10, J4.10
unnamed: J2.11, J4.11
unnamed: J2.12, J4.12
unnamed: J2.13, J4.13
unnamed: J2.14, J4.14
unnamed: J2.15, J4.15
unnamed: J2.16, J4.16

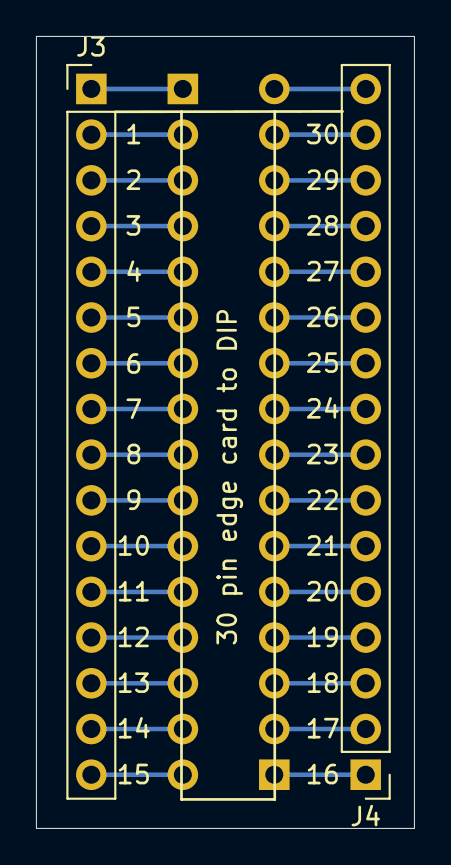
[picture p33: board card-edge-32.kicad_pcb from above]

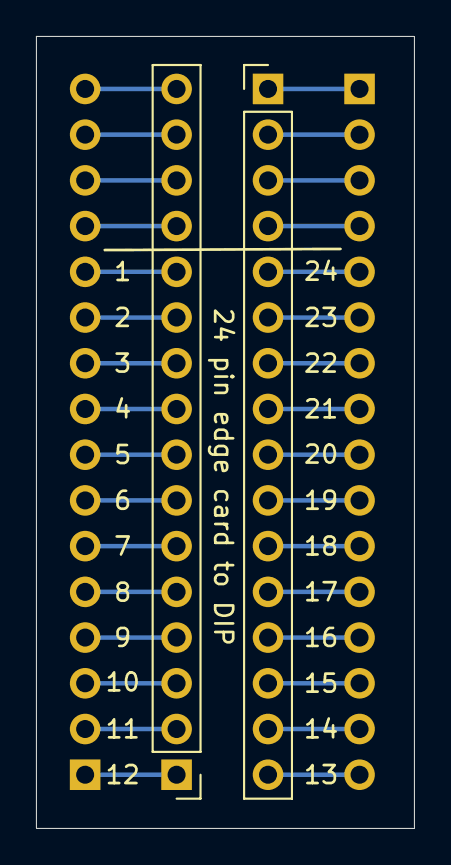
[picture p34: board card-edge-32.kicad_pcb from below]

Board: 2 copper layers, 21.0 x 44.0 mm, 4 parts (2 on the bottom side), 32 nets.

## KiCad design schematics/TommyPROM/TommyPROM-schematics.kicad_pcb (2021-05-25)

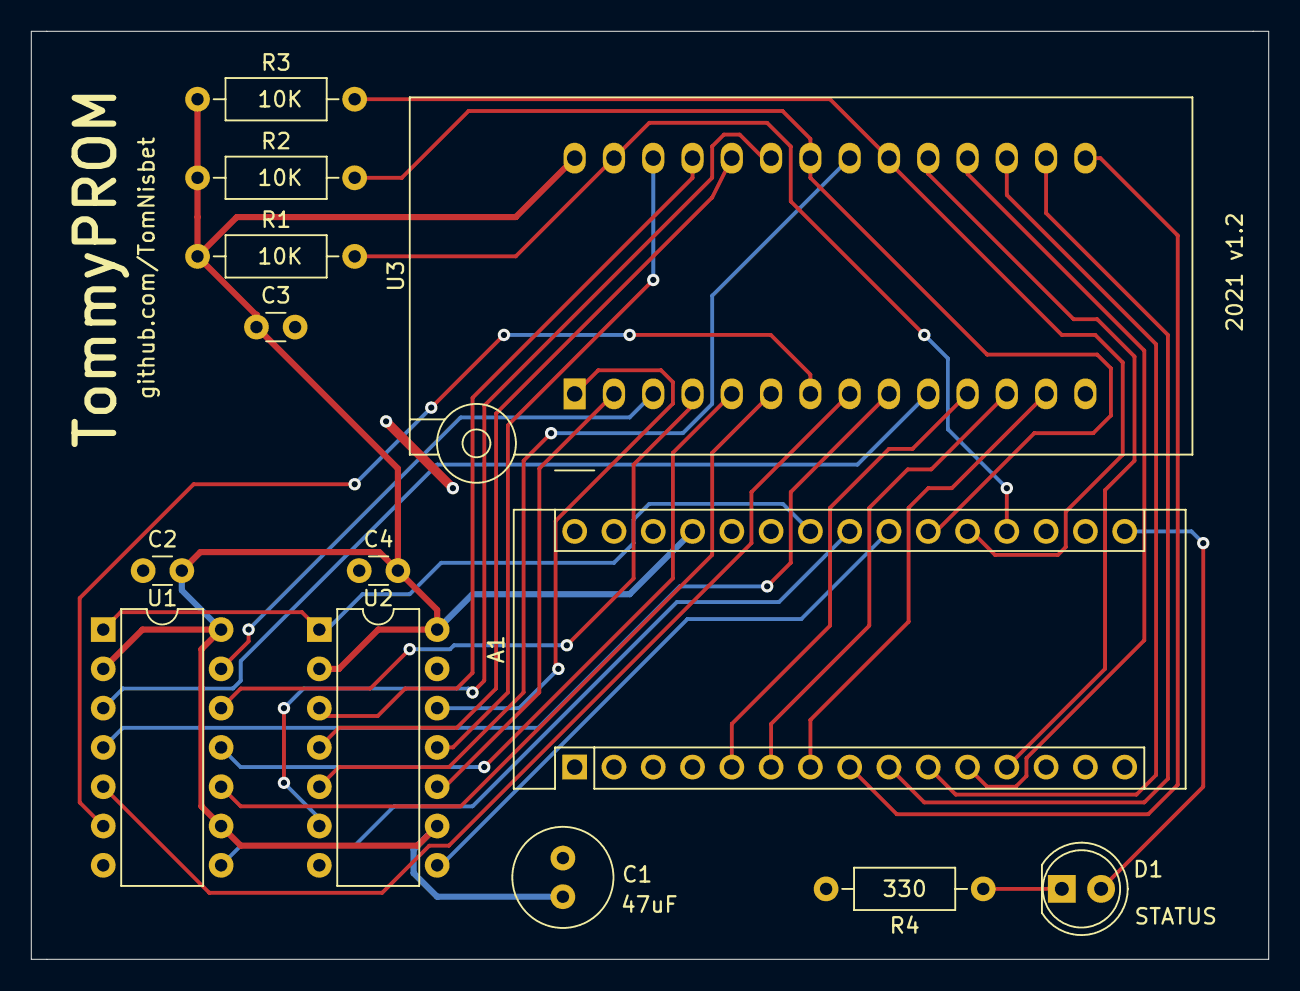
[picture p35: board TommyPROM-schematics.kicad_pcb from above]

Board: 2 copper layers, 80.0 x 60.0 mm, 13 parts (0 on the bottom side), 33 nets.

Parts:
A1: Arduino_Nano_v3.x; Arduino_Nano
C1: 47uF; C_Radial_D6.3mm_H11.0mm_P2.50mm
C2, C3, C4: 0.1uF; C_Disc_D3.0mm_W1.6mm_P2.50mm
D1: STATUS; LED_D5.0mm
R1, R2, R3: 10K; R_Axial_DIN0207_L6.3mm_D2.5mm_P10.16mm_Horizontal
R4: 330; R_Axial_DIN0207_L6.3mm_D2.5mm_P10.16mm_Horizontal
U1, U2: 74HCT164; DIP-14_W7.62mm
U3: 28C256; DIP_Socket-28_W11.9_W12.7_W15.24_W17.78_W18.5_3M_228-1277-0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

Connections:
/A0: U1.3, U3.10
/A1: U1.4, U3.9
/A2: U1.5, U3.8
/A3: U1.6, U3.7
/A4: U1.10, U3.6
/A5: U1.11, U3.5
/A6: U1.12, U3.4
/A7: U1.13, U3.3
/A8: U2.3, U3.25
/A9: U2.4, U3.24
/A10: U2.5, U3.21
/A11: U2.6, U3.23
/A12: U2.10, U3.2
/A13: U2.11, U3.26
/A14: U2.12, U3.1
/AD-BIT: A1.24, U1.1, U2.1
/CE: A1.20, R3.2, U3.20
/CLK-HI: A1.22, U2.8
/CLK-LO: A1.23, U1.8
/D0: A1.5, U3.11
/D1: A1.6, U3.12
/D2: A1.7, U3.13
/D3: A1.8, U3.15
/D4: A1.9, U3.16
/D5: A1.10, U3.17
/D6: A1.11, U3.18
/D7: A1.12, U3.19
/OE: A1.21, R2.2, U3.22
/WE: A1.19, R1.2, U3.27
GND: A1.4, A1.29, C1.2, C2.2, C3.2, C4.2, R4.2, U1.7, U2.7, U3.14
unnamed: A1.16, D1.2
unnamed: D1.1, R4.1
VCC: A1.27, C1.1, C2.1, C3.1, C4.1, R1.1, R2.1, R3.1, U1.2, U1.9, U1.14, U2.2, U2.9, U2.14, U3.28

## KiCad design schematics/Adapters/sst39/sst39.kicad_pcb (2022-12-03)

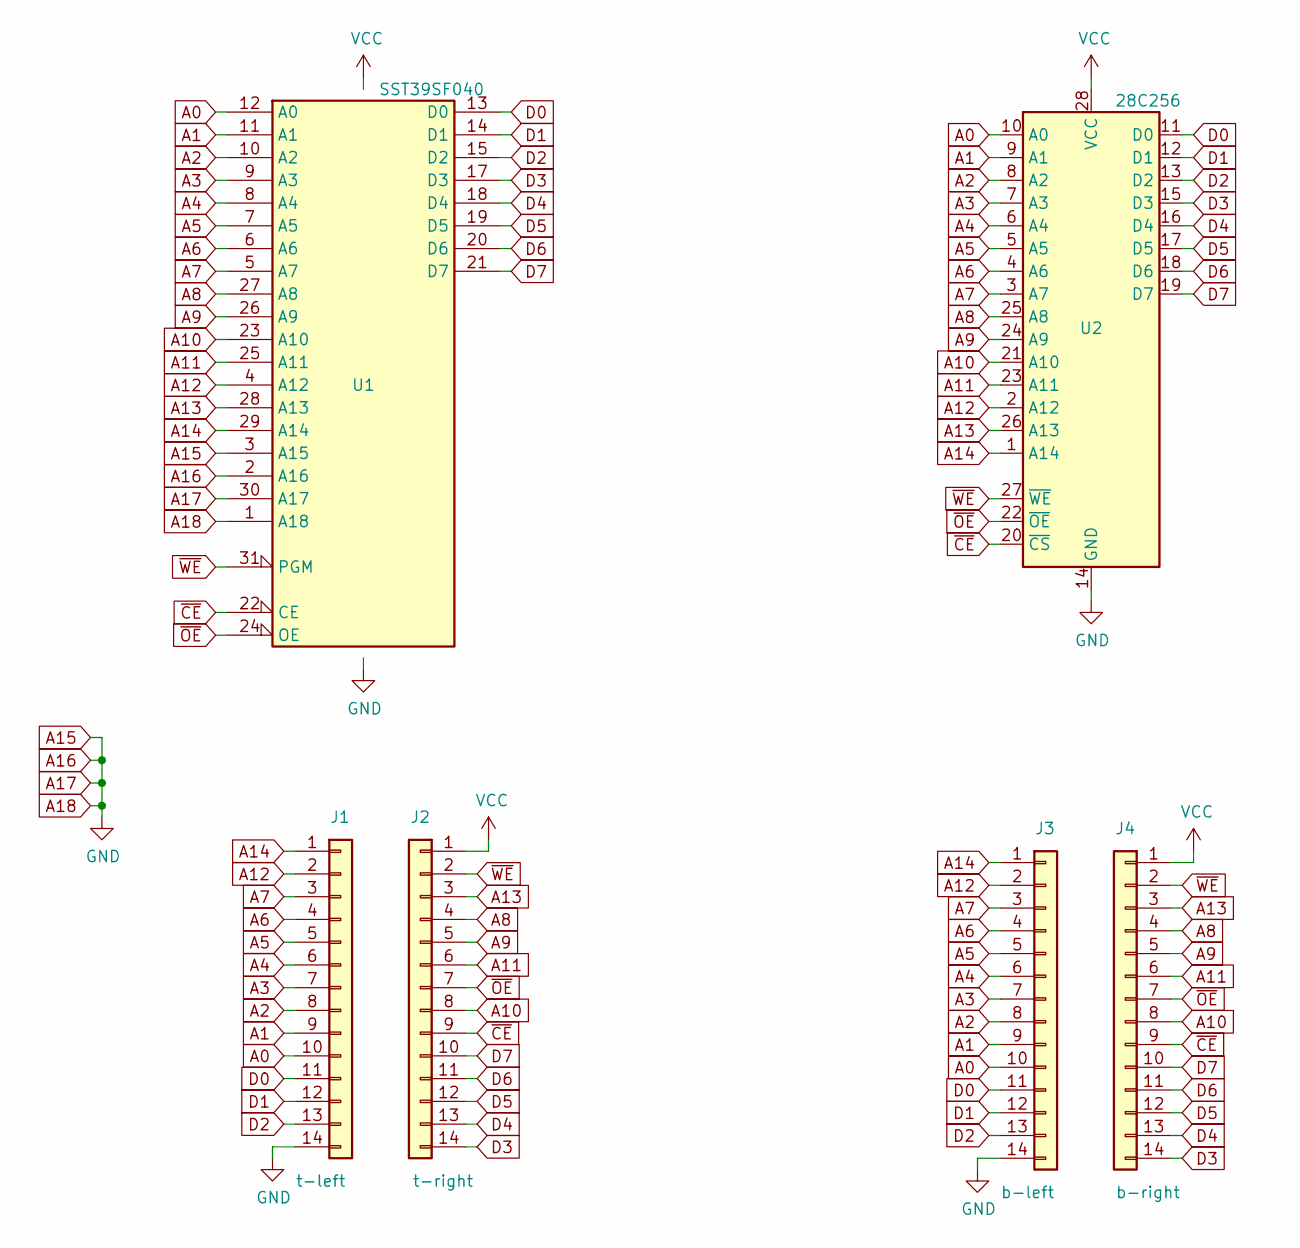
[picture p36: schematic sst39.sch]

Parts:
J1: t-left; PinHeader_1x14_P2.54mm_Vertical
J2: t-right; PinHeader_1x14_P2.54mm_Vertical
J3: b-left; PinSocket_1x14_P2.54mm_Vertical
J4: b-right; PinSocket_1x14_P2.54mm_Vertical
U1: SST39SF040; DIP-32_W15.24mm_Socket
U2: 28C256; DIP-28_W15.24mm

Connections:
A0: J1.10, J3.10, U1.12 (A0), U2.10 (A0)
A1: J1.9, J3.9, U1.11 (A1), U2.9 (A1)
A2: J1.8, J3.8, U1.10 (A2), U2.8 (A2)
A3: J1.7, J3.7, U1.9 (A3), U2.7 (A3)
A4: J1.6, J3.6, U1.8 (A4), U2.6 (A4)
A5: J1.5, J3.5, U1.7 (A5), U2.5 (A5)
A6: J1.4, J3.4, U1.6 (A6), U2.4 (A6)
A7: J1.3, J3.3, U1.5 (A7), U2.3 (A7)
A8: J2.4, J4.4, U1.27 (A8), U2.25 (A8)
A9: J2.5, J4.5, U1.26 (A9), U2.24 (A9)
A10: J2.8, J4.8, U1.23 (A10), U2.21 (A10)
A11: J2.6, J4.6, U1.25 (A11), U2.23 (A11)
A12: J1.2, J3.2, U1.4 (A12), U2.2 (A12)
A13: J2.3, J4.3, U1.28 (A13), U2.26 (A13)
A14: J1.1, J3.1, U1.29 (A14), U2.1 (A14)
A15: J1.14, J3.14, U1.1 (A18), U1.2 (A16), U1.3 (A15), U1.16 (GND), U1.30 (A17), U2.14 (GND)
D0: J1.11, J3.11, U1.13 (D0), U2.11 (D0)
D1: J1.12, J3.12, U1.14 (D1), U2.12 (D1)
D2: J1.13, J3.13, U1.15 (D2), U2.13 (D2)
D3: J2.14, J4.14, U1.17 (D3), U2.15 (D3)
D4: J2.13, J4.13, U1.18 (D4), U2.16 (D4)
D5: J2.12, J4.12, U1.19 (D5), U2.17 (D5)
D6: J2.11, J4.11, U1.20 (D6), U2.18 (D6)
D7: J2.10, J4.10, U1.21 (D7), U2.19 (D7)
VCC: J2.1, J4.1, U1.32 (VCC), U2.28 (VCC)
~CE: J2.9, J4.9, U1.22 (CE), U2.20 (~CS)
~OE: J2.7, J4.7, U1.24 (OE), U2.22 (~OE)
~WE: J2.2, J4.2, U1.31 (PGM), U2.27 (~WE)

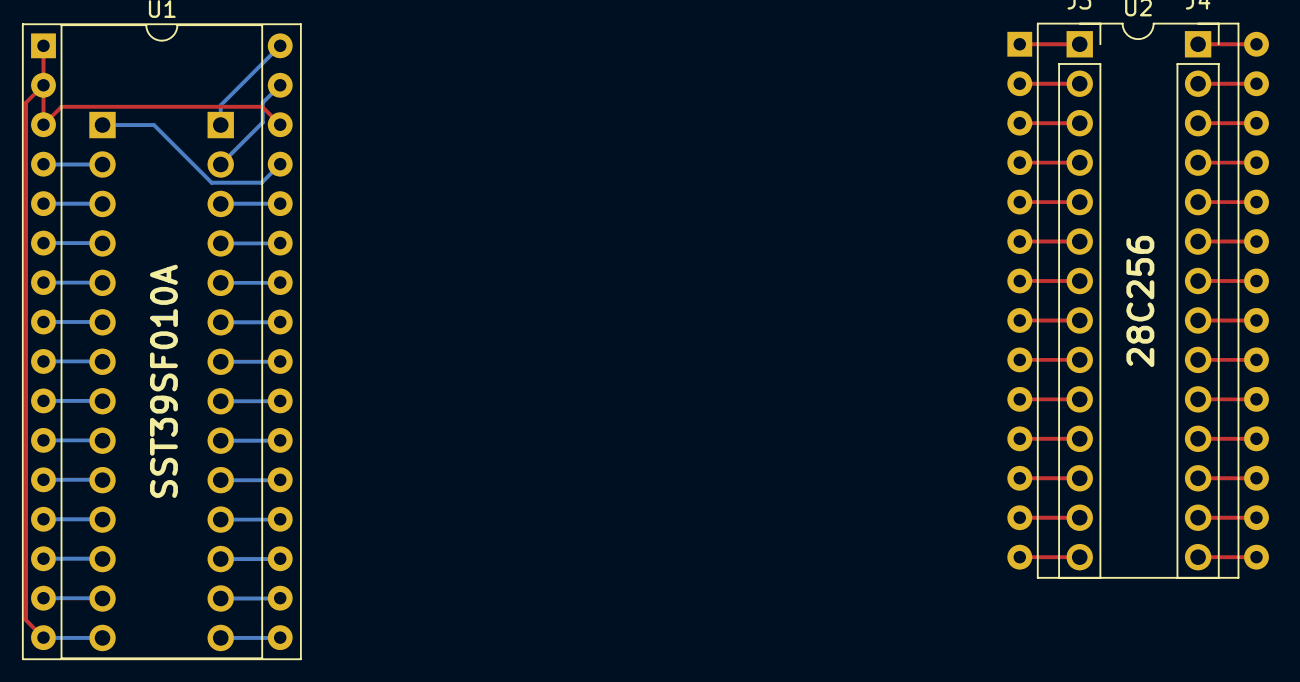
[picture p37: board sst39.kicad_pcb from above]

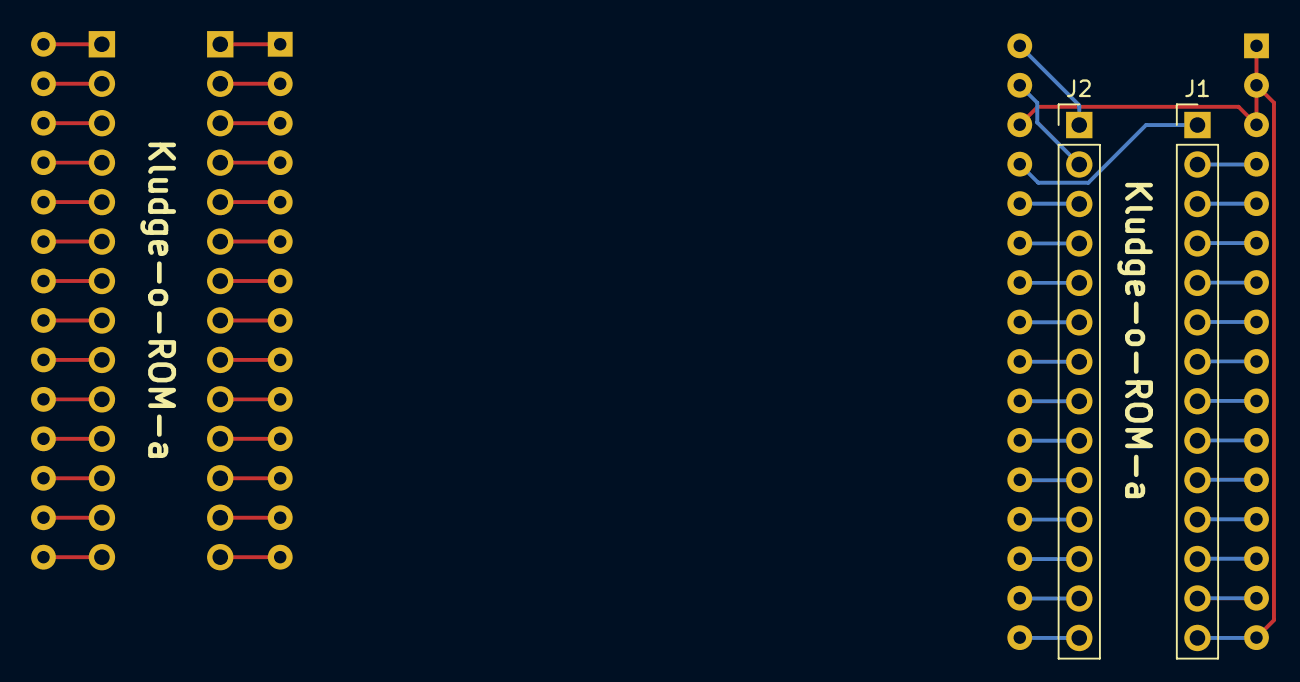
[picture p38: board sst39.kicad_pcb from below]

Board: 2 copper layers, 6 parts (2 on the bottom side), 28 nets.

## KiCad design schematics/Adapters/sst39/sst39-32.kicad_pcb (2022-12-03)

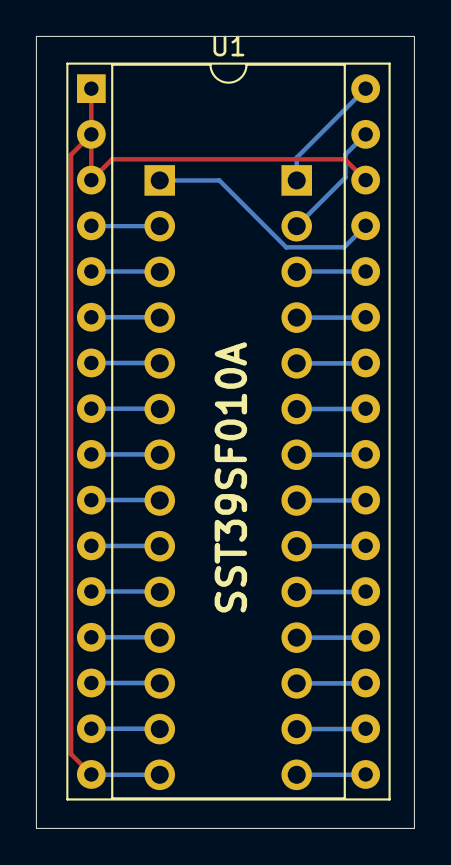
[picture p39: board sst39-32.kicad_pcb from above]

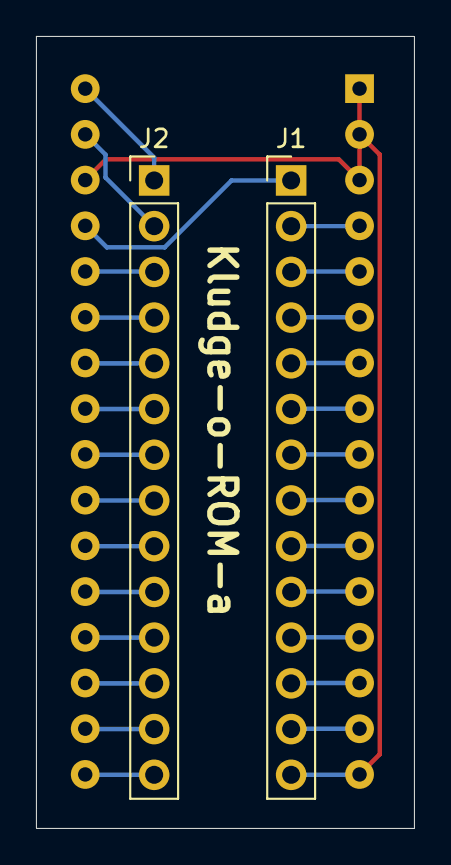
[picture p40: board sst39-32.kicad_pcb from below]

Board: 2 copper layers, 21.0 x 44.0 mm, 3 parts (2 on the bottom side), 28 nets.

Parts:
J1: t-left; PinHeader_1x14_P2.54mm_Vertical
J2: t-right; PinHeader_1x14_P2.54mm_Vertical
U1: SST39SF040; DIP-32_W15.24mm_Socket

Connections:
A0: J1.10, U1.12
A1: J1.9, U1.11
A2: J1.8, U1.10
A3: J1.7, U1.9
A4: J1.6, U1.8
A5: J1.5, U1.7
A6: J1.4, U1.6
A7: J1.3, U1.5
A8: J2.4, U1.27
A9: J2.5, U1.26
A10: J2.8, U1.23
A11: J2.6, U1.25
A12: J1.2, U1.4
A13: J2.3, U1.28
A14: J1.1, U1.29
A15: J1.14, U1.1, U1.2, U1.3, U1.16, U1.30
D0: J1.11, U1.13
D1: J1.12, U1.14
D2: J1.13, U1.15
D3: J2.14, U1.17
D4: J2.13, U1.18
D5: J2.12, U1.19
D6: J2.11, U1.20
D7: J2.10, U1.21
VCC: J2.1, U1.32
~CE: J2.9, U1.22
~OE: J2.7, U1.24
~WE: J2.2, U1.31

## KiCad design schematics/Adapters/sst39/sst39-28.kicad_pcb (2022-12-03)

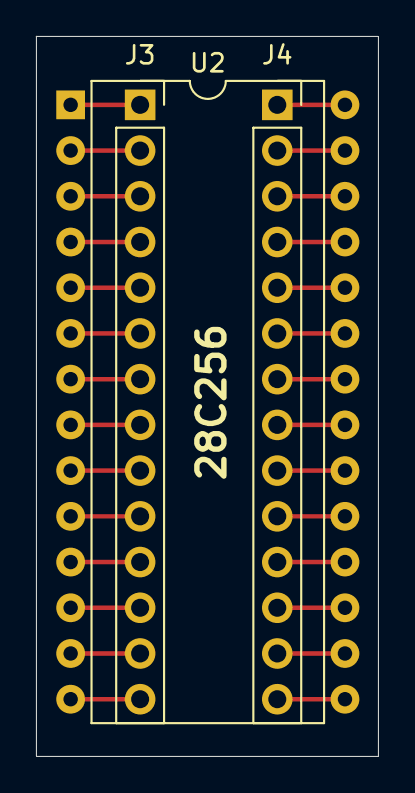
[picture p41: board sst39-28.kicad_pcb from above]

Board: 2 copper layers, 19.0 x 40.0 mm, 3 parts (0 on the bottom side), 28 nets.

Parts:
J3: b-left; PinSocket_1x14_P2.54mm_Vertical
J4: b-right; PinSocket_1x14_P2.54mm_Vertical
U2: 28C256; DIP-28_W15.24mm

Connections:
A0: J3.10, U2.10
A1: J3.9, U2.9
A2: J3.8, U2.8
A3: J3.7, U2.7
A4: J3.6, U2.6
A5: J3.5, U2.5
A6: J3.4, U2.4
A7: J3.3, U2.3
A8: J4.4, U2.25
A9: J4.5, U2.24
A10: J4.8, U2.21
A11: J4.6, U2.23
A12: J3.2, U2.2
A13: J4.3, U2.26
A14: J3.1, U2.1
A15: J3.14, U2.14
D0: J3.11, U2.11
D1: J3.12, U2.12
D2: J3.13, U2.13
D3: J4.14, U2.15
D4: J4.13, U2.16
D5: J4.12, U2.17
D6: J4.11, U2.18
D7: J4.10, U2.19
VCC: J4.1, U2.28
~CE: J4.9, U2.20
~OE: J4.7, U2.22
~WE: J4.2, U2.27

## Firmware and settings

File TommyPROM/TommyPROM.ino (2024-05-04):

/**
* Read and write parallel EEPROMS with an interctive command-line interface.
* Modules are available for ATMEL 28C series EEPROMs and Intel 8755A EPROMS.
* Many other parallel EPROM/EEPROMs can be read, but not written, using the
* 28C code.
*
* The 28C module supports block writes for better performance and
* Software Data Protection (SDP) unlocking.
*
* ROM images are moved to and from a host computer using XMODEM.  This is
* available in a number of terminal programs, such as TeraTerm and Minicom.
*
* The default hardware uses two 74LS164 shift registers as the low and
* high address registers.
**/

#include "Configure.h"
#include "CmdStatus.h"
#include "XModem.h"


static const char * MY_VERSION = "3.7";


// Global status
CmdStatus cmdStatus;


// Declare a global PROM device depending on the device type that is
// defined in Configure.h
#if defined(PROM_IS_28C)
// Define a device for a 28C256 EEPROM with the following parameters:
//   32K byte device capacity
//   64 byte block writes
//   10ms max write time
//   Data polling supported
PromDevice28C  prom(32 * 1024L, 64, 10, true);
//PromDevice28C  prom(8 * 1024L, 0, 10, true);  // 28C64 with no page writes
//PromDevice28C  prom(2 * 1024L, 0, 10, true);  // 28C16 with no page writes

#elif defined(PROM_IS_27)
// Define a device for a 2764 EPROM with the following parameters:
//   8K byte device capacity
//   Program using dedicated WR pin
//   1000us (1ms) write pulse
//   Max 15 write attempts
//   4x overwrite pulse (4 * writePulseLength * numberOfPulsesWritten)
//   (true) verify data byte after writing
//PromDevice27  prom(8 * 1024L, E27C_PGM_WE, 1000L, 15, 4);  // 2764 with SEEQ intelligent programming
//PromDevice27  prom(32 * 1024L, E27C_PGM_WE, 1000L, 25, 3); // 27C256 with SEEQ intelligent programming
PromDevice27  prom(32 * 1024L, E27C_PGM_CE, 100L, 25, 0); // M27C256 with Presto II intelligent programming
//PromDevice27  prom(32 * 1024L, E27C_PGM_CE, 1000L, 25, 3); // M27256 with fast programming
//PromDevice27  prom(2 * 1024L, E27C_PGM_WE, 50000L, 1, 0);  // 2716 with single 50ms write
//PromDevice27  prom(512 * 1024L, E27C_PGM_CE, 100L, 11, 0); // 27C040 with Atmel rapid programming, CE connected to CE#/PGM#
//PromDevice27  prom(32 * 1024L, E27C_PGM_CE, 100L, 25, 0);  // W27C257/W27E257 with 100uS program pulse on CE
//PromDevice27  prom(64 * 1024L, E27C_PGM_CE, 100L, 1, 0, false);  // W27C512 with single 100uS program pulse on CE, no verify
//PromDevice27  prom(256 * 1024L, E27C_PGM_WE, 20L, 1, 0, false); // SST27SF020 with single 20us write, no verify

#elif defined(PROM_IS_SST39SF)
// Define a device for anSST39SF Flash with the following parameters:
//   512K byte device capacity
//   10us max write time
//   Data polling supported
//PromDeviceSST39SF  prom(128 * 1024L, 10, true);  // SST39SF010
//PromDeviceSST39SF  prom(256 * 1024L, 10, true);  // SST39SF020
PromDeviceSST39SF  prom(512 * 1024L, 10, true);  // SST39SF040

#elif defined(PROM_IS_SST28SF)
// Define a device for anSST28SF Flash with the following parameters:
//   512K byte device capacity
//   40us max write time
//   Data polling supported
PromDeviceSST28SF  prom(512 * 1024L, 40, true);

#elif defined(PROM_IS_8755A)
// Define a device for an Intel 8755A with a fixed size of 2K and no other parameters.
PromDevice8755A  prom(2 * 1024L);

#elif defined(PROM_IS_23)
PromDevice23 prom(2 * 1024L);   // 2316

// Additional device-specific code goes here...
//#elif defined(PROM_IS...

#else
#error "Must define a PROM type in Configure.h"
#endif


// Global XModem driver
XModem xmodem(prom, cmdStatus);


/*****************************************************************************/
/*****************************************************************************/

/**
 * CLI parse functions
 */
const char hex[] = "0123456789abcdef";
const uint32_t unspec = ~0;
inline uint32_t if_unspec(uint32_t val, uint32_t repl) { return val == unspec? repl: val; }

enum {
    // CLI Commands
    CMD_INVALID,
    CMD_BLANK,
    CMD_CHECKSUM,
    CMD_DUMP,
    CMD_ERASE,
    CMD_FILL,
    CMD_INFO,
    CMD_LOCK,
    CMD_POKE,
    CMD_READ,
    CMD_UNLOCK,
    CMD_WRITE,
    CMD_ZAP,

    CMD_SCAN,
    CMD_TEST,
    CMD_PATTERN_FILL,
    CMD_LAST_STATUS
};


// Read a line of data from the serial connection.
char * readLine(char * buffer, int len)
{
    for (int ix = 0; (ix < len); ix++)
    {
         buffer[ix] = 0;
    }

    // read serial data until linebreak or buffer is full
    char c = ' ';
    int ix = 0;
    do {
        if (Serial.available())
        {
            c = Serial.read();
            if ((c == '\b') && (ix > 0))
            {
                // Backspace, forget last character
                --ix;
            }
            buffer[ix++] = c;
            Serial.write(c);
        }
    } while ((c != '\n') && (c != '\r') && (ix < len));

    buffer[ix - 1] = 0;
    return buffer;
}


byte parseCommand(char c)
{
    byte cmd = CMD_INVALID;

    // Convert the command to lowercase.
    if ((c >= 'A') && (c <= 'Z')) {
        c |= 0x20;
    }

    switch (c)
    {
        case 'b':  cmd = CMD_BLANK;     break;
        case 'c':  cmd = CMD_CHECKSUM;  break;
        case 'd':  cmd = CMD_DUMP;      break;
        case 'e':  cmd = CMD_ERASE;     break;
        case 'f':  cmd = CMD_FILL;      break;
        case 'i':  cmd = CMD_INFO;      break;
        case 'l':  cmd = CMD_LOCK;      break;
        case 'p':  cmd = CMD_POKE;      break;
        case 'r':  cmd = CMD_READ;      break;
        case 'u':  cmd = CMD_UNLOCK;    break;
        case 'w':  cmd = CMD_WRITE;     break;
        case 'z':  cmd = CMD_ZAP;       break;

        case 's':  cmd = CMD_SCAN;      break;
        case 't':  cmd = CMD_TEST;      break;
        case '!':  cmd = CMD_PATTERN_FILL;break;
        case '/':  cmd = CMD_LAST_STATUS; break;
        default:   cmd = CMD_INVALID;   break;
    }

    return cmd;
}




/************************************************************
* convert a single hex character [0-9a-fA-F] to its value
* @param char c single character (digit)
* @return byte value of the digit (0-15)
************************************************************/
byte hexDigit(char c)
{
    if ((c >= '0') && (c <= '9'))
    {
        return c - '0';
    }
    else if ((c >= 'a') && (c <= 'f'))
    {
        return c - 'a' + 10;
    }
    else if ((c >= 'A') && (c <= 'F'))
    {
        return c - 'A' + 10;
    }
    else
    {
        return 0xff;
    }
}

/************************************************************
* Convert a hex string to a uint32_t value.
* Skips leading spaces and terminates on the first non-hex
* character.  Leading zeroes are not required.
*
* No error checking is performed - if no hex is found then
* defaultValue is returned.  Similarly, a hex string of more than
* 8 digits will return the value of the last 8 digits.
* @param pointer to string with the hex value of the word (modified)
* @return unsigned int represented by the digits
************************************************************/
uint32_t getHex32(char *& pData, uint32_t defaultValue=unspec)
{
    uint32_t u32 = 0;

    while (isspace(*pData))
    {
        ++pData;
    }

    if (isxdigit(*pData))
    {
        while (isxdigit(*pData)) {
            u32 = (u32 << 4) | hexDigit(*pData++);
        }
    }
    else
    {
        u32 = defaultValue;
    }

    return u32;
}


void printByte(byte b)
{
    char line[3];

    line[0] = hex[b >> 4];
    line[1] = hex[b & 0x0f];
    line[2] = '\0';

    Serial.print(line);
}


void printWord(word w)
{
    char line[5];

    line[0] = hex[(w >> 12) & 0x0f];
    line[1] = hex[(w >>  8) & 0x0f];
    line[2] = hex[(w >>  4) & 0x0f];
    line[3] = hex[(w)       & 0x0f];
    line[4] = '\0';

    Serial.print(line);
}


/*
* Prints a 32 bit value as a hex.
*
* Note that no values over 5 digits are used in
* this appication, so only 5 digits are printed.*/
void printHex32(uint32_t u32)
{
    char line[6];

    line[0] = hex[(u32 >> 16) & 0x0f];
    line[1] = hex[(u32 >> 12) & 0x0f];
    line[2] = hex[(u32 >>  8) & 0x0f];
    line[3] = hex[(u32 >>  4) & 0x0f];
    line[4] = hex[(u32)       & 0x0f];
    line[5] = '\0';

    Serial.print(line);
}


// If the user presses a key then pause until they press another.  Return true if
// Ctrl-C is pressed.
bool checkForBreak()
{
    if (Serial.available())
    {
        if (Serial.read() == 0x03)
        {
            return true;
        }
        while (!Serial.available())
        {}
        if (Serial.read() == 0x03)
        {
            return true;
        }
    }

    return false;
}



/*****************************************************************************/
/*****************************************************************************/
/**
 * Command implementations
 */


/**
 * Compute a 16 bit checksum from PROM data
 *
 * Note that this always reads an even number of bytes from the
 * device and will read one byte beyond the specified end
 * address if an odd number of bytes is specified by start and
 * end.
 */
word checksumBlock(uint32_t start, uint32_t end)
{
    word checksum = 0;
#if 1
    for (uint32_t addr = start; (addr <= end); addr += 2)
    {
        word w = prom.readData(addr);
        w <<= 8;
        w |= prom.readData(addr + 1);
        checksum += w;
    }
#else
    uint16_t crc = 0xffff;
    for (uint32_t addr = start; (addr <= end); addr++)
    {
        crc = crc ^ (uint16_t(prom.readData(addr)) << 8);
        for (int ix = 0; (ix < 8); ix++)
        {
            if (crc & 0x8000)
            {
                crc = (crc << 1) ^ 0x1021;
            }
            else
            {
                crc <<= 1;
            }
        }
    }
    checksum = crc;
#endif

    return checksum;
}


/**
* Read data from the device and dump it in hex and ascii.
**/
uint32_t dumpBlock(uint32_t start, uint32_t end)
{
    char line[81];
//  01234567891 234567892 234567893 234567894 234567895 234567896 234567897 23456789
//  01234: 01 23 45 67  89 ab cf ef  01 23 45 67  89 ab cd ef  1.2.3.4. 5.6.7.8.
    int count = 0;

    memset(line, ' ', sizeof(line));

    char * pHex = line;
    char * pChar = line + 59;
    for (uint32_t addr = start; (addr <= end); addr++)
    {
        if (count == 0)
        {
            //print out the address at the beginning of the line
            pHex = line;
            pChar = line + 59;
            *pHex++ = hex[(addr >> 16) & 0x0f];
            *pHex++ = hex[(addr >> 12) & 0x0f];
            *pHex++ = hex[(addr >>  8) & 0x0f];
            *pHex++ = hex[(addr >>  4) & 0x0f];
            *pHex++ = hex[(addr)       & 0x0f];
            *pHex++ = ':';
            *pHex++ = ' ';
        }

        byte data = prom.readData(addr);
        *pHex++ = hex[data >> 4];
        *pHex++ = hex[data & 0x0f];
        *pHex++ = ' ';
        *pChar++ = ((data < 32) | (data >= 127)) ? '.' : data;

        if ((count & 3) == 3)
        {
            *pHex++ = ' ';
        }
        if ((count & 7) == 7)
        {
            *pChar++ = ' ';
        }
        if ((++count >= 16) || (addr == end))
        {
            *pChar = '\0';
            Serial.println(line);
            if (checkForBreak())
            {
                return addr;
            }
            memset(line, ' ', sizeof(line));
            count = 0;
        }
    }

    if (count)
    {
        Serial.println();
    }

    return end+1;
}


/**
 * Fill a block of PROM data with a single value.
 *
 * @param start - start address
 * @param end - end address
 * @param val - data byte to write to all addresses
 */
void fillBlock(uint32_t start, uint32_t end, byte val)
{
    enum { BLOCK_SIZE = 32 };
    byte block[BLOCK_SIZE];

    for (int ix = 0; ix < BLOCK_SIZE; ix++)
    {
        block[ix] = val;
    }

    for (uint32_t addr = start; (addr <= end); addr += BLOCK_SIZE)
    {
        uint32_t writeLen = ((end - addr + 1) < BLOCK_SIZE) ? (end - addr + 1) : uint32_t(BLOCK_SIZE);
        if (!prom.writeData(block, writeLen, addr))
        {
            cmdStatus.error("Write failed");
            return;
        }
    }
}


/**
 * Verify that a block of PROM contains the all FF erased value.
 *
 * @param start - start address
 * @param end - end address
 */
void erasedBlockCheck(uint32_t start, uint32_t end)
{
    for (uint32_t addr = start; (addr <= end); addr ++)
    {
        byte val = prom.readData(addr);
        if (val != 0xff)
        {
            cmdStatus.error("Block is not erased");
            cmdStatus.setValueHex(0, "addr", addr);
            cmdStatus.setValueHex(1, "value", val);
            return;
        }
    }
    cmdStatus.info("Block is erased");
}


/**
 * Write a series of bytes from the command line to the PROM.
 *
 * @param cursor - pointer to command line text
 */
void pokeBytes(char * pCursor)
{
    uint32_t val;
    uint32_t start;
    unsigned byteCtr = 0;

    enum { BLOCK_SIZE = 32 };
    byte data[BLOCK_SIZE];

    //first value returned is the starting address
    start = getHex32(pCursor, 0);

    while (((val = getHex32(pCursor)) != unspec) && (byteCtr < BLOCK_SIZE))
    {
        data[byteCtr++] = byte(val);
    }

    if (byteCtr > 0)
    {
        if (!prom.writeData(data, byteCtr, start))
        {
            cmdStatus.error("Write failed");
            return;
        }
    }
    else
    {
        cmdStatus.error("Missing address or data");
        return;
    }
    delay(100);

    if (!prom.is_readback_safe()) {
        // This chip uses the CE line for write control, so don't do the read because it
        // could cause a write operation that would corrupt the data.
        cmdStatus.info("Poke complete");
        return;
    }

    for (unsigned ix = 0; ix < byteCtr ; ix++)
    {
        byte val = prom.readData(start + ix);
        if (val != data[ix])
        {
            cmdStatus.error("Verify failed");
            cmdStatus.setValueHex(0, "addr", start + ix);
            cmdStatus.setValueHex(1, "read", val);
            cmdStatus.setValueHex(2, "expected", data[ix]);
            return;
        }
    }
    cmdStatus.info("Poke successful");
}


/**
 * Write a 32 byte test pattern to the PROM device and verify it
 * by reading back.  The pattern includes a walking 1 and a
 * walking zero, which may help to detect pins that are tied
 * together or swapped.
 *
 * @param start - start address
 */
void zapTest(uint32_t start)
{
    byte testData[] =
    {
        'A',  'B',  'C',  'D',  'E',  'F',  'G',  'H',
        0x01, 0x02, 0x04, 0x08, 0x10, 0x20, 0x40, 0x80,
        0x7f, 0xbf, 0xdf, 0xef, 0xf7, 0xfb, 0xfd, 0xfe,
        0x00, 0xff, 0x55, 0xaa, '0',  '1',  '2',  '3'
    };

    if (!prom.writeData(testData, sizeof(testData), start))
    {
        cmdStatus.error("Write failed");
        return;
    }

    delay(100);

    if (!prom.is_readback_safe()) {
        // This chip uses the CE line for write control, so don't do the read because it
        // could cause a write operation that would corrupt the data.
        cmdStatus.info("Write test complete");
        return;
    }

    for (unsigned ix = 0; ix < sizeof(testData); ix++)
    {
        byte val = prom.readData(start + ix);
        if (val != testData[ix])
        {
            cmdStatus.error("Verify failed");
            cmdStatus.setValueHex(0, "addr", start + ix);
            cmdStatus.setValueHex(1, "read", val);
            cmdStatus.setValueHex(2, "expected", testData[ix]);
            return;
        }
    }
    cmdStatus.info("Write test successful");
}


void printRetStatus(ERET status)
{
    switch (status) {
    case RET_OK:          Serial.println(F("OK"));              break;
    case RET_FAIL:        Serial.println(F("FAILED"));          break;
    case RET_NOT_SUPPORT: Serial.println(F("NOT SUPPORTED"));   break;
    }
}
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
void loop()
{
    uint32_t w;
    uint32_t numBytes;

    Serial.print("\n>");
    Serial.flush();
    readLine(line, sizeof(line));
    Serial.println();
    byte cmd = parseCommand(line[0]);
    char * pCursor = line+1;
    uint32_t start = getHex32(pCursor);
    uint32_t end = getHex32(pCursor);
    uint32_t val = getHex32(pCursor);
    static uint32_t dump_next = 0;

    if ((cmd != CMD_LAST_STATUS) && (cmd != CMD_INVALID))
    {
        cmdStatus.clear();
    }

    switch (cmd)
    {
    case CMD_BLANK:
        erasedBlockCheck(if_unspec(start, 0), if_unspec(end, prom.end()));
        break;

    case CMD_CHECKSUM:
        start = if_unspec(start, 0);
        end = if_unspec(end, prom.end());
        w = checksumBlock(start, end);
        Serial.print(F("Checksum "));
        printWord(start);
        Serial.print(F("-"));
        printWord(end);
        Serial.print(F(" = "));
        printWord(w);
        Serial.println();
        break;

    case CMD_DUMP:
        start = if_unspec(start, dump_next);
        dump_next = dumpBlock(start, if_unspec(end, start + 0xff));
        break;

    case CMD_ERASE:
        if (start == unspec || end == unspec)
        {
            Serial.println(F("Erase requires explicit start, end"));
        }
        else
        {
            printRetStatus(prom.erase(start, end));
        }
        break;

    case CMD_FILL:
        if (start == unspec || end == unspec || val == unspec)
        {
            Serial.println(F("Fill requires explicit start, end and value"));
        }
        else
        {
            prom.resetDebugStats();
            fillBlock(start, end, (byte)val);
        }
        break;

    case CMD_INFO:
        prom.printDebugStats();
        break;

    case CMD_LOCK:
        Serial.print(F("Writing the lock code to enable Software Write Protect mode: "));
        printRetStatus(prom.enableSoftwareWriteProtect());
        break;

    case CMD_POKE:
        prom.resetDebugStats();
        pokeBytes(line+1);
        break;

    case CMD_READ:
        start = if_unspec(start, 0);
        end = if_unspec(end, prom.end());
        if (xmodem.SendFile(start, end - start + 1))
        {
            cmdStatus.info("Send complete.");
            cmdStatus.setValueDec(0, "NumBytes", end - start + 1);
        }
        break;

    case CMD_UNLOCK:
        Serial.print(F("Writing the unlock code to disable Software Write Protect mode: "));
        printRetStatus(prom.disableSoftwareWriteProtect());
        break;

    case CMD_WRITE:
        prom.resetDebugStats();
        start = if_unspec(start, 0);
        numBytes = xmodem.ReceiveFile(start);
        if (numBytes)
        {
            cmdStatus.info("Success writing to EEPROM device.");
            cmdStatus.setValueDec(0, "NumBytes", numBytes);
        }
        else
        {
            xmodem.Cancel();
        }
        break;

    case CMD_ZAP:
        prom.resetDebugStats();
        zapTest(if_unspec(start, 0));
        break;

#ifdef ENABLE_DEBUG_COMMANDS
    case CMD_SCAN:
        scanBlock(if_unspec(start, 0), if_unspec(end, prom.end()));
        break;

    case CMD_TEST:
        testAddr(if_unspec(start, 0));
        break;

    case CMD_PATTERN_FILL:
        patternFill();
        break;
#endif /* ENABLE_DEBUG_COMMANDS */

    case CMD_LAST_STATUS:
        Serial.println(F("Status of last command:"));
        break;

    default:
        Serial.print(F("TommyPROM "));
        Serial.print(MY_VERSION);
        Serial.print(F(" - "));
        Serial.println(prom.getName());
        Serial.println();
        Serial.println(F("Valid commands are:"));
        Serial.println(F("  Bsssss eeeee    - Check to see if device range is Blank/erased (all FF)"));
        Serial.println(F("  Csssss eeeee    - Compute Checksum from device"));
        Serial.println(F("  Dsssss eeeee    - Dump bytes from device to terminal"));
        Serial.println(F("  Esssss eeeee    - Erase address range on device (needed for some Flash)"));
        Serial.println(F("  Fsssss eeeee dd - Fill block on device with fixed value"));
        Serial.println(F("  I               - Print debug Info"));
        Serial.println(F("  L               - Lock (enable) device Software Data Protection"));
        Serial.println(F("  Psssss dd dd... - Poke (write) values to device (up to 32 values)"));
        Serial.println(F("  Rsssss eeeee    - Read from device and save to XMODEM CRC file"));
        Serial.println(F("  U               - Unlock (disable) device Software Data Protection"));
        Serial.println(F("  Wsssss          - Write to device from XMODEM CRC file"));
        Serial.println(F("  Zsssss          - Zap (burn) a 32 byte test pattern"));
#ifdef ENABLE_DEBUG_COMMANDS
        Serial.println();
        Serial.println(F("  Ssssss eeeee    - Scan addresses (read each 10x)"));
        Serial.println(F("  Tsssss          - Test read address (read 100x)"));
        Serial.println(F("  !               - Fill entire device with a test pattern"));
#endif /* ENABLE_DEBUG_COMMANDS */
        break;
    }

    if (!cmdStatus.isClear() || (cmd == CMD_LAST_STATUS))
    {
        Serial.println();
        cmdStatus.printStatus();
    }
}

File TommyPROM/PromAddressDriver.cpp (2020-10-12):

// This controls the shift register that generates the address lines for A0..A15 for most
// chip families.  This is not used by the PromDevice8755A code.
//
// Note that this uses direct port control instead of digitalWrite calls so that the code
// can run fast enough to meet the tBLC requirements for SDP and block writes.  This
// sacrifices portability and readability for speed. //
//
// This code will only work on Arduino Uno and Nano hardware.  The ports for other
// Arduinos map to different IO pins.

#include "PromAddressDriver.h"

#define ADDR_CLK_HI     A3
#define ADDR_CLK_LO     A4
#define ADDR_DATA       A5

// Define masks for the address clk and data lines on PC3..PC5 for direct port control.
#define ADDR_CLK_HI_MASK    0x08
#define ADDR_CLK_LO_MASK    0x10
#define ADDR_DATA_MASK      0x20

// For larger ROMs, address lines A16..A18 are controlled by D10..D12 (PB2..PB4).
#define UPPER_ADDR_MASK     0x1c

// When using the 74LS595 shift registers, the RCLK lines of both shift registers can be
// connected to D13 (PB5).  Uncomment the #define SHIFT_REGISTER_IS_595 in Configure.h to
// enable the code for this.
#define RCLK_595_MASK       0x20


void PromAddressDriver::begin()
{
    // The address control pins are always outputs.
    pinMode(ADDR_DATA, OUTPUT);
    pinMode(ADDR_CLK_LO, OUTPUT);
    pinMode(ADDR_CLK_HI, OUTPUT);
    digitalWrite(ADDR_DATA, LOW);
    digitalWrite(ADDR_CLK_LO, LOW);
    digitalWrite(ADDR_CLK_HI, LOW);
    DDRB |= UPPER_ADDR_MASK | RCLK_595_MASK; // Set D10..D13 as outputs

    // To save time, the setAddress only writes the hi byte if it has changed.
    // The value used to detect the change is initialized to a non-zero value,
    // so set an initial address to avoid the the case where the first address
    // written is the 'magic' initial address.
    setAddress(0x0000);
}


// Set a 16 bit address in the two address shift registers and
// the upper bits on the extened address pins.
void PromAddressDriver::setAddress(uint32_t address)
{
    static byte lastHi = 0xca;
    static byte lastUpper = 0xca;
    byte upper = (address >> 16) & 0xff;
    byte hi = (address >> 8) & 0xff;
    byte lo = address & 0xff;

    if (upper != lastUpper)
    {
        setUpperAddress(upper);
        lastUpper = upper;
    }
    if (hi != lastHi)
    {
        setAddressRegister(ADDR_CLK_HI, hi);
        lastHi = hi;
    }
    setAddressRegister(ADDR_CLK_LO, lo);
}


void PromAddressDriver::setUpperAddress(byte addr)
{
    // Set the upper address on pins D10..D12.
    PORTB = (PORTB & ~UPPER_ADDR_MASK) | ((addr << 2) & UPPER_ADDR_MASK);
}


// Shift an 8-bit value into one of the address shift registers.  Note that
// the data pins are tied together, selecting the high or low address register
// is a matter of using the correct clock pin to shift the data in.
void PromAddressDriver::setAddressRegister(uint8_t clkPin, byte addr)
{
    byte mask = 0;
    if (clkPin == ADDR_CLK_HI)
        mask = ADDR_CLK_HI_MASK;
    else if (clkPin == ADDR_CLK_LO)
        mask = ADDR_CLK_LO_MASK;

    // Make sure the clock is low to start.
    PORTC &= ~mask;

    // Shift 8 bits in, starting with the MSB.
    for (int ix = 0; (ix < 8); ix++)
    {
        // Set the data bit
        if (addr & 0x80)
        {
            PORTC |= ADDR_DATA_MASK;
        }
        else
        {
            PORTC &= ~ADDR_DATA_MASK;
        }

        // Toggle the clock high then low
        PORTC |= mask;
        delayMicroseconds(3);
        PORTC &= ~mask;
        addr <<= 1;
    }

    // Toggle the RCLK pin to output the data for 74LS595 shift registers.  This pin is
    // not connected when using 74LS164 shift registers.
    PORTB &= ~RCLK_595_MASK;
    delayMicroseconds(1);
    PORTB |= RCLK_595_MASK;
    delayMicroseconds(1);
    PORTB &= ~RCLK_595_MASK;
}

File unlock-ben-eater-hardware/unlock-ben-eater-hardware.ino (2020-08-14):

// Utility to unlock 28C256 Software Data Protection (SDP) for the Ben Eater EEPROM
// programmer design.  This hardware is similar to the TommyPROM hardware, but it uses
// different shift register chips and different pin assignments.
//
// To meet the timing requirements of the SDP unlock, this code uses direct port writes
// to set and read values on the data bus.  It will work Arduino Uno and Nano hardware,
// but would require changes for other platforms.
#define SHIFT_DATA 2
#define SHIFT_CLK 3
#define SHIFT_LATCH 4
#define WRITE_EN 13


// 32 byte test pattern to verify the EEPROM device.  The pattern includes a walking one
// and a walking zero, which may help to detect pins that are tied together or swapped.
byte data[] = {
    'A',  'B',  'C',  'D',  'E',  'F',  'G',  'H',
    0x01, 0x02, 0x04, 0x08, 0x10, 0x20, 0x40, 0x80,
    0x7f, 0xbf, 0xdf, 0xef, 0xf7, 0xfb, 0xfd, 0xfe,
    0x00, 0xff, 0x55, 0xaa, '0',  '1',  '2',  '3'
};

void enableWrite()      { digitalWrite(WRITE_EN, LOW);}
void disableWrite()     { digitalWrite(WRITE_EN, HIGH);}

void setup() {
    // put your setup code here, to run once:
    pinMode(SHIFT_DATA, OUTPUT);
    pinMode(SHIFT_CLK, OUTPUT);
    pinMode(SHIFT_LATCH, OUTPUT);
    disableWrite();
    pinMode(WRITE_EN, OUTPUT);
    Serial.begin(57600);

    Serial.print("\nDisabling EEPROM Software Data Protection(SDP)...");
    disableSoftwareWriteProtect();
    Serial.println(" done\n");

    // Program a test pattern and fill the remainder of the first block with 0xff
    Serial.print("Programming EEPROM...");
    for (word address = 0; (address < sizeof(data)); address++) {
        writeEEPROM(address, data[address]);
    }
    for (word address = sizeof(data); (address < 256); address++) {
        writeEEPROM(address, 0xff);
    }
    Serial.println(" done\n");

    // Read and print out the contents of the EERPROM
    Serial.println("Reading EEPROM");
    printContents();
}

void loop() {
}


// Output the address bits and outputEnable signal using shift registers.
void setAddress(int addr, bool outputEnable) {
    // Set the highest bit as the output enable bit (active low)
    if (outputEnable) {
        addr &= ~0x8000;
    } else {
        addr |= 0x8000;
    }
    byte dataMask = 0x04;
    byte clkMask = 0x08;
    byte latchMask = 0x10;

    // Make sure the clock is low to start.
    PORTD &= ~clkMask;

    // Shift 16 bits in, starting with the MSB.
    for (uint16_t ix = 0; (ix < 16); ix++)
    {
        // Set the data bit
        if (addr & 0x8000)
        {
            PORTD |= dataMask;
        }
        else
        {
            PORTD &= ~dataMask;
        }

        // Toggle the clock high then low
        PORTD |= clkMask;
        delayMicroseconds(3);
        PORTD &= ~clkMask;
        addr <<= 1;
    }

    // Latch the shift register contents into the output register.
    PORTD &= ~latchMask;
    delayMicroseconds(1);
    PORTD |= latchMask;
    delayMicroseconds(1);
    PORTD &= ~latchMask;
}



// Read a byte from the EEPROM at the specified address.
byte readEEPROM(int address) {
    setDataBusMode(INPUT);
    setAddress(address, /*outputEnable*/ true);
    return readDataBus();
}

// Write a byte to the EEPROM at the specified address.
void writeEEPROM(int address, byte data) {
    setAddress(address, /*outputEnable*/ false);
    setDataBusMode(OUTPUT);
    writeDataBus(data);
    enableWrite();
    delayMicroseconds(1);
    disableWrite();
    delay(10);
}

// Read the first 256 byte block of the EEPROM and dump it to the serial monitor.
void printContents() {
    for (int base = 0; (base < 256); base += 16) {
        byte data[16];
        for (int offset = 0; offset <= 15; offset += 1) {
            data[offset] = readEEPROM(base + offset);
        }

        char buf[80];
        sprintf(buf, "%04x:  %02x %02x %02x %02x %02x %02x %02x %02x   %02x %02x %02x %02x %02x %02x %02x %02x",
            base, data[0], data[1], data[2], data[3], data[4], data[5], data[6], data[7],
            data[8], data[9], data[10], data[11], data[12], data[13], data[14], data[15]);
        Serial.println(buf);
    }
}

// Write the special six-byte code to turn off Software Data Protection.
void disableSoftwareWriteProtect() {
    disableWrite();
    setDataBusMode(OUTPUT);

    setByte(0xaa, 0x5555);
    setByte(0x55, 0x2aaa);
    setByte(0x80, 0x5555);
    setByte(0xaa, 0x5555);
    setByte(0x55, 0x2aaa);
    setByte(0x20, 0x5555);

    setDataBusMode(INPUT);
    delay(10);
}

// Write the special three-byte code to turn on Software Data Protection.
void enableSoftwareWriteProtect() {
    disableWrite();
    setDataBusMode(OUTPUT);

    setByte(0xaa, 0x5555);
    setByte(0x55, 0x2aaa);
    setByte(0xa0, 0x5555);

    setDataBusMode(INPUT);
    delay(10);
}

// Set the I/O state of the data bus.
// The 8 bits data bus are is on pins D5..D12.
void setDataBusMode(uint8_t mode) {
    // On the Uno and Nano, D5..D12 maps to the upper 3 bits of port D and the
    // lower 5 bits of port B.
    if (mode == OUTPUT) {
        DDRB |= 0x1f;
        DDRD |= 0xe0;
    } else {
        DDRB &= 0xe0;
        DDRD &= 0x1f;
    }
}

// Read a byte from the data bus.  The caller must set the bus to input_mode
// before calling this or no useful data will be returned.
byte readDataBus() {
    return (PINB << 3) | (PIND >> 5);
}

// Write a byte to the data bus.  The caller must set the bus to output_mode
// before calling this or no data will be written.
void writeDataBus(byte data) {
     PORTB = (PORTB & 0xe0) | (data >> 3);
     PORTD = (PORTD & 0x1f) | (data << 5);
}

// Set an address and data value and toggle the write control.  This is used
// to write control sequences, like the software write protect.  This is not a
// complete byte write function because it does not set the chip enable or the
// mode of the data bus.
void setByte(byte value, word address) {
    setAddress(address, false);
    writeDataBus(value);

    delayMicroseconds(1);
    enableWrite();
    delayMicroseconds(1);
    disableWrite();
}

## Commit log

2018-05-11 Move sketch to appropriately named subfolder
    The Arduino IDE requires that a sketch be located in a folder of the same name. Although the name of the repository does match the sketch name, when GitHub's popular Clone or download > Download ZIP 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
    When opening a file that does not meet this sketch/folder name matching requirement the Arduino IDE presents a dialog:
    The file "TommyPROM.ino" needs to be inside a sketch folder named "TommyPROM".
    Create this folder, move the file, and continue?
    After clicking "OK" the Arduino IDE currently moves only the file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
2018-05-17 Update power switching on 8755A schematic and add missing Eagle file
    [TommyPROM-8755A Nano.sch]
2018-12-20 Fix typo to define UNO platform
    [PromDevice.cpp]
2018-12-20 Fix pin assignments on 8755A device to match the schematic
    [PromDevice8755A.cpp]
2018-12-20 Fix schematic label errors and pin assignments on 8755A device to match the schematic
    [TommyPROM-8755A Nano.sch]
2018-12-22 Fix address error with 8755A burning
    [PromDevice8755A.cpp, TommyPROM.ino]
2019-06-09 Add lock command for 28C devices
2019-06-09 Print elapsed time for unlock in hardware verifier
2019-06-16 Optimize Address Register code for 28C timing requirements
    Also remove slower generic Arduino code so that the project is now tied
    to specific Arduino versions.
    Add readme for 28C chips.
2019-06-20 Add devices to 28C readme
2019-06-24 List devices in 28C readme
2020-01-30 Fixed not compiling when using 27xx profile
    I'm not sure if this is the correct fix but without this one line the code wouldn't compile and it would say that "data" wasn't declared.
    [PromDevice27.cpp]
2020-05-22 Fixes #8 - allow CR or LF as the terminal EOL character
    [TommyPROM.ino]
2020-06-29 fixes #11 - ASCII dump missing character
    [TommyPROM.ino]
2020-08-15 Fix #12 - add aemiller51's Poke command
    [TommyPROM.ino]
2020-08-24 Issue #13 - fix HWverify CLI parsing and update documentation.
    [HardwareVerify.ino]
2020-08-24 Issue #14 - consume the ACK to the xmodem EOT when sending files.
    [TommyPROM.ino, XModem.cpp]
2020-08-26 Fix #15 - typo in high address register pin definition.
    [PromAddressDriver.cpp, TommyPROM.ino]
2020-10-07 Add debug for XModem transfer failure
    [XModem.cpp]
2020-10-11 Fix #17 - pulse both CE and OE during the write verify cycle.
    [PromDevice.cpp, PromDevice28C.cpp, TommyPROM.ino]
2020-10-12 Fix #18 - addressing bug with 74LS595 shift registers
    [HardwareVerify.ino, PromAddressDriver.cpp]
2020-10-14 Fix #19 - XModem changed from 16-bit CRC to 8-bit checksum
    [TommyPROM.ino, XModem.cpp]
2020-11-14 Issue #20 - TeraTerm XModem file transfers with W command.
    [PromDevice.cpp, TommyPROM.ino, XModem.cpp]
2020-11-14 Note the connection of the 74LS595 G/OE pin
2021-04-30 redraw schematic in Kicad
2021-04-30 make schematic image a link
2021-05-05 pcb for review
2021-05-05 update pcb images
2021-05-05 v1.1 pcb images for review
2021-05-06 swap LED direction
2021-05-25 Add KiCad files
    [TommyPROM-schematics-B_Cu.gbl, TommyPROM-schematics-B_Mask.gbs, TommyPROM-schematics-B_SilkS.gbo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]
2021-05-27 add photo of the prototype 74LS595 build
2022-08-18 add PCB to documentation
2022-08-18 new photo of PCB version
2022-11-25 Remove unused methods; update PCB photo
2022-11-25 Add PCB page to prep for new board
2022-11-25 doc updates for PCB
2022-12-03 schematics for TommyPROM32 and adapters
    [TommyPROM32-B_Cu.gbl, TommyPROM32-B_Mask.gbs, TommyPROM32-B_SilkS.gbo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]
2022-12-10 device support for 27E257/27C257
2022-12-12 TommyPROM32 PCB docs
2023-01-20 V2.0 of the TommyPROM32 board
    [TommyPROM32-B_Cu.gbl, TommyPROM32-B_Mask.gbs, TommyPROM32-B_SilkS.gbo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]
2023-07-15 update PgmType for 27C040 EPROM
    The (AMD/Atmel) 27C040 EPROM doesn't have a dedicated Write Enable (WE),
    instead sharing the same pin for CE# and PGM#. This updates the PromDevice27
    line for this device to use the E27C_PGM_CE PgmType.
    This configuration has been successfully used to read, program and verify an
    AM27C040 device. A +12.75V voltage was applied to Vpp during the duration of
    device programming.
    [TommyPROM.ino]
2023-09-18 add TommyPROM32 schematic image
2023-09-19 update chip driver docs
2024-04-10 fix gotchas with unspecified start
    [TommyPROM.ino]
2024-04-10 fix from pr comment
    [TommyPROM.ino]
2024-04-13 Add dedicated 2316 page and TommyPROM32 page
    [TommyPROM-schematics-B_Cu.gbl, TommyPROM-schematics-B_Mask.gbs, TommyPROM-schematics-B_SilkS.gbo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]
2024-05-03 card edge connector schematic
    [card-edge-32.kicad_pcb, card-edge-32.sch]
2024-05-04 add M27256 to docs
    [card-edge-32.kicad_pcb]
2024-05-11 update device list
2024-06-09 TommyPROM32 pcb/sch adapted for use with 74xx595 registers
    [TommyPROM32-595.kicad_pcb, TommyPROM32-595.kicad_sch]
2024-06-20 Fix ERC errors due to missing no connect flags
    [TommyPROM32-595.kicad_pcb, TommyPROM32-595.kicad_sch]
2024-09-16 Update design-350-tommyprom32-pcb.md
    Typo in M27C256 description
